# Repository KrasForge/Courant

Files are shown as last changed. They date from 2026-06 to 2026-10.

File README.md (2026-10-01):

# RADIAN

<p align="center">
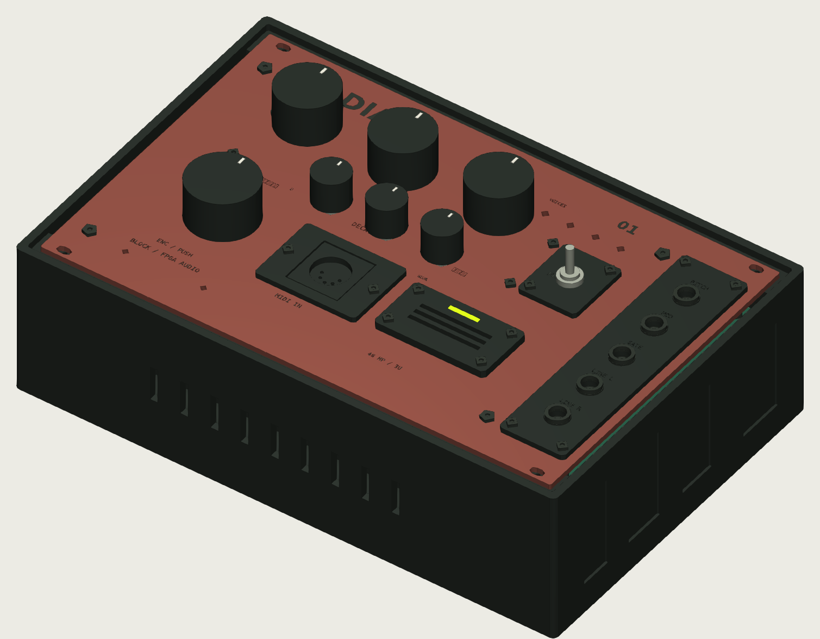
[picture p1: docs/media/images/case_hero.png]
RADIAN desktop instrument: six knobs, push encoder, MIDI DIN and five patch jacks on a red front panel in a black case
  
</p>

<p align="center">
  <a href="#listen"><b>Listen</b></a> ·
  <a href="#see-the-mesh-move"><b>See the mesh move</b></a> ·
  <a href="#the-hardware"><b>Hardware & 3D</b></a> ·
  <a href="#1-mathematical-foundation"><b>The maths</b></a> ·
  <a href="#4-architecture"><b>Architecture</b></a>
</p>

A 2D finite-difference physical-modeling synthesis engine in structural VHDL,
with an amplitude-dependent non-linear "chaos injection" term, playable
polyphonically over MIDI or CV.

Instead of recording or sampling an instrument, RADIAN solves the 2D acoustic
wave equation in real time on an FPGA mesh of arithmetic cells and streams the
result out as stereo audio: a vibrating drum head, a plate, a sheet of metal,
*computed* rather than recorded. A non-linear tension term makes the mesh
stiffen under load, so hard hits bend pitch upward and bloom into inharmonic,
metallic partials before settling into a natural decay. Notes arrive over MIDI
or control voltage, are allocated across independent polyphonic voices, and are
shaped by recallable instrument presets and a live front panel.

<sub>RADIAN was developed as **Courant**, which is why the repository and
some file paths still use that name.</sub>

> **Status: simulation-first, feature-complete in simulation, pre-hardware.**
> The engine, a Q1.23 reference model that is *bit-exact* to the RTL, and a full
> playable top (MIDI/CV $\rightarrow$ polyphony $\rightarrow$ I2S audio) are
> developed and verified under the current RTL regression across 31 testbenches. Board bring-up on a
> Digilent Arty A7 + Pmod I2S2 is the next step; nothing is claimed to work on
> hardware until it does.

---

## Listen

These clips come **out of the RTL**. A cycle-accurate Verilator build of
`synth_top` (4 voices, 8 $\times$ 8 mesh, 4$\times$ oversampling,
time-multiplexed) receives the score as bit-level serial MIDI at 31250 baud.
The note mapping, voice allocation, polyphonic meshes, mixer, DC blocker,
clock-domain crossing and I2S serialiser all run in it, and its 24-bit I2S
output is captured. Each clip gets one constant gain to peak at −1 dBFS. There
is no EQ, compression, reverb or editing. **They are not hardware
recordings**: the FPGA has not been brought up yet. Click a spectrogram or a ▶
link and the clip plays in your browser.

| Clip | What you hear | Listen |
| --- | --- | --- |
| **Gong Chorale** | A-minor chord progression on the gong preset. 3–4 voices ring into each other | [▶ `rtl_gong_chorale.mp3`](https://cdn.jsdelivr.net/gh/KrasForge/Courant@a1daff8e3a3599e712c28fc31fcfe1d983a12df5/docs/media/audio/rtl_gong_chorale.mp3) · 13 s |
| **Chaos Swell** | One held gong chord while CHAOS is turned up live over the control bus and back down | [▶ `rtl_chaos_swell.mp3`](https://cdn.jsdelivr.net/gh/KrasForge/Courant@a1daff8e3a3599e712c28fc31fcfe1d983a12df5/docs/media/audio/rtl_chaos_swell.mp3) · 12 s |
| **Plate Arpeggio** | Rolling pentatonic arpeggios on the plate preset with overlapping held notes, 112 BPM | [▶ `rtl_plate_arpeggio.mp3`](https://cdn.jsdelivr.net/gh/KrasForge/Courant@a1daff8e3a3599e712c28fc31fcfe1d983a12df5/docs/media/audio/rtl_plate_arpeggio.mp3) · 11 s |
| **Mallet Groove** | Marimba-like line on the damped drum preset over a held bass, 120 BPM | [▶ `rtl_mallet_groove.mp3`](https://cdn.jsdelivr.net/gh/KrasForge/Courant@a1daff8e3a3599e712c28fc31fcfe1d983a12df5/docs/media/audio/rtl_mallet_groove.mp3) · 10 s |
| **Berlin Voltage** | Dry EBM / industrial pulse, 132 BPM | [▶ `rtl_berlin_voltage.mp3`](https://cdn.jsdelivr.net/gh/KrasForge/Courant@f79031551d7316b354aa7c6243a771c9426d3952/docs/media/audio/rtl_berlin_voltage.mp3) · 10 s |
| **Oxide Dub** | Free-boundary metallic dub with long tails, 96 BPM | [▶ `rtl_oxide_dub.mp3`](https://cdn.jsdelivr.net/gh/KrasForge/Courant@f79031551d7316b354aa7c6243a771c9426d3952/docs/media/audio/rtl_oxide_dub.mp3) · 10 s |
| **Kreuz Rhythm** | Metallic polyrhythm with a tense finish, 150 BPM | [▶ `rtl_kreuz_rhythm.mp3`](https://cdn.jsdelivr.net/gh/KrasForge/Courant@f79031551d7316b354aa7c6243a771c9426d3952/docs/media/audio/rtl_kreuz_rhythm.mp3) · 10 s |

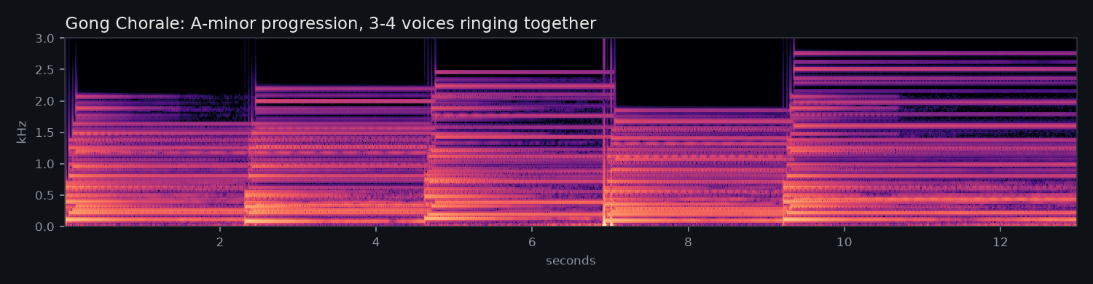
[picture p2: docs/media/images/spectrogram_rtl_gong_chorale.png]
Gong Chorale spectrogram

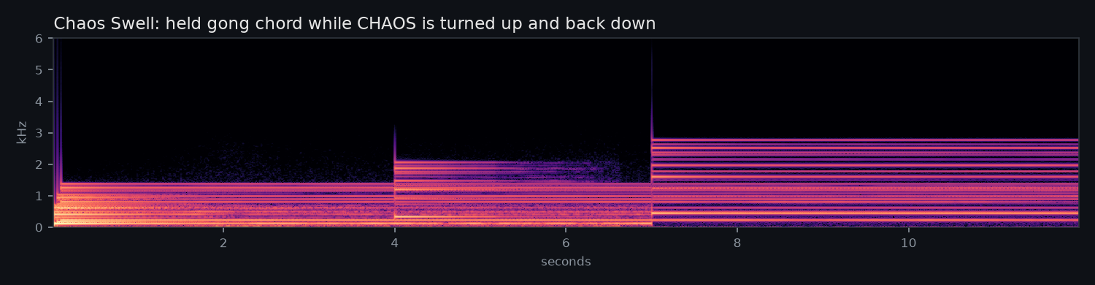
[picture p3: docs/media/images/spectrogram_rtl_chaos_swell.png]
Chaos Swell spectrogram: the band smears while CHAOS is up, then turns clean again

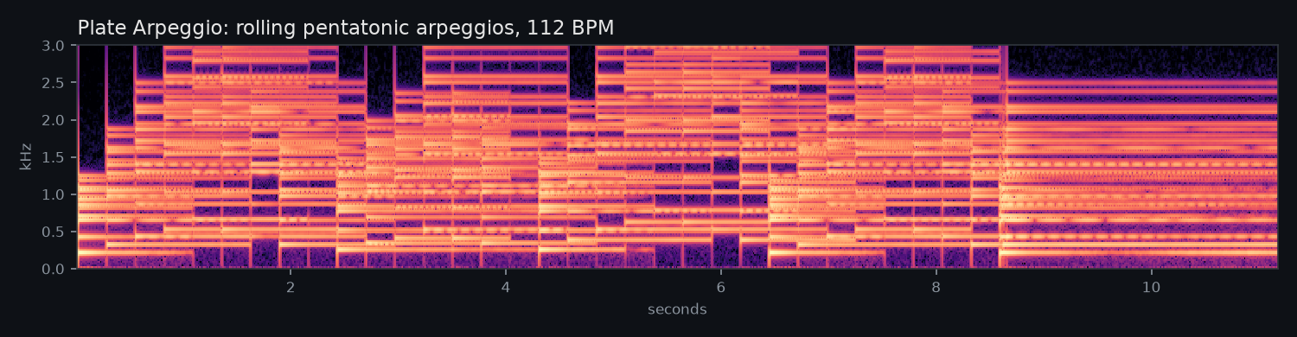
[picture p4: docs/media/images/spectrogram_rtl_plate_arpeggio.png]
Plate Arpeggio spectrogram

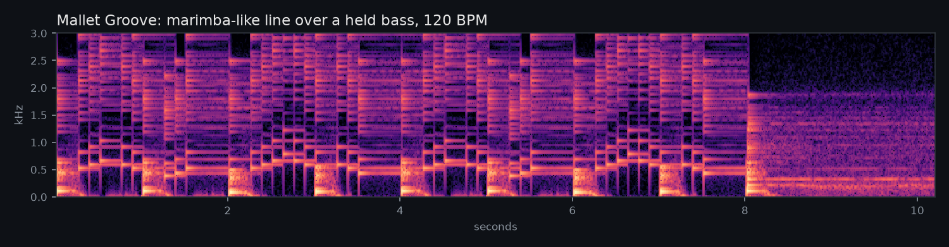
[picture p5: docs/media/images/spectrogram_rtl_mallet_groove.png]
Mallet Groove spectrogram


<sub>Rendered from the repaired RTL of 2026-09-16, the build behind
[`docs/sound_engine_repair.md`](docs/sound_engine_repair.md). It predates the
FX chain (drive, delay, chorus, reverb), the physical mallet and plate
stiffness, so these clips are the dry resonator. The scores are in
[`docs/media/scores/`](docs/media/scores/), and
[`make_scores.py`](docs/media/scripts/rtl/make_scores.py) writes the first
four. Rebuild the renderer from the
current RTL with
[`docs/media/scripts/rtl/build_renderer.sh`](docs/media/scripts/rtl/build_renderer.sh);
the whole 100 MHz system clock is simulated, so expect several minutes of CPU
per second of audio. Each clip also has an `.mp4` (spectrogram with a moving
playhead) in [`docs/media/audio/`](docs/media/audio/).</sub>

### Chaos off vs. chaos on

This one illustrates the non-linearity in the float reference model
([`model/NLMesh2D.m`](model/NLMesh2D.m), the same update as the RTL) on a
32 $\times$ 32 mesh. The same centre strike on the same gong mesh, first linear
($\alpha = 0$), then with chaos injection ($\alpha = 0.42$). The linear mesh
rings as a clean stack of fixed modes. With the amplitude-dependent term,
energy smears across the band right after the hit and the partials bend as the
mesh relaxes.

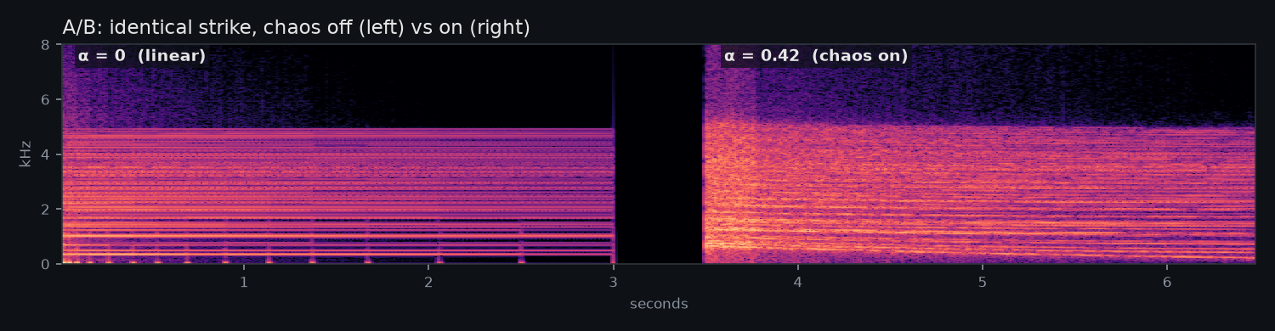
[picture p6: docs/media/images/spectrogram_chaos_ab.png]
A/B spectrogram: identical strike, linear vs chaos injection


The flat ceiling near 5 kHz is not a filter. It is the highest mode a 2D
mesh can carry, $f_{\max} = \tfrac{f_s}{\pi}\arcsin(\gamma\sqrt{2}) \approx 4.9$ kHz
for this gong's $\gamma^2 = 0.05$. A finer mesh for the same pitch raises
$\gamma$ and lifts it.

### See the mesh move

The same hard strike on both meshes, slowed down about 800 $\times$. On the
left the wavefront spreads at one speed. On the right the loud centre
stiffens, so it runs ahead and breaks into fine, high-frequency ripples:
those ripples are the inharmonic partials you hear.

<p align="center">
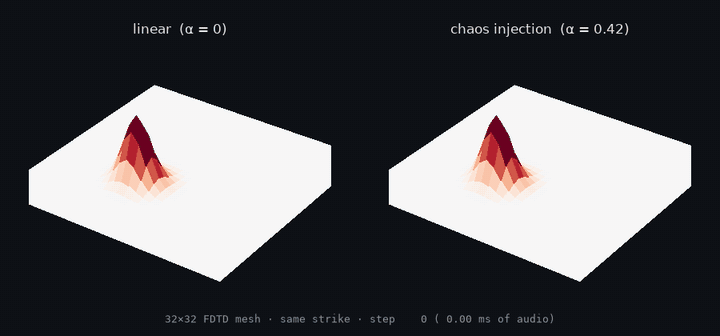
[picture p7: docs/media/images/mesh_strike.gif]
Animated 32x32 FDTD mesh after a strike: linear vs chaos injection
  
</p>

---

## The hardware

The engine targets a two-board desktop/Eurorack instrument. A 160 $\times$ 100 mm,
six-layer **Artix-7 mainboard** (FPGA, flash, clocks, PCM5102A DAC, CV/pot ADC,
opto-isolated MIDI) carries a **panel/interface board** 19.99 mm above it on
two 20-pin Samtec mezzanines. The panel has six knobs (TENSION · DECAY ·
CHAOS large, DRIVE · DELAY · REVERB small), a push encoder, the MODE switch,
four LEDs and five patch jacks. Neither board has been fabricated yet. See
[`hardware/CURRENT_DESIGN.md`](hardware/CURRENT_DESIGN.md) for what is and is
not validated.

<p align="center">
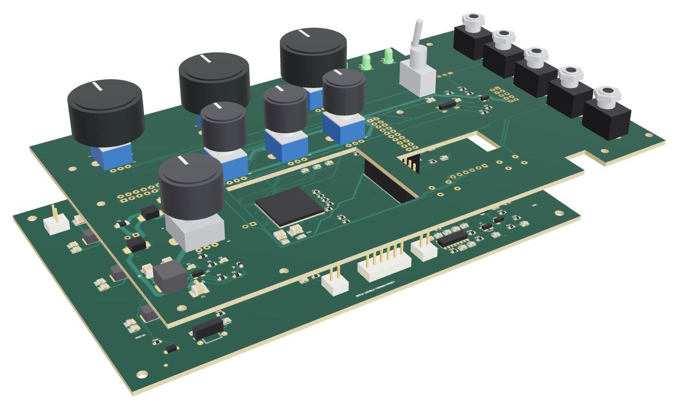
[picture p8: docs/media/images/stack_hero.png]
RADIAN board stack: the six-knob panel/interface board mated 20 mm above the Artix-7 mainboard
  <br>
  <sub>The two boards out of the case: the panel/interface board mated 19.99 mm above the Artix-7 mainboard.</sub>
</p>

<p align="center">
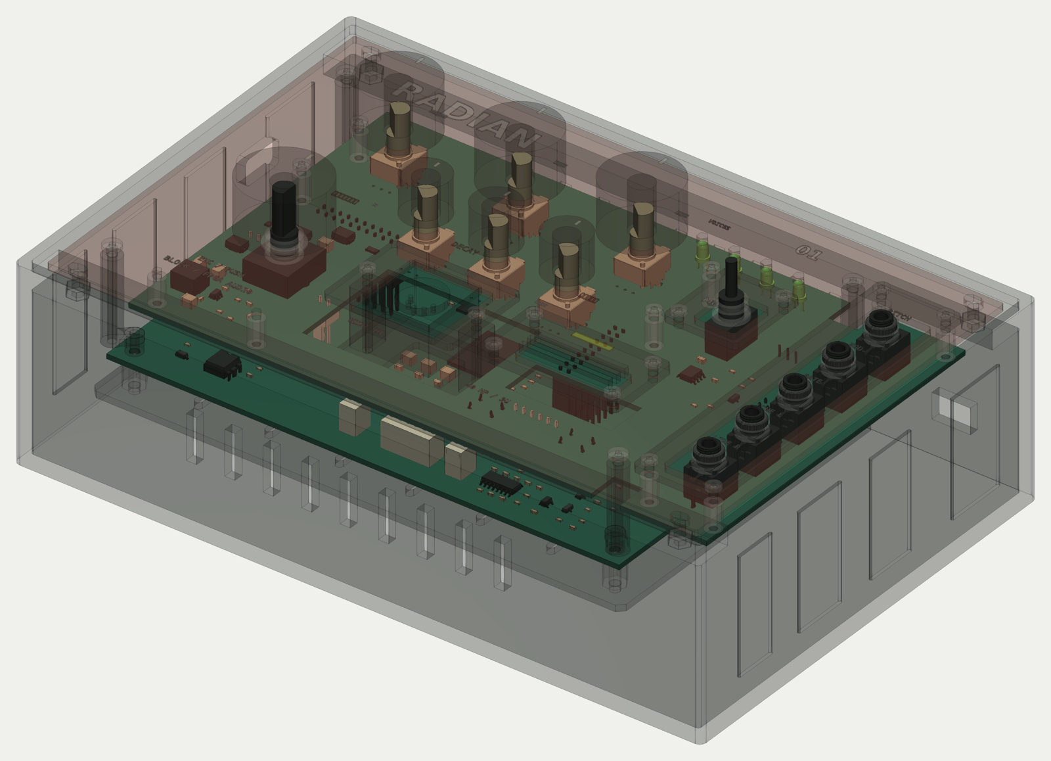
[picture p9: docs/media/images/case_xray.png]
See-through render of the RADIAN case showing both boards, knobs and jacks inside
  <br>
  <sub>See-through view of the desktop case with both boards and the actual-part 3D models inside, rendered from
  the STEP assembly described in <a href="hardware/CURRENT_DESIGN.md"><code>hardware/CURRENT_DESIGN.md</code></a>
  (the STEP files themselves are not committed). The case has not been built yet.</sub>
</p>

| Mainboard (top) | Panel / interface board (front) |
| --- | --- |
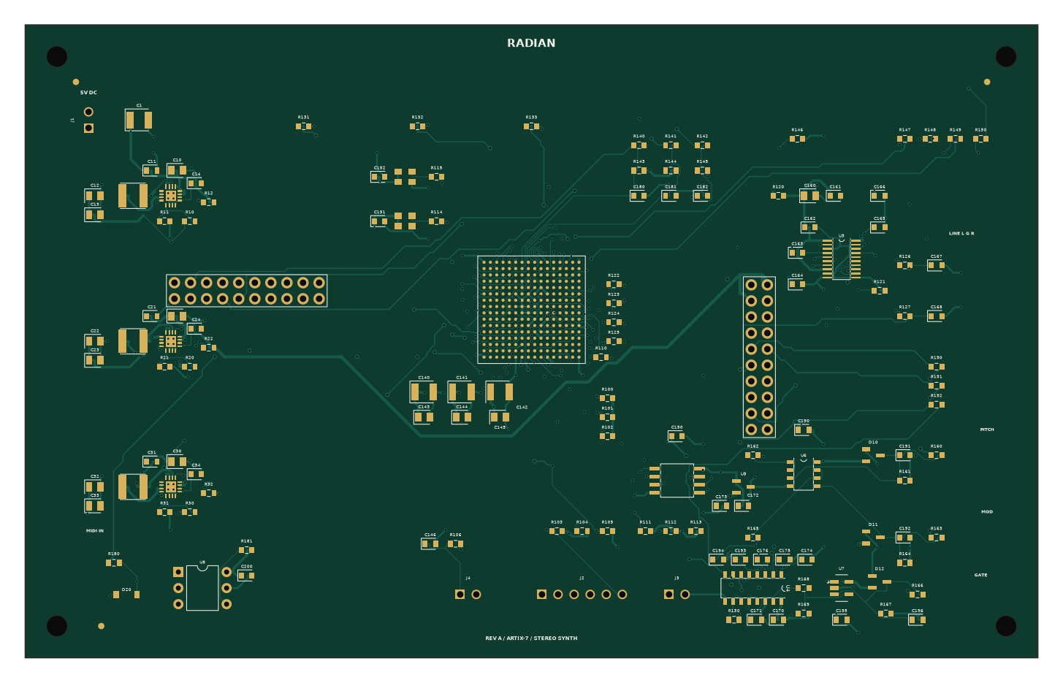
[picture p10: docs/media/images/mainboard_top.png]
Mainboard top view rendered from the native KiCad board
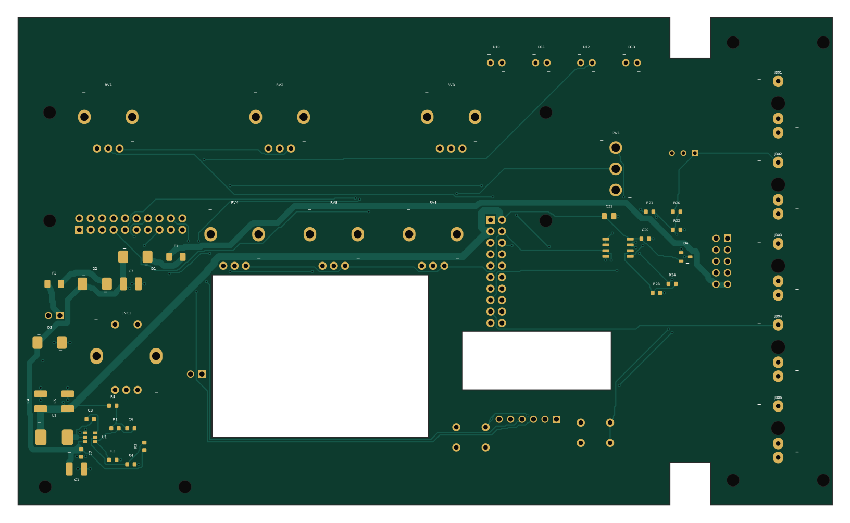
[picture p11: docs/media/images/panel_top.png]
Panel board front view rendered from the native KiCad board
|  |  |
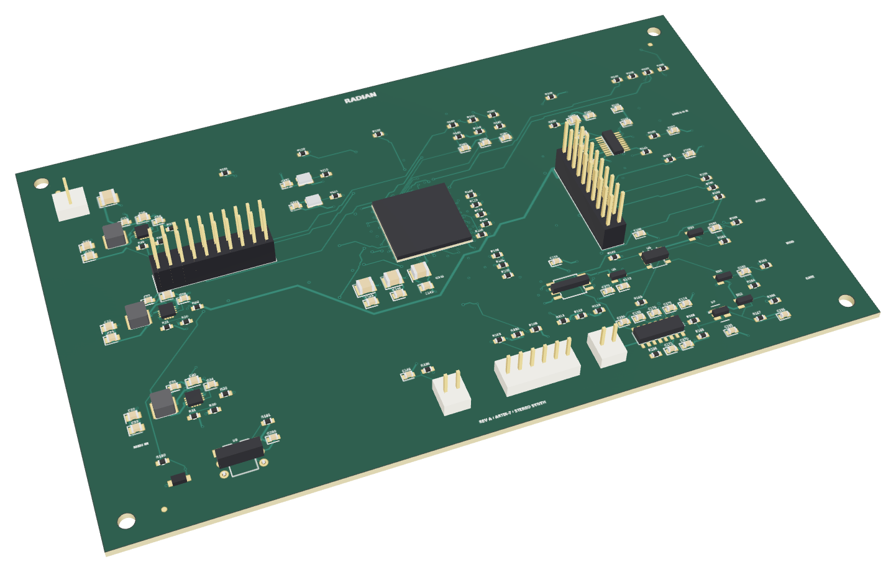
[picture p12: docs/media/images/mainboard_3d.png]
Mainboard 3D view
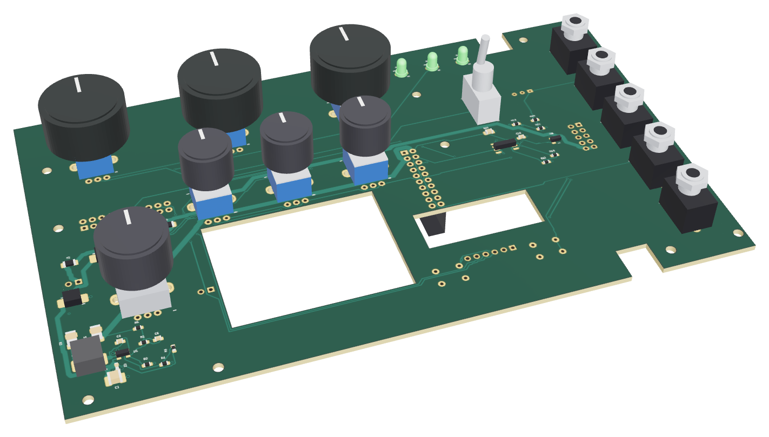
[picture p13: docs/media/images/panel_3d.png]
Panel board 3D view
|  |  |

<p align="center">
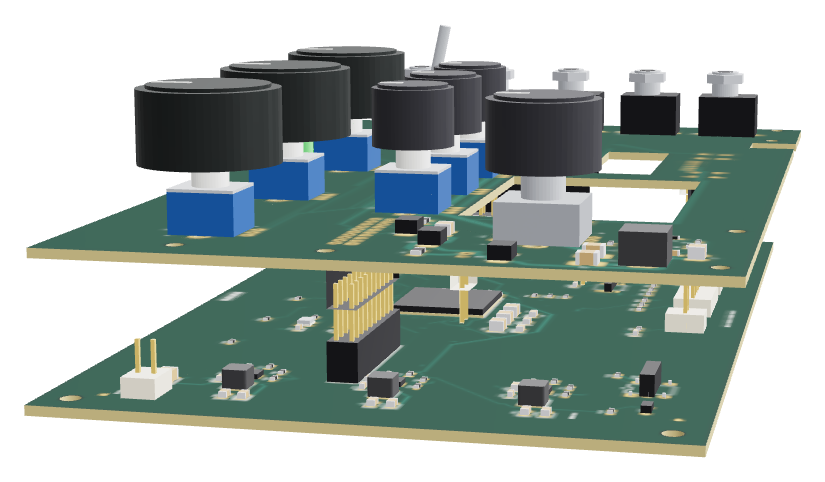
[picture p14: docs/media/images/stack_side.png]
Side view: Samtec terminal strips on the mainboard reaching into the panel sockets
  <br>
  <sub>Side view of the stack. The mainboard's Samtec IPT1 posts reach into the panel's IPS1 sockets; the FPGA shows through the panel window.</sub>
</p>

**Open the 3D model:** [`courant_stack.stl`](docs/media/3d/courant_stack.stl)
opens in GitHub's built-in 3D viewer, so you can orbit it in the browser. The
coloured glTF files ([stack](docs/media/3d/courant_stack.glb),
[mainboard](docs/media/3d/courant_mainboard.glb),
[panel](docs/media/3d/courant_panel.glb)) open in any glTF viewer, Blender, or
https://gltf-viewer.donmccurdy.com.

<sub>Every outline, drill, pad, track and component position is read straight
from the native KiCad 10 boards. Component bodies are simplified parametric
stand-ins sized from package datasheets, and the knobs are illustrative. The
full actual-part STEP assembly lives outside the repo, so treat these as
layout previews, not mechanical CAD. Regenerate everything with
[`docs/media/scripts/make_media.sh`](docs/media/scripts/make_media.sh).</sub>

---

## Why an FPGA

A 2D mesh is embarrassingly parallel: every node runs the *same* small update
every time step, reading only its four neighbours. That maps naturally onto FPGA
fabric, where many nodes update concurrently and the per-sample cost does not
grow the way a sequential `for`-loop over the grid does on a CPU.

The honest trade is real, and this README states it plainly rather than selling
a fantasy:

| Aspect | Software (CPU / plugin) | This FPGA engine |
| --- | --- | --- |
| **Grid scaling** | Sequential per node; cost grows with node count | Concurrent nodes; one mesh step per audio sample, independent of node count (up to the fabric's DSP/LUT budget) |
| **Latency** | Governed by the host audio buffer (roughly 0.7 to 6 ms typical) | Deterministic, sub-sample; no block buffering. Group delay through the model is the physical wave propagation itself |
| **Per-node non-linearity** | Often simplified or dropped to save CPU | Evaluated on every node, every step |
| **Iteration speed** | Edit, recompile in seconds | Requires re-synthesis (minutes); behaviour bounded by chosen fabric |
| **Cost / footprint** | Runs on hardware you already own | Needs an FPGA plus an audio codec; each extra voice consumes finite DSP/LUT |

FPGAs win on **deterministic parallelism and latency**. Software wins on
**flexibility and cost**. This project is about the former.

---

## 1. Mathematical foundation

The engine models a lossy 2D wave equation for the transverse displacement
$u(x, y, t)$ of the surface:

$$\frac{\partial^2 u}{\partial t^2} = c^2\left(\frac{\partial^2 u}{\partial x^2} + \frac{\partial^2 u}{\partial y^2}\right) - 2\sigma\frac{\partial u}{\partial t}$$

- $c$ is the wave propagation speed (sets pitch and tension);
- $\sigma$ is the frequency-independent damping (sets decay time).

### Discretisation

Using centred finite differences on a grid with spacing $h$ and time step
$k = 1/f_s$ (with $f_s$ the audio rate, e.g. 48 kHz), the explicit update for
node $(i, j)$ is:

$$u_{i,j}^{n+1} = \frac{1}{1+\sigma k}\left[\,2u_{i,j}^{n} - (1-\sigma k)\,u_{i,j}^{n-1} + \gamma^2\left(u_{i+1,j}^{n} + u_{i-1,j}^{n} + u_{i,j+1}^{n} + u_{i,j-1}^{n} - 4u_{i,j}^{n}\right)\right]$$

where $\gamma = ck/h$ is the **Courant number**. The bracketed Laplacian stencil
is the only inter-node coupling; everything else is local. In the RTL the two
damping coefficients are precomputed on the control bus,

$$a_0 = \frac{1}{1+\sigma k}, \qquad \mathrm{sigk1} = 1 - \sigma k,$$

so no node ever performs a division (division is expensive in fabric; this
avoids it entirely).

### Stability (CFL), and why it is the whole game here

An explicit 2D scheme is only stable when the Courant number satisfies

$$\gamma^2 \le \tfrac{1}{2}\qquad\left(\gamma \le \tfrac{1}{\sqrt 2}\approx 0.7071\right).$$

Cross that line and the scheme does not merely "sound bad," it diverges
**exponentially**. This constraint governs every design decision in the next
section.

---

## 2. The non-linear twist: chaos injection

A linear mesh with a constant $\gamma$ is predictable and, frankly, a bit
sterile. RADIAN makes the local Courant term **amplitude-dependent**, so the
mesh stiffens where it is moving hardest:

$$\gamma_{i,j}^2 = \gamma_0^2 + \alpha\,(u_{i,j}^{n})^2$$

- $\gamma_0^2$ is the base stiffness and pitch;
- $\alpha$ is the chaos coupling.

High-amplitude regions momentarily raise the local wave speed, bending the
wavefront, shifting pitch up, and bleeding energy into inharmonic partials. This
is the characteristic "tension modulation" of struck plates and gongs, including
genuine period-doubling routes into chaos.

### The catch (and the fix)

The term $\alpha u^2$ only ever *increases* $\gamma^2$, and it does so hardest
exactly when the sound is loudest, pushing toward the CFL boundary precisely when
you least want it to. Naively, a hard hit drives $\gamma^2 > 1/2$ and the mesh
blows up. **Output saturation alone does not save you**: it clamps the
*displayed* sample while the internal state pins to the rails and buzzes at
Nyquist. You get a brick, not a gong.

The fix is structural, and is treated here as a first-class part of the design
rather than an afterthought:

1. **Clamp the local term:**
   $\gamma^2_{i,j} = \mathrm{clamp}(\gamma_0^2 + \alpha u^2,\ 0,\ \gamma^2_{\max})$
   with $\gamma^2_{\max} < 1/2$ (a safety margin below the CFL limit). This
   bounds the instability into a limit-cycle / soft-clip regime that is chaotic
   and rich, but convergent.
2. **Saturating state arithmetic:** displacement is clamped to the Q1.23 range,
   turning blow-up energy into musical soft saturation instead of wrap-around.
3. **Guaranteed decay:** the damping term $\sigma$ ensures the linear regime
   always returns to rest.

### Aliasing, stated rather than hidden

A squaring non-linearity at the base sample rate generates harmonics above
Nyquist that fold back as aliasing. "Zero aliasing" would be a false claim for
any non-linear scheme. The mitigation is **oversampling**: run the mesh at an
integer multiple of $f_s$ (the FPGA has ample clock headroom) and decimate on
output. The oversampling factor `OS` is a documented quality / area knob, not
magic; see [`docs/oversampling.md`](docs/oversampling.md).

---

## 3. Numerics

| Property | Value |
| --- | --- |
| Format | Signed **Q1.23** (24-bit two's complement) |
| Range / resolution | $[-1.0, +1.0)$ / $2^{-23}\approx 1.19\times 10^{-7}$ |
| Multiply | Q1.23 $\times$ Q1.23 gives Q2.46, rescaled by a `>>23` shift with round-to-nearest, saturated |
| Accumulation | Wide 48-bit guard accumulator, saturated on store |
| Coefficients | $a_0$ and $\mathrm{sigk1}$ precomputed on the control bus, so there is no per-node division |
| Overflow | Saturating arithmetic throughout: graceful soft-clip, never wrap-around spikes |

All fixed-point helpers (`sat_q123`, the rounding multiply, the clamp) live in
[`src/rtl/fdtd_pkg.vhd`](src/rtl/fdtd_pkg.vhd) and are exercised bit-for-bit
against the reference model (section 6).

---

## 4. Architecture

```
 MIDI / CV --> note mapping --.                     .--> I2S TX --> codec (DAC)
                              v                     |
   preset bank --> coeffs --> poly voices (N meshes + mix) --> CDC --> (audio clk)
                              ^                     |
        panel knobs/encoder --'   sample strobe <--'  (I2S word clock -> frame)
```

### Node Processing Element (PE)

Each node ([`node_element.vhd`](src/rtl/node_element.vhd)) owns:

- **State registers** holding $u^n$ and $u^{n-1}$;
- **A pipelined Q1.23 datapath** for the update above (Laplacian, the
  $\alpha u^2$ term, the $\gamma^2_{\max}$ clamp, the bracket, and the $a_0$
  scale), mapped to DSP slices;
- **Nearest-neighbour wiring** (N/S/E/W). Edge nodes use **fixed** ($u = 0$,
  Dirichlet) or **free** (mirrored, Neumann) boundaries.

### Spatial vs. time-multiplexed: the real engineering choice

A *fully spatial* mesh instantiates one PE per node. That is $O(N^2)$ DSP slices
and hits a hard ceiling fast: a 32$\times$32 mesh with a couple of multipliers
per node is well over a thousand DSPs, beyond most mid-range parts. The two
honest options, selected at synthesis time via the `mesh` wrapper and the
`TIME_MUX` generic:

- **Fully spatial** ([`grid_mesh.vhd`](src/rtl/grid_mesh.vhd)): small mesh on a
  large FPGA. Lowest latency, biggest area.
- **Time-multiplexed** ([`grid_mesh_tdm.vhd`](src/rtl/grid_mesh_tdm.vhd)): fold
  the grid through a single shared PE. At 100 MHz over 48 kHz there are roughly
  2083 system-clock cycles per audio sample, plenty to sweep a modest grid
  through one pipeline and still finish within a sample period. This costs
  ~18 DSP per voice *independent of grid size*, and it is the only way
  polyphony fits a small device.

Same RTL, a synthesis-time trade, documented per target in
[`docs/resource_budget.md`](docs/resource_budget.md).

### "Single cycle" and "zero latency": what is actually true

The per-node update is a multi-stage pipeline (multiplies, the clamp, the final
scale), not a single combinational clock edge. What *is* true:

- **One mesh time-step per audio sample:** the mesh advances on each sample
  strobe;
- **No audio-buffer latency:** there is no DAW block to fill, so end-to-end
  latency is sub-sample and deterministic, dominated by the codec and the PE
  pipeline depth (nanoseconds to microseconds), not milliseconds.

### Clocking and clock-domain crossings

The design spans two clock domains:

| Domain | Clock | Contents |
| --- | --- | --- |
| System | `sys_clk` (e.g. 100 MHz) | MIDI/CV front-ends, preset bank, polyphony (the mesh) |
| Audio | I2S `bclk` (divided from `mclk`) | I2S transceiver |

[`i2s_clkgen.vhd`](src/rtl/i2s_clkgen.vhd) makes the FPGA the **I2S master**:
from an audio master clock `mclk` (e.g. 12.288 MHz from an MMCM) it generates
MCLK / BCLK / LRCLK for the codec. [`sample_strobe.vhd`](src/rtl/sample_strobe.vhd)
crosses LRCLK back into `sys_clk` as the per-frame pulse that advances the mesh
one step per audio sample. Only two data crossings exist, both verified
primitives: a two-flop synchroniser on the async serial MIDI input, and the
stereo pickup word crossing `sys_clk` $\rightarrow$ `bclk` through
[`cdc_word.vhd`](src/rtl/cdc_word.vhd) (an MCP handshake). See
[`docs/cdc.md`](docs/cdc.md).

---

## 5. Playability

The engine is wrapped into a complete, flashable instrument
([`synth_top.vhd`](src/rtl/synth_top.vhd), board wrapper
[`syn/vivado/arty_synth.vhd`](syn/vivado/arty_synth.vhd)).

- **MIDI** ([`midi_frontend.vhd`](src/rtl/midi_frontend.vhd) over
  [`midi_uart_rx.vhd`](src/rtl/midi_uart_rx.vhd)): parses the 31250-baud serial
  stream, maps note number through a discrete-mesh calibrated pitch table, and
  maps velocity to strike amplitude only. CHAOS is an independent panel/CV
  control. See [`docs/midi.md`](docs/midi.md).
- **Control voltage** ([`cv_frontend.vhd`](src/rtl/cv_frontend.vhd)): the same note-mapping interface, driven from 1V/oct pitch, a gate, and a mod CV. MIDI/CV arbitration is normally automatic: the newest MIDI note-on or CV gate edge claims the source. Presets/registers can force MIDI or CV, while the legacy `cv_sel` port remains only as a force-CV/debug override. See [`docs/cv.md`](docs/cv.md).
- **Polyphony** ([`poly_voices.vhd`](src/rtl/poly_voices.vhd) +
  [`voice_allocator.vhd`](src/rtl/voice_allocator.vhd)): allocates each note to
  a free voice, runs `NVOICES` independent meshes, and averages their stereo
  pickups. With `TIME_MUX` the voices fold onto shared PEs so polyphony fits a
  small part. See [`docs/polyphony.md`](docs/polyphony.md).
- **Presets** ([`preset_bank.vhd`](src/rtl/preset_bank.vhd)): supplies TENSION, DECAY, CHAOS, the CFL clamp, **STIFFNESS / plate dispersion**, **HARDNESS / stateful physical mallet**, pickup geometry, RIM compliance, STRIKE SIZE/X/Y, MATERIAL/ANISO/CHARACTER and source override. Voice-relevant settings are latched into each newly struck voice. See [`docs/presets.md`](docs/presets.md).
- **Front panel** ([`panel_ctrl.vhd`](src/rtl/panel_ctrl.vhd)): the existing MODE switch is PLAY/EDIT. PLAY keeps TENSION/DECAY/CHAOS/DRIVE/DELAY/REVERB and encoder preset navigation; EDIT reuses the encoder to select soft-takeover parameter pages, with SURFACE currently mapping ANISO/RIM/STRIKE SIZE/STRIKE X/STRIKE Y/CHARACTER. The four LEDs show voices in PLAY and the selected page in EDIT. No new pot, ADC channel, connector or PCB signal is required. See [`docs/panel.md`](docs/panel.md).

The end-to-end path (MIDI/CV $\rightarrow$ note mapping $\rightarrow$ preset
merge $\rightarrow$ polyphonic meshes $\rightarrow$ CDC $\rightarrow$ I2S) is
described in [`docs/synth_top.md`](docs/synth_top.md).
The 2026-09-16 musical calibration/quality repair and acceptance results are in [`docs/sound_engine_repair.md`](docs/sound_engine_repair.md).

---

## 6. The reference model (bit-exact)

[`model/`](model/) holds a MATLAB/Octave reference implementation used both to
explore the physics and to *lock the RTL numerically*. The linear
([`Mesh2D.m`](model/Mesh2D.m)), stiff ([`StiffMesh2D.m`](model/StiffMesh2D.m)),
spatially-varying ([`VarMesh2D.m`](model/VarMesh2D.m)) and non-linear
([`NLMesh2D.m`](model/NLMesh2D.m)) meshes each have a study script (stability,
chaos, exciters, oversampling, materials). Crucially,
[`nl_reference.m`](model/nl_reference.m) regenerates the legacy nonlinear Q1.23 golden trace, while [`stiffness_reference.py`](model/stiffness_reference.py) and [`mallet_reference.py`](model/mallet_reference.py) independently regenerate the production fixed-point STIFFNESS and physical-mallet/HARDNESS traces. Their testbenches replay those traces step for step, so the corresponding hardware paths are verified **bit-exact** to independent models rather than merely "close." [`demo_render.m`](model/demo_render.m) renders musical, nonlinear, polyphonic demo audio.

---

## 7. Repository structure

```text
src/
  rtl/     Q1.23 package + node PE, spatial & time-mux meshes and selector,
           I2S transceiver + master clock gen + sample strobe, cdc_word,
           MIDI + CV front-ends, voice allocator + polyphony, preset bank,
           panel controller, control bus, synth_top (the playable design)
  tb/      31 RTL testbenches: unit (node, fdtd_pkg, i2s, cdc, uart, mallet) ->
           bit-exact golden traces (nl_mesh, mesh_impulse, boundary, pickup) ->
           end-to-end audio (synth_top, poly, preset_top, latency)
model/     MATLAB/Octave reference model (bit-exact to the RTL) + physics
           studies (stability, chaos, stiffness, spatial, exciters) + demos
sim/       GHDL Makefile: `make -C sim` analyses and runs the whole suite
syn/       yosys (open-source resource estimate) and Vivado (sign-off) flows,
           the Arty A7 + Pmod I2S2 constraints, and the board wrapper arty_synth
docs/      derivations, fixed-point + CFL analysis, per-feature notes
           (midi, cv, polyphony, presets, panel, cdc, oversampling, timing),
           the resource budget, and a deviations log
  media/   README sound demos, spectrograms, board renders, 3D models (.glb/.stl)
           and the scripts that regenerate them from model/ and hardware/
hardware/  native KiCad 10 mainboard (courant/) and panel/interface board
           (panel/), the shared direct-stack contract (stack/)
```

---

## 8. Building & simulating

The reference flow uses **GHDL** (open-source, VHDL-2008):

```sh
make -C sim                      # analyse + elaborate + run all 31 testbenches
octave-cli --eval "demo_render"  # render nonlinear polyphonic demo audio (model/)
docs/media/scripts/rtl/build_renderer.sh build  # cycle-accurate RTL audio renderer (Verilator)
docs/media/scripts/make_media.sh # regenerate README audio, spectrograms, PCB renders, 3D models
cd syn/yosys && ./report_util.sh # DSP / LUT / FF resource estimate (yosys)
```

A single unit test can be run directly, e.g.

```sh
ghdl -a --std=08 src/rtl/fdtd_pkg.vhd src/rtl/node_element.vhd src/tb/node_element_tb.vhd
ghdl -r --std=08 node_element_tb --wave=sim/node.ghw
```

---

## 9. Target hardware and resources

Synthesis targets a low-cost dev board for bring-up: a **Digilent Arty A7**
(Xilinx Artix-7) with a **Pmod I2S2** codec, keeping the path to real audio
cheap and reproducible. The FPGA is the I2S master; the constraints live in
[`syn/vivado/arty_synth.xdc`](syn/vivado/arty_synth.xdc). The Vivado non-project
flow ([`build_synth.tcl`](syn/vivado/build_synth.tcl)) runs opt/place/route and
fails the build on negative slack (a pass/fail timing gate).

Beyond the dev board there is a **standalone instrument PCB** — a 160 x 100 mm
six-layer board carrying an XC7A50T, its configuration flash, both oscillators,
a PCM5102A stereo DAC, and the analog front end the Arty build leaves off (panel
pots and CV over an MCP3208, an opto-isolated MIDI input, a gate comparator).
It started in [tscircuit](https://tscircuit.com) and is now maintained as native
KiCad 10 boards in [`hardware/courant/`](hardware/courant/) (mainboard) and
[`hardware/panel/`](hardware/panel/) (panel/interface board); every device
pinout is checked against its manufacturer datasheet and the FPGA ball map
against AMD's own package file. Both boards are **fully routed but never
fabricated**: the mainboard has 2158 track segments, 4386 mm of copper and 299
vias, and KiCad DRC reports 0 violations / 0 unconnected on both boards. See
[`hardware/CURRENT_DESIGN.md`](hardware/CURRENT_DESIGN.md) and
[`docs/board.md`](docs/board.md) for what is and is not verified.

Using the time-multiplexed mesh (~18 DSP per voice, independent of grid size),
resources scale roughly linearly with voice count:

| Voices | DSP48 | LUT | Fits |
| --- | --- | --- | --- |
| 1 | ~24 | ~8.6k | A7-35T |
| 2 | ~38 | ~15.6k | A7-35T |
| 4 | ~74 | ~30.4k | A7-35T (90 DSP) |
| 8 | ~146 | ~61.6k | A7-100T (240 DSP) |

Numbers are from the open-source yosys flow; the yosys LUT figures are
pessimistic (a combinational-read mesh memory maps to LUT mux-trees, where
Vivado would infer LUTRAM/BRAM). Full table and caveats in
[`docs/resource_budget.md`](docs/resource_budget.md).

---

## 10. What this is and is not

- It **is** a deterministic, low-latency, parallel physical-modeling engine and
  an honest study of non-linear FDTD on FPGA, playable over MIDI and CV.
- It **is** simulation-first: nothing is claimed to "work on hardware" until it
  has. The RTL, the reference model, and the full playable top are complete and
  verified in simulation.
- It is **not** zero-latency, zero-aliasing, or single-clock-cycle. Those are
  marketing, and this document avoids them deliberately.
- It is **not** yet a hardware product. The standalone boards are routed and
  pass DRC, and the MCP3208 SPI reader for the panel / CV ADC
  ([`adc_mcp3208.vhd`](src/rtl/adc_mcp3208.vhd)) passes its testbench, but
  nothing has been fabricated or brought up yet.

---

## License

MIT.

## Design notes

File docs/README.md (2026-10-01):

# docs/

Design documentation for the RADIAN FDTD engine.

Contents:
- `derivation.md` — discretisation derivation: continuous PDE → explicit
  update; maps each symbol to [`model/Mesh2D.m`](../model/Mesh2D.m)
- `cfl_derivation.md` — von Neumann stability proof of `gamma^2 <= 1/2` and the
  chosen `gamma2_max = 0.451` margin; backed by
  [`model/stability_study.m`](../model/stability_study.m)
- `fixed_point_analysis.md` — Q1.23 quantization error budget, coefficient
  precision, rounding, accumulator guard bits, and M1 recommendations; backed
  by [`model/quantization_study.m`](../model/quantization_study.m)
- `deviations.md` — log of intentional deviations from the reference model,
  hardware-validation status, and the M0 fixed-point vs float table
- `synth_top.md` — end-to-end board top (MIDI → polyphony → I2S), datapath + clocking (issue #68)
- `resource_budget.md` — DSP/LUT estimates per target (spatial vs. time-multiplexed)
- `exciters.md` — physical mallet derivation + production HARDNESS/contact RTL; bow remains follow-up (issues #33/#87)
- `spatial_variation.md` — per-node/region coefficient maps study + go/no-go (issue #32)
- `materials_stiffness.md` — bending-stiffness / anisotropy derivation plus production STIFFNESS RTL integration (issues #31/#86)
- `presets.md` — preset format, factory presets, and how to author/load them
- `panel.md` — front-panel PLAY/EDIT controller: six soft-takeover knobs, encoder-selected edit pages and presets (issues #78/#85)
- `polyphony.md` — voice abstraction, allocation/stealing, and voice-count vs. cost
- `midi.md` — calibrated MIDI/CV pitch; velocity→strike; independent CHAOS
- `cv.md` — control-voltage front-end: 1V/oct pitch, gate strike, mod→timbre (issue #70)
- `codec_bringup.md` — Pmod I2S2 (CS5343/CS4344) clocking, wiring, and bring-up
- `board.md` — standalone Rev A instrument PCB: blocks, footprints, routing status
- `finishing_the_route.md` — (historical) the last six connections on the board, and
  how to close them in KiCad's interactive router
- `sound_engine_repair.md` — 2026-09-16 pitch/strike/CHAOS repair and RTL listening acceptance
- `media/` — README sound demos, spectrograms, board renders and 3D models, plus
  the scripts that regenerate them (`media/scripts/make_media.sh`)

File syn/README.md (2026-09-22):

# syn/ - synthesis flows

Two reproducible synthesis flows for the resonator, targeting the Digilent
Arty A7 (Xilinx Artix-7). Results and the resource budget are in
[`docs/resource_budget.md`](../docs/resource_budget.md).

## yosys (open source, no licence)

[`yosys/report_util.sh`](yosys/report_util.sh) maps the RTL onto Xilinx
7-series primitives (DSP48E1 / LUT / FF) and prints a per-unit utilisation
summary. This is the flow used to produce the numbers in the budget doc; it
runs anywhere.

```sh
sudo apt-get install yosys yosys-plugin-ghdl ghdl
cd syn/yosys && ./report_util.sh
```

(`grid_mesh` / `top_resonator` synthesise at the default `NX=NY=8`; DSP/LUT/FF
scale linearly with `NX*NY`.)

## Vivado (sign-off)

[`vivado/build_arty.tcl`](vivado/build_arty.tcl) is a non-project flow that
synthesises **and implements** (opt / place / route) `top_resonator` for a
chosen part and mesh size, then writes utilisation + post-route timing reports
and exits non-zero on negative slack (a pass/fail timing gate).
[`vivado/arty_a7.xdc`](vivado/arty_a7.xdc) constrains the 100 MHz system clock,
the I2S bit clock, the Pmod I2S2 audio pins, and the async clock-domain crossing
(false path + bounded bus skew on the `cdc_word` handshake). The full timing
closure rationale is in [`../docs/timing_closure.md`](../docs/timing_closure.md).

```sh
# Arty A7-35T, 2x2 mesh, 4x oversampling
vivado -mode batch -source build_arty.tcl -tclargs xc7a35ticsg324-1L 2 2 4
# Arty A7-100T, 3x3 mesh
vivado -mode batch -source build_arty.tcl -tclargs xc7a100tcsg324-1 3 3 4
# time-multiplexed build (one PE pool; fits larger grids)
vivado -mode batch -source build_arty.tcl -tclargs xc7a35ticsg324-1L 8 8 4 true
```

This produces `util_<tag>.rpt` and `timing_<tag>.rpt`.

## Building the playable synth (synth_top)

[`vivado/build_synth.tcl`](vivado/build_synth.tcl) builds the flagship playable
design, the board wrapper [`vivado/arty_synth.vhd`](vivado/arty_synth.vhd) around
`synth_top` (#68): MIDI in, polyphonic voices, I2S out. The wrapper adds an MMCM
that turns the 100 MHz oscillator into the system clock and the ~12.288 MHz audio
master clock, and maps the buttons/switches/LEDs and the Pmod I2S2 codec pins
([`vivado/arty_synth.xdc`](vivado/arty_synth.xdc)). The MMCM instantiation is a
synthesis-only Xilinx primitive, so `arty_synth.vhd` lives under `syn/` and is
not part of the (vendor-neutral) GHDL simulation flow; `synth_top` itself is
fully simulated in `src/tb/synth_top_tb.vhd`.

```sh
# Historical Arty A7-35T 4-voice time-multiplexed implementation check
vivado -mode batch -source build_synth.tcl -tclargs xc7a35ticsg324-1L 4 8 8 4 true
# Arty A7-100T, 8 voices
vivado -mode batch -source build_synth.tcl -tclargs xc7a100tcsg324-1  8 8 8 4 true
```

Same opt/place/route + pass/fail timing gate as `build_arty.tcl`. Current
refined 8x8 time-multiplexed surface-voice mapping is **18 DSP per voice** in the
open-source flow, including STIFFNESS and the #87 HARDNESS/contact path. The
stateful `physical_mallet` itself maps to **0 DSP**; the complete post-mesh FX
chain maps to **23 DSP**. These module figures are planning data, not a
substitute for the current full-top Vivado utilization/timing report; see
`docs/resource_budget.md`.

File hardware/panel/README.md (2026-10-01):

# RADIAN / PANEL P1 — direct-stack six-control revision

**One panel/interface PCB for the RADIAN FPGA mainboard. Engineering prototype; native electrical/PCB checks are clean, but physical hardware validation is still required.**

<p align="center">
  Panel/interface board, 3D preview
</p>

| Front (F.Cu) | Back (B.Cu, faces the mainboard) |
| --- | --- |
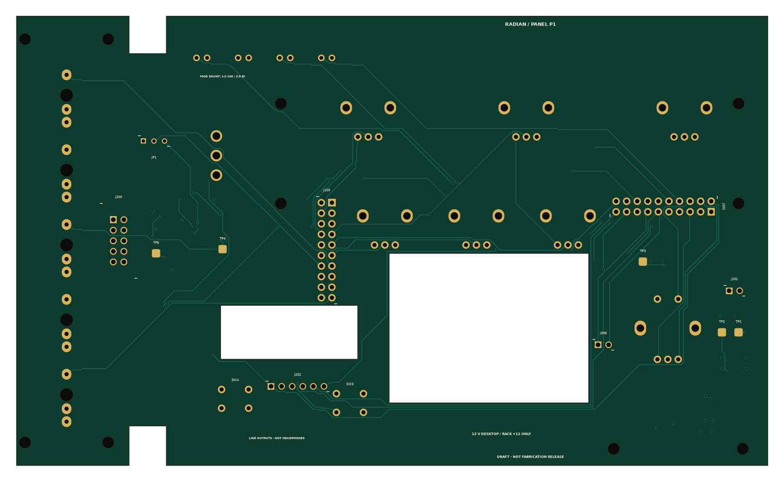
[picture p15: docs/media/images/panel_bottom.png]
Panel back
| Panel front |  |

<sub>Rendered from `design/radian_panel.kicad_pcb` by `docs/media/scripts/`. Component bodies in the 3D view are simplified stand-ins and the knobs are illustrative. See `docs/media/README.md`.</sub>

Open `design/radian_panel.kicad_pro` with KiCad 10 and keep the project-local symbols/footprints with it. The authoritative panel PCB passes native ERC, DRC, filled-zone connectivity and schematic/PCB parity with zero findings. Current review fabrication outputs are in `fab/` and `radian_panel-fab.zip`.

## Current architecture
- Four-layer panel PCB, 1.6 mm thick, about 180.5 × 108 mm, with DIN/ventilation reliefs.
- Six Bourns 10 kOhm pots: **TENSION · DECAY · CHAOS · DRIVE · DELAY · REVERB**.
- Push encoder, MODE switch, four LEDs and five vertical mono patch jacks.
- Rack +12 V and desktop 12 V feed the panel converter; the mainboard still receives regulated VIN5.
- Rack input remains a 10-pin module-side Eurorack connector; −12 V is unused.
- Default MOD bypass preserves the original unipolar behavior; the optional bipolar MOD path still requires firmware calibration.
- PITCH scaling and stereo line-level outputs are unchanged.

## Direct panel-to-mainboard connection
The old J101…J116 cable-header bundle is retired. The boards now connect directly through two 2×10, 2.54 mm mezzanine pairs:
- **J17 main ↔ J100 panel:** Samtec IPT1-110-06-L-D ↔ IPS1-110-01-L-D, carrying VIN5/GND/VREF25, six pot wipers, CV/gate and stereo audio.
- **J18 main ↔ J101 panel:** the same Samtec pair, carrying 3V3/GND, encoder, MODE, LEDs, MIDI, PROGRAM/RESET and JTAG.

The shared source of truth is `../stack/panel-stack.json`. It specifies 19.99 mm fully mated spacing, 20.45 mm maximum spacing and a ~20.0 mm support-stack target. Standoffs/supports carry structural load; the connectors are not structural fasteners.

The final native boards have 40/40 mating pins matched by net and assembled XY, with 1.02 mm mainboard drills and 1.04 mm panel drills. Exact connector MPNs are present in both BOMs. Real connector seating, retention and enclosure tolerance still require a physical first article.

## Case / enclosure
The retained desktop/Eurorack enclosure has been revised to match this panel. The old three macro holes are closed, six current control locations are present, MODE moves to (154, 57) mm, and the old raised MODE insert becomes the REVERB insert. The mainboard/support plane is shifted 0.46 mm for the 19.99 mm fully-mated Samtec stack. See `cad/RADIAN_P1_desktop_fit_study.step` and `reports/CASE_UPDATE.md`.

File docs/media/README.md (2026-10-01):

# docs/media/

Sound demos, board renders and 3D models used by the top-level README. Every
file here is generated. Change the scripts, not the outputs.

```sh
docs/media/scripts/make_media.sh
```

## What is here

| Path | Contents | Generated from |
| --- | --- | --- |
| `audio/rtl_*.mp3` | 10–13 s pieces captured from the RTL's I2S output (gong_chorale, chaos_swell, plate_arpeggio, mallet_groove, berlin_voltage, oxide_dub, kreuz_rhythm) | `scripts/rtl/build_renderer.sh` + `scores/*.txt` → `scripts/rtl_media.py` |
| `audio/chaos_ab.mp3` | One strike, $\alpha = 0$ then $\alpha = 0.42$ | `scripts/mesh_media.py` |
| `scores/*.{txt,json}` | Bit-level serial-MIDI stimulus and a summary of each RTL score | 01–03 from the 2026-09-16 sound repair; 04–07 from `scripts/rtl/make_scores.py` |
| `audio/*.mp4` | Spectrogram + moving playhead + audio. Drag one into a GitHub comment or the web editor to get an inline player | `scripts/mesh_media.py` |
| `images/spectrogram_*.png` | Spectrogram per clip | `scripts/mesh_media.py` |
| `images/mesh_strike.gif` | 32×32 mesh after a strike, linear vs chaos | `scripts/mesh_media.py` |
| `images/{mainboard,panel}_{top,bottom}.png` | Solder-mask style board views | `scripts/render_pcb.py` |
| `images/{stack_hero,stack_side,mainboard_3d,panel_3d}.png` | 3D renders | `scripts/render_3d.mjs` |
| `images/case_hero.png`, `images/case_xray.png` | Desktop case renders (opaque, see-through) | Cropped from `hardware/panel/previews/desktop_fit_study.png` and `previews/hq/05_full_assembly_iso_4k.png`, rendered from the actual-part STEP assembly |
| `3d/courant_stack.stl` | Mated stack, one mesh, for GitHub's STL viewer | `scripts/build_3d.py` |
| `3d/courant_{stack,mainboard,panel}.glb` | Coloured glTF models | `scripts/build_3d.py` |

## What these are, and are not

- **No audio here is a hardware recording.** The `rtl_*` clips are the RTL's
  own I2S output, simulated cycle by cycle with Verilator from the repaired
  2026-09-16 build (before the FX chain, physical mallet and stiffness), with
  one constant gain each. `chaos_ab` is rendered by the float reference model
  `model/NLMesh2D.m`. `scripts/nlmesh.py` is a NumPy port that
  `mesh_media.py` checks against Octave on every run (max |Δu| ≈ 2e-15)
  before it renders anything. The RTL's bit-exact check is a separate test:
  `model/nl_reference.m` against the GHDL testbenches.
- **Board renders are read from the native KiCad 10 files**
  (`hardware/courant/deliverables/courant.kicad_pcb`,
  `hardware/panel/design/radian_panel.kicad_pcb`): outline, cutouts, drills,
  pads, tracks, zones, silkscreen and footprint placement. Nothing in
  `hardware/` is written.
- **3D component bodies are parametric stand-ins** sized from package
  datasheets, placed at the native footprint positions. The stack spacing
  (19.99 mm) and board-to-board registration come from
  `hardware/stack/panel-stack.json`. The vendor/actual-part STEP models in
  `hardware/CURRENT_DESIGN.md` are not committed (`*.step` is gitignored), so
  these models are layout previews, not mechanical CAD. The knobs are
  illustrative: knob choice belongs to the enclosure.

## Requirements

- `octave-cli` (GNU Octave 8+)
- For the RTL clips: docker with an image that has GHDL (with `synth`) and Verilator 5
- Python 3 with `numpy scipy matplotlib shapely trimesh mapbox_earcut pillow`
- `ffmpeg` with libmp3lame and libx264 (or libopenh264)
- Node 18+ with Playwright and a Chromium build (`npm install` in `scripts/`
  fetches three.js; it renders through SwiftShader, so no GPU is needed)

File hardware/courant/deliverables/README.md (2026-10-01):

> **Release synchronization: 2026-09-16.** Current native boards, fabrication-format exports and CAD are indexed in `../../RELEASE_SYNC_STATUS.md`. Earlier statements below about pre-repair exports are historical; electrical/physical validation limitations still apply.

# Current native mainboard — 2026-09-16

<p align="center">
  Courant mainboard, 3D preview
</p>

| Top (F.Cu, faces the panel) | Bottom (B.Cu) |
| --- | --- |
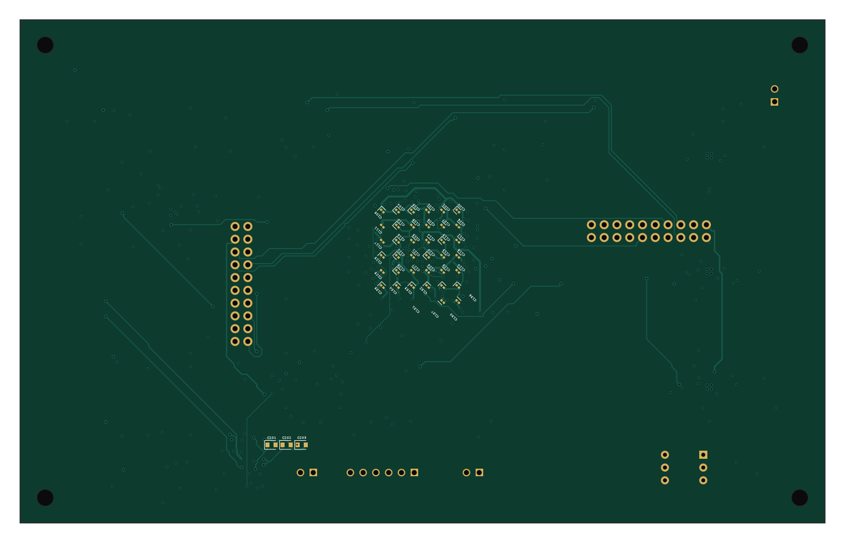
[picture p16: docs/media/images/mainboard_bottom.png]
Mainboard bottom
| Mainboard top |  |

<sub>Rendered from `courant.kicad_pcb` by `docs/media/scripts/`. Component bodies in the 3D view are simplified stand-ins. See `docs/media/README.md`.</sub>

The PCB in this folder passes Backplane KiCad 10.0.6 DRC: **0 errors, 0 warnings, 0 unconnected**, with unchanged project rules. Current counts: **2,158 track segments and 299 vias**. See `MAINBOARD_REPAIR.md` and `native_checks/drc.json`.

The assembly STEP, mechanical PDF/DXF, `dist/` PCB copies, 2D views, Gerbers, drills, placement data, BOM/netlist metadata and `dist/courant-fab.zip` have been regenerated from the current repaired native board. Use `hardware/refresh_outputs.py` for future review-export refreshes. Legacy route/reconstruction scripts are guarded from overwriting the authoritative native PCB.

**Not a manufacturing approval.** Component/footprint sign-off, FPGA operation/timing, electrical power integrity, thermal/fault behavior and physical assembly remain separate release gates.

The original handoff notes below are preserved as historical information; their old track/via counts are superseded above.

---

# Courant Rev A — handoff package

Standalone Artix-7 instrument board. **160 × 100 mm** on the Edge.Cuts
centreline (160.1 × 100.1 measured over the 0.1 mm stroke), 6 layers, 1.6 mm.
Four NPTH 3.2 mm mounting holes at (25,55), (175,55), (25,145), (175,145) —
150 × 90 mm spacing.
Routed and native-checked: **0 DRC errors, 0 warnings, 0 unconnected**, 2158 track segments,
4386.2 mm of copper, 299 vias, both ground planes uncut.

| File | What it is |
| --- | --- |
| `courant.kicad_pcb` | the board. KiCad 10 |
| `courant.kicad_pro` | project file — **open it alongside the board or you get KiCad's default design rules, not this board's** |
| `courant-assembly.step` | populated assembly, 3D. Board body, copper, silkscreen, soldermask and 183 of 202 component bodies |
| `courant-bom.csv` | bill of materials, 57 line items / 183 placements |
| `courant-netlist.txt` | 96 nets, extracted from the routed board |
| `courant-panel-interface.csv` | pinout of all 15 headers — the spec for building the front panel |
| `courant-mechanical.pdf` | outline, fabrication layer, silkscreen |
| `courant-outline.dxf` | board outline for mechanical CAD |
| `courant-schematic.svg` | schematic — 183 components, 739 pins, 532 wires, 248 net labels, 7038 x 6958 px vector |
| `courant-panel-hardware.md` | off-board parts, with `datasheets/` alongside |
| `courant-eurorack.md` | Eurorack status: what works as built, what changes, with values |
| `courant-source-design.ts` | the design source |

## Design rules

Default 0.15 mm track / 0.15 mm clearance, vias 0.55 / 0.25 mm. Power class
0.40 mm track, Ground 0.30 mm. These are set by the FTG256's 1.0 mm ball pitch:
escaping between two balls needs width + 2 × clearance inside a 0.5 mm gap, and
0.15 + 0.30 = 0.45 mm fits where KiCad's 0.2 mm defaults (0.6 mm) cannot.
0.25 mm drill through 1.6 mm is a 6.4:1 aspect ratio — inside any standard
6-layer process.

## Notes on three of these

**The schematic is rendered by `scripts/schematic.py`, not by tscircuit.**
`tsci export -f schematic-svg` and `-f schematic-pdf` both emit a near-empty
sheet for this design — about ten kilobytes, twenty text elements for two
hundred components — while the circuit JSON behind them holds all 183
components, 739 ports and 532 traces. The data was never missing, only the
drawing, so the drawing is done here. It is complete and to scale; it is not
arranged for signal flow, because tscircuit places symbols in declaration
order and no autolayout turns that into a drafted sheet.

**Every placement has a manufacturer part number**, and each one was checked
against live stock rather than inferred. Two families are covered by one
verified member plus the manufacturer's own value coding, noted on the line:
the Murata C0G run and the Yageo RC0603FR series.

**The panel hardware in `courant-panel-hardware.md` is a proposal.** The design
names no off-board parts and the right ones depend on a panel format that does
not exist yet, so those selections are specified to be electrically correct and
mechanically ordinary — a starting BOM, not a decision already taken. The four
that are sourced have datasheets in `datasheets/`.

## One design fix made while preparing this

R10 was **25 kΩ**, which is on no E-series grid and is not a stocked 1 % part —
a search for it returns 24.9 kΩ. It sets the V1 rail through the TPS62130's
0.8 V reference, so it is now **24.9 kΩ**: 0.8 x (1 + 24.9/100) = 0.9992 V
against a 1.000 V target, nearer than the 1 % resistors can hold. Fixed in
`design.ts` and in the board; `npm run check` passes.

## Before ordering

U1 is **XC7A50T-1FTG256I**, swapped from the XC7A35T-1FTG256C. The pin
compatibility is verified, not assumed: AMD's package files for the two parts
in FTG256 — both kept in `reference/` — are byte-identical from line 2 to the
end. All 256 balls, their banks, I/O types and no-connect flags match; the only
difference in either file is the device name on the header line. That makes the
swap a part number and nothing else, and it is the cheaper part besides
($67.01 against $118.75 at JLCPCB, both in stock) with 57% more logic and an
industrial temperature range.

One check is still worth doing and cannot be done from here: a Vivado synthesis
run against the A50T using the generated `courant_rev_a.xdc`. It will reject
any invalid ball assignment outright, and it confirms timing still closes —
the speed grade is unchanged at -1, so it should.

## Native repair and current files

See `../../REPAIR_STATUS.md` and `../reports/native/`. The local `RadianMain.pretty` snapshots and `fp-lib-table` must travel with the board. Both routed board copies and the manufacturing-format review exports were replaced on 2026-09-16. Native checks are not electrical or physical product validation.

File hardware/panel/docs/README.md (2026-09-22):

# RADIAN Panel / Interface P1 — engineering handoff

Revision P1 direct-stack / production-connector update, 2026-09-18. Built around the existing oxide-red 40 HP / 3U RADIAN front panel and the Rev F.1 desktop dock. The mainboard is electrically extended for the direct stack and three FX-pot ADC channels.

## 1. Honest completion status

This is a **signal-routed electrical and mechanical prototype design**, not another set of blank carrier-board rectangles. There is one electrical graph, a native KiCad project with five child schematic sheets, explicit part-to-pad net assignments, actual copper segments/vias, panel drilling references, and a corresponding 3D reference assembly.

It remains an engineering prototype. Native Backplane KiCad 10.0.6 has now loaded and checked the files: ERC, DRC, ground connectivity and schematic/PCB parity have zero findings. The inner GND zones are filled. Electrical function, component selection and physical/thermal/fault performance remain unverified. See `../reports/native/` and `../../REPAIR_STATUS.md`.

The five schematic sheets use named global nets and exact pin-labelled blocks. The current PDF is exported by native KiCad; a signal-flow and circuit-function review is still required.

## 2. What is on this single PCB

**Controls:** RV1–RV6 are 10 kOhm linear Bourns PTV09A-4020F-B103 pots: TENSION, DECAY, CHAOS, DRIVE, DELAY and REVERB. ENC1 is a Bourns PEC11R-4220F-S0024 encoder with push switch. SW1 is an E-Switch 100-series SPDT ON-ON switch and D10–D13 are 3 mm status LEDs. All six pot wipers are filtered at the mainboard ADC inputs.

**Patch connections:** J301 PITCH, J302 MOD, J303 GATE, J304 LINE L, J305 LINE R. All five use vertical WQP518MA/PJ398SM-style mono sockets. Input normal contacts are grounded when unplugged; output normal contacts are left unused. The mandatory under-barrel clearance hole is included in each footprint. The previous right-angle Same Sky jacks are not used in this planar board design.

**MIDI:** J306 is now an exact Molex KK-254 **22-27-2021** 2-circuit friction-lock header rather than generic pins. A short two-wire harness goes to the enclosure-mounted Same Sky **SDS-50J** DIN receptacle, pins 4 and 5 respectively. Those nets reach the mainboard through J101↔J18. Do not connect DIN pin 2/shield to PCB ground: the mainboard optocoupler provides the intended input isolation. The old DIN carrier PCB remains retired; the SDS-50J retainer/case fit still needs first-article verification.

**Power:** J200 is the exact Wurth **61201021621** keyed 2×5 WR-BHD Eurorack header. J201 is an exact Molex KK-254 **22-27-2021** 2-circuit friction-lock header for the short lead to the selected chassis-mounted Switchcraft **722A** 12 V DC inlet. Independent input fuses, diode-OR source combination, transient suppressor and the TPS54302 buck converter follow. Regulated VIN5 reaches the mainboard through J100↔J17.

**Optional modulation conditioning:** OPA2192 buffer/summing/gain stage selected by the exact Wurth **450301014042** SPDT mini slide switch at JP1. The removable 3-pin shunt is gone. JP1 is not the front MODE switch.

**Internal service:** J202 is an exact Molex KK-254 **22-27-2061** 6-circuit friction-lock JTAG header, alongside PROGRAM/RESET switches. These remain behind the panel; access requires removing the module. Their circuitry does not add level translation or new functions to the mainboard.

## 3. Mainboard connection

The former individual panel/mainboard cable headers are retired. Panel J100 mates directly with mainboard J17 and panel J101 mates with mainboard J18. Both are 2×10 2.54 mm Samtec mezzanine pairs defined by the shared `../stack/panel-stack.json` contract.

J17/J100 carries VIN5, GND, VREF25, all six pot wipers, PITCH/MOD/GATE and LINE L/R. J18/J101 carries V3V3/GND, encoder, MODE, four LEDs, MIDI, PROGRAM/RESET and JTAG. The final native boards have all 40 physical pins matched by both net name and assembled XY coordinate.

Mainboard connector MPN: **IPT1-110-06-L-D**. Panel connector MPN: **IPS1-110-01-L-D**. Fully mated PCB spacing is 19.99 mm, maximum specified spacing is 20.45 mm, and the mechanical support target is about 20.0 mm. Standoffs/supports carry structural load. `mainboard_harness.csv` is retained only as a deprecation pointer to `mainboard_stack.csv`.

## 4. Power architecture and important change

**Desktop input for P1 is regulated 12 V, not the earlier direct 5 V inlet proposal.** This choice lets the same protected conversion path serve rack and desktop operation. The selected chassis endpoint is a centre-positive Switchcraft **722A** 2.0 mm DC power jack; it connects to J201 with a short two-wire harness. The case opening/retention and harness strain relief still require first-article verification. The mainboard input remains regulated **5 V**; never connect either external 12 V source directly to main J1.

J200 uses the exact Wurth **61201021621** keyed module-side **10-pin** WR-BHD header:

| Pins | Connection |
|---|---|
| 1, 2 | −12 V position, intentionally NC |
| 3–8 | GND |
| 9, 10 | rack +12 V |

Use a verified **16-pin bus to 10-pin module** ribbon cable. Red stripe identifies the −12 V edge even though this module does not consume that rail. Inspect and continuity-check both ends. The module uses none of the extra bus +5 V/CV/gate signals. A shroud alone is not an assurance that a third-party cable or bus header is wired correctly. This 10-pin choice also avoids bringing the extra 16-pin bus signals into a connector that could be incorrectly reversed.

F1 and F2 precede Schottky OR diodes. Both source grounds are common. The diodes provide positive-rail backfeed blocking in their intended polarity; this is **not galvanic isolation**, not an ideal-diode power mux and not a complete certification against cable faults. The higher effective source voltage will carry the load. Avoid connecting both supplies during initial testing.

The TPS54302 circuit uses the TI 5 V application topology with 10 uH inductance, two 22 uF output capacitors, boot capacitor, enable divider and feedback/feed-forward network. Ideal nominal feedback arithmetic gives about **5.079 V**, before component/IC tolerance and cable losses. The 3 A value is the converter IC's design target, **not a measured RADIAN load or guaranteed board rating**. The actual FPGA current, bus budget, dropout at startup, current-limit behavior, input diode losses, copper temperature and switcher stability require review and measurement.

The default fuse entries are explicitly `SELECT 2 A >=32 V 1206 fuse`. Their final ordering codes, derating, inrush capability and coordination with the SMBJ15A TVS are unresolved. Capacitor rows marked SELECT similarly need exact parts, voltage/DC-bias capacitance checks and purchasing review. Do not treat a nominally correct footprint as selection of a safe part.

## 5. Signal behavior

PITCH keeps the existing mainboard input scaling and the original 0–5 V operating range. It is not silently divided by two or offset, so the existing pitch convention is preserved. Wider voltage/fault behavior still needs verification of the mainboard front end.

JP1 selects MOD with a real SPDT switch:

| JP1 contact | Behavior |
|---|---|
| **pin 1 ↔ pin 3** | `MOD_RAW` directly to `MOD_IN`; original unipolar 0–5 V behavior |
| **pin 1 ↔ pin 2** | `MOD_BIPOLAR` to `MOD_IN`; nominal `Vout = 0.5 × Vin + VREF25` |

Nominal bipolar mapping is −5/0/+5 V → 0/2.5/5 V. The op-amp has finite output swing and the real stage cannot exactly reach its rails under load. The sampled resistor-only tolerance report is not a circuit simulation and does not include op-amp swing, offset, bandwidth, saturation, supply or ADC errors. Firmware must know that zero external modulation maps near ADC midscale. Change JP1 only with power off; calibrate the usable range on hardware.

LINE L/R are the original DAC line outputs, not amplified modular outputs and not headphone drivers. A mono patch plug does not change their electrical level. Gate conditioning and MIDI optoisolation remain on the mainboard; this panel does not duplicate them. Test plug insertion, shorts, back-driven outputs, and powered/unpowered input faults before attaching other equipment.

## 6. Mechanical interface

Panel: 202.8 × 128.5 × 2 mm, current nominal 40 HP format. New board envelope: **180.5 × 108 × 1.6 mm**, with intentional DIN/cradle and ventilation windows and edge reliefs around the mainboard support columns. Board front is at **z = −8 mm** relative to the panel rear; board back is −9.6 mm. Coordinates in `design.json`, the DXF and CSV use x right/y up as seen from the front. Native KiCad uses a reflected y coordinate (`128.5 − y`).

The active controls use two rows: TENSION/DECAY/CHAOS at **(38,96), (76,96), (114,96) mm** with 23 mm reference knobs, and DRIVE/DELAY/REVERB at **(66,70), (88,70), (110,70) mm** with 14 mm reference knobs. MODE is on the retained raised insert at **(150.5,84.5) mm**. The mainboard PCB plane moves 0.46 mm toward the panel so the Samtec pair sits at 19.99 mm fully mated; the four front supports are shortened and the rear spacers extended by the same amount. The rear guard and outer desktop dock body remain unchanged.

**The CAD is a dimensional/reference study.** J200/J201/J306/J202/JP1 now use selected-part 3D geometry in the panel assembly (Wurth/Molex), while the Samtec direct-stack models remain drawing-derived. The enclosure-mounted Switchcraft 722A and SDS-50J interfaces are still case/reference interfaces rather than a claim of vendor-CAD-certified assembly. Cable plugs, thread/retention details, fastener torque, tolerances and insertion loads are not certified. The encoder rear spacer, jack rear shims and mode rear spacer are proposed mounting-stack allowances to be sample-tested. Knobs and nuts are only reference geometry; exact knobs, nuts/washers, screws and tapped/inserted support details are still to be selected.

The dock remains included as the desktop configuration. Switchcraft 722A is now the selected 12 V inlet and Same Sky SDS-50J the selected MIDI DIN endpoint, but their enclosure retention, short-harness strain relief, feet/final hardware and thermal design still need physical first-article validation.

A plain PCB fit-template STL is provided only for a mechanical test print. It is not a conductive PCB, a production drill master, or a substitute for a real board.

## 7. Checks executed and not executed

Executed: explicit graph generation; pad-to-pad placement clearance; geometric copper/pad/via and board-edge checking; native ERC/DRC/parity; direct-stack 40-pin net/XY comparison; independent parsing of emitted PCB pad/net assignments; ideal DC arithmetic; and reference CAD solid/intersection checks for the six controls, shifted support planes and Samtec body envelopes. Current case results are in `../reports/case_direct_stack_update.json` and `../reports/case_export_validation.json`.

Not executed: manufacturer footprint approval, impedance/EMI analysis, power/analog SPICE macro-model simulations, real-component fit, thermal/load/dropout/fault tests, FPGA execution and listening/audio measurements.

The custom checker uses a simplified nominal copper geometry model. It does not check every KiCad/manufacturer rule, soldermask web, drill plating specification, courtyard, silkscreen or thermal relief. Inner GND fills are deliberately missing from its test scope.

## 8. Opening, rebuilding and native validation

Open `design/radian_panel.kicad_pro` in KiCad 10. Keep its root and child schematics, `fp-lib-table`, `sym-lib-table` and sibling `library/`/`cad/` folders together. The embedded symbols make the net graph self-contained, and the local footprint library preserves the draft dimensions.

`source/verify_native.sh` has been executed with Backplane KiCad 10.0.6. ERC and schematic-parity DRC both exit 0. Its current reports are in `reports/native/`. Rerun after edits; do not silence findings to obtain a passing result.

Rebuild the generated draft only before doing manual edits, because generators overwrite their files:

```sh
python source/design_data.py
python source/export_ecad.py
python source/check_placement.py
python source/route_board.py
python source/validate_design.py
python source/render_docs.py
python source/build_cad.py
python source/update_case_direct_stack.py  # active P2 case synchronization; previews render when DISPLAY is available
# Optional case integration with your previous unzipped CAD package:
python source/build_cad.py --previous /path/to/RADIAN_RevF1_Desktop_and_Eurorack
```

Requirements are in `source/requirements.txt`; ReportLab previews also use locally installed DejaVu Sans fonts. No font files are distributed. The generator's net-labelled schematic is intentionally explicit rather than pretending to be a hand-drafted circuit sheet. See `sources.md` for design provenance.

## 9. Before money is spent

Finalize the exact electrical parts and off-board mechanics; run native tools and review the schematic/PCB; print the bare mechanical template and test real switches/jacks/knobs; review input protection, load budget and converter layout with the actual part data. Only then make fabrication exports from a reviewed native KiCad board.

For first electrical tests, keep the expensive mainboard disconnected. Use current-limited low-voltage bench power, prove the panel converter output, polarity, no-load/load behavior and transients with a dummy load, and measure faults only using a planned safe procedure. Then mate the mainboard through the verified J17/J18 direct stack and bring up power, controls and audio one interface at a time. Do not put mains voltage inside this dock.

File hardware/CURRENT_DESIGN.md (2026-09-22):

# RADIAN current hardware baseline — 2026-09-18

The repaired native KiCad boards are authoritative. Do not regenerate them in-place from legacy routing/export writers.

## Canonical native files
- Mainboard: `courant/deliverables/courant.kicad_pcb`
- Mainboard project/library: `courant/deliverables/courant.kicad_pro`, `courant/deliverables/fp-lib-table`, `courant/deliverables/RadianMain.pretty/`
- Panel/interface board: `panel/design/radian_panel.kicad_pcb`
- Panel project/schematic: `panel/design/radian_panel.kicad_pro`, `panel/design/radian_panel.kicad_sch`
- Shared board-stack contract: `stack/panel-stack.json`

## Native validation
- Mainboard Backplane KiCad 10.0.6 DRC: 0 violations, 0 unconnected.
- Panel Backplane KiCad 10.0.6 ERC: 0 violations.
- Panel DRC: 0 violations, 0 unconnected, 0 schematic/PCB parity findings.
- Mainboard has no native `.kicad_sch`, so mainboard ERC/parity cannot be claimed.

## Mainboard exact-part reconciliation
The canonical mainboard is now reconciled to its production BOM rather than carrying generator-era package aliases. All **180 referenced placements** have Manufacturer and MPN fields and a resolved project-local 3D model. Important identities are explicit: **U1 = AMD/Xilinx XC7A50T-1FTG256I (FTG256)**, **U5 = TI REF3125AIDBZR (SOT-23)**, **Y1/Y2 = Abracon ASE 100 MHz / 12.288 MHz 3225 oscillators**, **L1–L3 = Changjiang FNR4030S1R0MT**, **D10–D12 = Nexperia BAT54S,215**, and **D20 = Diodes Incorporated 1N4148W-7-F**. Service connectors are **J1/J3/J4 = Molex 22-23-2021**, **J2 = Molex 22-23-2061**, while J17/J18 remain Samtec IPT1-110-06-L-D.

This reconciliation did **not** move copper, vias, footprints, pads, nets, or component orientations. The only intentional native package change is the Molex J1–J4 through-hole drill correction from **1.00 mm to 1.02 mm** plus their actual connector courtyards. `courant/reports/mainboard_exact_parts.json` records the proof. Mainboard DRC remains 0 violations / 0 unconnected, and the exact-part STEP has been rechecked in the product assembly with zero panel↔mainboard clashes and zero unintended enclosure intersections. Molex J1–J4 and Samtec J17/J18 connector solids are drawing-derived reference models; physical first-article fit remains required.

## Actual-part product CAD
The canonical product assembly is now rendered from **native KiCad-placed component STEP groups**, not the old white envelope/block references. The final assembly is `panel/cad/RADIAN_actual_parts_full_assembly.step`, and `RADIAN_P1_desktop_fit_study.step` / `RADIAN_P1_case_updated.step` are regenerated from the same actual-part assembly.

Prominent panel hardware now uses real/open or package-accurate CAD: the six **Bourns PTV09A-series** potentiometers use aligned real family geometry trimmed to the selected 20 mm shaft; J301–J305 use the **PJ398SM/Thonkiconn** open mechanical model with knurled nut; SW3/SW4 use the maintained **Omron B3F-1000** package model; D10–D13 use a real 3 mm green LED package model. Wurth/Molex production connectors, standard IC/passive packages, and all reconciled mainboard packages are likewise exported from the component models attached to the native KiCad boards.

The remaining non-vendor-download solids are explicitly MPN-specific **drawing-derived reference geometry**, not generic boxes: ENC1 Bourns PEC11R-4220F-S0024, SW1 E-Switch 100SP1T1B1M2REH, Samtec J100/J101/J17/J18, and Molex mainboard J1–J4. `stack/actual_parts/actual_parts_report.json` records this distinction. No generic white component-envelope geometry is used in the final actual-part assembly.

## Front-panel controls and direct stack
The panel has six 10 kOhm macro pots in two rows. **TENSION · DECAY · CHAOS** are the widely spaced primary controls intended for 23 mm knobs at (38,96), (76,96), (114,96) mm; **DRIVE · DELAY · REVERB** are the tighter FX row intended for 14 mm knobs at (66,70), (88,70), (110,70) mm. The PCB uses the same Bourns PTV09A4 rear-facing pot footprint for all six; knob diameter is an enclosure/assembly choice. The push encoder, MODE switch and four LEDs remain. Internal legacy nets POT_PITCH/POT_DECAY/POT_TIMBRE remain unchanged; the three FX controls use POT_DRIVE/POT_DELAY/POT_REVERB.

The former per-function panel harness architecture is retired. The corresponding legacy mainboard edge headers **J5–J15 have now been physically removed from the canonical PCB**, along with their dead-end copper branches; J1–J4 remain as service/debug access. Two 20-pin direct mezzanine sites now mate panel to mainboard: J17↔J100 (power/analog/CV/audio) and J18↔J101 (digital/MIDI/service). The selected pair is Samtec **IPT1-110-06-L-D** on the mainboard and **IPS1-110-01-L-D** on the panel. The shared contract targets 19.99 mm fully mated / 20.45 mm maximum PCB spacing and a nominal 20.0 mm assembly support spacing. `stack/validate_direct_stack.py` now checks all **40/40 physical contacts** pin-by-pin for native-board XY, pin number, net name, recommended drill size, board side and attached 3D reference model. It also checks the published -06/-01 insertion/wipe geometry and panel solder-tail clearance. All 40 contacts pass.

## Exact panel-side service / off-board connector parts
The former generic panel utility headers have been replaced by selected production parts without moving their proven copper endpoints: **J200 = Wurth 61201021621** keyed 2×5 Eurorack power header; **J201 = Molex 22-27-2021** 2-circuit friction-lock desktop-power harness connector; **J306 = Molex 22-27-2021** 2-circuit friction-lock isolated-MIDI harness connector; **J202 = Molex 22-27-2061** 6-circuit JTAG service connector; **JP1 = Wurth 450301014042** SPDT mini slide switch. JP1 uses the real switch numbering: pin 1 common = MOD_IN, pin 2 = MOD_BIPOLAR, pin 3 = MOD_RAW. The selected chassis endpoints are **Switchcraft 722A** for 12 V desktop power and **Same Sky SDS-50J** for MIDI; these remain short off-board harness connections because those parts live in the enclosure rather than between the two PCBs.

## Actual-part CAD assembly
The current product CAD no longer uses the old generic white component envelopes for either PCB. Component placement is exported directly from the native KiCad boards and assembled in `stack/render_actual_part_cad.py`, so the CAD and KiCad placements share one source of truth.

Prominent panel parts now use real/open or package-accurate geometry: the six Bourns PTV09A-family potentiometers use real PTV09A mechanical CAD aligned to the selected **PTV09A-4020F-B103** footprint and trimmed to the selected 20 mm shaft; J301–J305 use PJ398SM/Thonkiconn mechanical CAD including the knurled-nut assembly; SW3/SW4 use the Omron B3F-1000 package model; D10–D13 use 3 mm green LED package geometry; U1/U2/D4 and all R/C/fuse/SMB parts use maintained package STEP geometry. Selected Wurth/Molex models remain in use.

The mainboard is likewise imported as KiCad-placed component groups using its exact/package STEP library rather than rendered as one flat white compound. The remaining non-vendor mechanical references are explicit and documented, not generic placeholders: **ENC1 PEC11R-4220F-S0024** and **SW1 100SP1T1B1M2REH** use drawing-derived full mechanical references; the Samtec direct-stack and mainboard Molex service connector solids are also drawing-derived references because vendor STEP files were unavailable.

Canonical actual-part assembly:
- `panel/cad/RADIAN_actual_parts_full_assembly.step`
- `panel/cad/RADIAN_P1_desktop_fit_study.step` (same current actual-part assembly)
- `panel/cad/RADIAN_direct_stack_mated.step`
- `panel/previews/actual_parts_full_assembly_iso.png`
- `panel/previews/actual_parts_full_assembly_front.png`
- `panel/previews/actual_parts_full_assembly_side.png`

`stack/actual_parts/actual_part_collision_report.json` is PASS: zero unintended panel↔mainboard collisions and zero rear-guard/desktop-dock collisions. Model-only reconciliation was also checked against the pre-edit native panel geometry: copper, tracks/vias, pad positions/sizes/drills/nets, footprint positions/orientations and board sides are unchanged.

The final STEP exporter works at **solid level**, not compound-group level, because STEP compound colors were being dropped by the CAD round trip and appearing as viewer-default white. The current full assembly contains **715 colored STEP children, 0 missing colors and 0 near-white default children**. Light cream is used only for the physical natural-nylon Molex connector bodies. U8/H11L1M is separately proven: the standard DIP-6 geometry is translated **(-3.81,+2.54) mm in STEP coordinates**, which under KiCad's Y inversion maps all six lead centers exactly to the native U8 pads; a placed U8 STEP export centers at **(48.000,-139.000) mm**, exactly matching the native footprint center.

## Current derived files
`hardware/refresh_outputs.py` regenerates current review Gerbers/drills, placement, BOM/netlist metadata, native board copies, 2D views, mechanical PDF/DXF and fabrication ZIPs from the canonical boards. `CURRENT_EXPORTS.json` records source hashes and commands. `NATIVE_BASELINE.json` protects the verified native copper.

These are electrically/geometry-checked engineering outputs, not a claim of physical production qualification. The remaining gates require real hardware: bench-fit the Samtec stack and ~20 mm support stack, verify connector seating/retention and enclosure tolerance, run power/load/fault/thermal measurements, and complete FPGA implementation/timing on the target device.

## Enclosure / case CAD
The product enclosure CAD is synchronized with the two-row six-pot/direct-stack revision. The faceplate carries three large-knob primary controls and three smaller-knob FX controls; primary labels sit above the large row and the lower row is marked as a compact FX group. MODE is restored to its original raised insert at (150.5,84.5) mm. The mainboard/support stack remains shifted 0.46 mm toward the panel for the 19.99 mm fully-mated Samtec PCB gap. Current assembly: `panel/cad/RADIAN_P1_desktop_fit_study.step`; validation: `panel/reports/case_direct_stack_update.json`. The Samtec direct-stack connectors use **drawing-derived IPT1/IPS1 20-contact reference models** attached to the native KiCad footprints, while J200/J201/J306/J202/JP1 use the selected Wurth/Molex part geometry in the panel CAD and native KiCad 3D view. Nominal CAD checks report zero control-hole conflicts, zero panel-component/mainboard clashes and zero unintended enclosure intersections. The published rounded REF dimensions produce a 0.01 mm housing-interface closure in the reference solids; insertion and contact wipe are checked independently against Samtec's mated-view dimensions. Physical first-article tolerance and retention remain release gates.

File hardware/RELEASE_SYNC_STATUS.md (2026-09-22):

# Active RADIAN hardware synchronized — 2026-09-17

The canonical mainboard is `courant/deliverables/courant.kicad_pcb`; the canonical panel is `panel/design/radian_panel.kicad_pcb`. Both use project-local footprint libraries and are protected by `NATIVE_BASELINE.json`.

This revision adds three dedicated FX pots and replaces the old panel/mainboard header-harness bundle with two direct Samtec mezzanine pairs. J17/J18 on the mainboard are IPT1-110-06-L-D; J100/J101 on the panel are IPS1-110-01-L-D. `stack/panel-stack.json` is the shared pinout/mechanical contract.

Native validation after the final connector-footprint/drill update: mainboard DRC 0 violations / 0 unconnected; panel ERC 0, DRC 0, unconnected 0, schematic/PCB parity 0. The final native connector pads did not move relative to the routed generic stack pads; the exact drill recommendations are 1.02 mm main and 1.04 mm panel.

The two boards were compared in assembled product coordinates: all 40 connector pins have the same net on both ends and matching XY positions. The selected Samtec combination is represented as 19.99 mm fully mated, 20.45 mm maximum PCB spacing, with a nominal ~20.0 mm mechanical support target.

`hardware/refresh_outputs.py --board all` is the required synchronization path for Gerbers, Excellon drills, placement files, BOM/netlist metadata, previews and review ZIPs. These outputs remain engineering/review artifacts rather than a claim of physical production qualification.

Remaining physical gates are first-article connector/support fit, retention, enclosure tolerance, electrical power/thermal/fault tests and actual target-FPGA implementation/timing/bring-up. No Git commit, push or reset was performed by this synchronization.

## Case synchronization
The enclosure/product CAD is now CASE-P2-DIRECT-STACK. Six control openings and labels are modeled, MODE is relocated, the former MODE insert is the REVERB insert, the mainboard is shifted +0.46 mm to the 19.99 mm fully-mated plane, and front/rear support geometry follows that plane. Exported STEP geometry passes independent shaft-hole/support/Samtec-envelope checks. Current case validation is `panel/reports/case_direct_stack_update.json`.

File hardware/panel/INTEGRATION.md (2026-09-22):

# RADIAN Panel P1 — integration status, 2026-09-17

The current panel is the six-pot direct-stack revision. Native KiCad 10.0.6 ERC, DRC, filled-zone connectivity and schematic/PCB parity all pass with zero findings.

The panel no longer connects to the mainboard through individual function harnesses. J100 and J101 are Samtec IPS1-110-01-L-D sockets that mate directly with mainboard J17/J18 Samtec IPT1-110-06-L-D terminal strips. The two 20-pin interfaces carry power, six pot controls, CV/gate, audio, encoder/MODE/LEDs, MIDI and service/JTAG. Only truly off-board functions such as the retained MIDI DIN and desktop inlet still use short leads.

`../stack/panel-stack.json` defines the common pin map, pad geometry and mechanical stack: 19.99 mm fully mated, 20.45 mm maximum and ~20.0 mm nominal support spacing. Standoffs/support hardware, not the connectors, must carry structural load.

Current fabrication-format outputs are in `fab/` and `radian_panel-fab.zip`; current reports are in `reports/native/`. They are engineering outputs. Real connector seating, enclosure tolerances, support hardware, power/load/thermal/fault behaviour and hardware bring-up remain first-article checks.

## Mechanical integration
The reference enclosure CAD is synchronized to STACK-P2: the two-row six-control surface, MODE on its raised insert, shifted mainboard/support planes, and drawing-derived **20-contact Samtec IPT1/IPS1 models** on both boards. `../stack/validate_direct_stack.py` verifies all 40 contacts pin-by-pin for physical XY, pin number, signal net, drill size, board side and attached 3D model. The assembled CAD also checks every modeled panel component/pin envelope against the mainboard assembly and reports no unintended panel↔mainboard clash. Samtec's rounded REF dimensions close the housing interface by 0.01 mm in the reference solids; the official mated-view values independently give 3.82 mm nominal geometric insertion and 0.84 mm contact wipe. Physical first-article tolerance/retention remains required.

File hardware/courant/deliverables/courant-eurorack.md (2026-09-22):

# Courant Rev A — Eurorack status

Everything below is measured against the board as routed, not against an
intention. Where a change is needed the values are computed, not estimated.

| | Status |
| --- | --- |
| Mechanical | **done** — RADIAN Rev F.1 gives a 40 HP panel, DXF through-cuts, STLs and a desktop dock |
| Gate input | **works as built** |
| Power | **works if the case supplies +5 V** — no board change, see below |
| Pitch/mod CV | **partial** — 0–5 V only; one resistor per channel fixes bipolar |
| Audio level | **line, not modular** — the one item needing new circuitry |

## Gate — no change

R166/R167 divide by 0.2481 against a comparator reference of
2.5 × 10/50.2 = 0.498 V, so the rising threshold at the jack is **2.01 V**. The
BAT54S only conducts above (3.3 + 0.3)/0.2481 ≈ **14.5 V** at the jack. Both
5 V and 10 V Eurorack gates are inside that with room to spare.

## Power — probably no change either

The Doepfer 16-pin bus carries **+5 V**, not only ±12 V. J1 needs +5 V and GND
and nothing else, so an adapter cable from the bus header to J1's 2-pin KK 254
housing is sufficient — **no board modification**.

`design.ts` specifies "5 V / 3 A", which would be beyond most Eurorack +5 V
rails, but that is headroom, not draw. Estimating from the actual load:

```
VCCINT 1.0 V   ~0.5 A                      0.50 W
VCCAUX 1.8 V   ~50 mA                      0.09 W
VCCO 3.3 V + codec, ADC, flash             0.65 W
                                    out    1.24 W
                        in, at ~85% buck   1.5 W  =  about 0.30 A at 5 V
```

**~300 mA is comfortable for a typical +5 V rail.** Treat it as an estimate
until a real board is measured — that is the single number that settles this.

Two things the adapter cable must carry, because the board has neither: a
**fuse** and **reverse-polarity protection**. A series Schottky costs 0.3 V of
the 5 V headroom, which the 3–17 V TPS62130 input range absorbs without
complaint.

Do **not** feed +12 V to J1. The regulators would tolerate it, but R12/R22 pull
the power-good pins to that rail and drive the next regulator's EN input, whose
absolute maximum has not been checked here, and C1 is a 16 V part.

## Pitch and mod CV — one resistor per channel

As built: R160 20 k from the jack, R161 20 k to ground, ÷2 into a 0–2.5 V ADC.
That is **0–5 V unipolar, 40 kΩ input impedance**, five octaves at 1 V/oct.
Negative input clamps at −0.6 V.

**For ±5 V bipolar** — add one resistor per channel from `VREF25` to the
existing divider node. R160 and R161 are unchanged:

```
R_offset = 10 kΩ    (VREF25 -> the R160/R161 junction)

  -5 V in  ->  0.000 V at the ADC
   0 V in  ->  1.250 V
  +5 V in  ->  2.500 V

input impedance 26.7 kΩ; VREF25 load 125 uA per channel
```

Exact, with no change to the buffer or the clamps. The REF3125 sources 10 mA,
so 250 µA for both channels is nothing.

**For 0–10 V unipolar** instead, change R160 from 20 k to **60.4 kΩ** (E96):
ratio 0.2488, full scale at 10.05 V, input impedance 80.4 kΩ.

Both are BOM changes on existing footprints — the bipolar option needs two new
0603 placements, which is local placement and a few millimetres of track, not
a re-route.

## Audio — the one real addition

The PCM5102A gives about 2.1 Vrms (5.9 Vpp). Eurorack runs ~10 Vpp, so the
board is **4.5 dB quiet**. Closing that needs a gain of 1.69 and a supply that
can swing to ±5 V; the board has only 3.3 V. That means a bipolar rail or a
charge pump and an output stage — genuinely new circuitry, unlike everything
else on this page.

Worth asking whether it matters. Plenty of Eurorack modules output line level
and are simply turned up. If modular level is a requirement, it belongs in
Rev B alongside the CV change.

## What this adds up to

Nothing here touches the FPGA, the ball field or the routed copper. The
mechanical design exists. Gate works. Power works with a cable, if the case has
+5 V. CV is one resistor per channel away from bipolar. Only the output level
would need a new circuit block, and only if you want modular level rather than
line level.

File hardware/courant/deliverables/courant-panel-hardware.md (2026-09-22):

# Courant / RADIAN — current panel hardware

The old Rev-A cable-harness panel interface is retired. Mainboard edge headers
J5 through J15 have been removed from the canonical PCB and are no longer part
of the BOM, fabrication outputs, or product assembly.

The current panel is a PCB assembly that plugs directly onto the mainboard:

- mainboard J17 ↔ panel J100
- mainboard J18 ↔ panel J101
- Samtec IPT1-110-06-L-D ↔ IPS1-110-01-L-D
- 40 physical contacts total
- 19.99 mm fully-mated PCB spacing; ~20.0 mm structural support target

The shared electrical/mechanical source of truth is
`../../stack/panel-stack.json`; `../../stack/direct-stack-validation.json`
records the current 40/40 pin and mechanical checks.

## Panel controls

The panel PCB carries TENSION, DECAY and CHAOS plus DRIVE, DELAY and REVERB,
the push encoder, MODE switch, four LEDs, five 3.5 mm jacks, Eurorack power,
and its panel-side Samtec sockets. The three primary controls use larger knobs;
the FX row uses smaller knobs.
## Connections that still use short leads

Only genuinely off-board/chassis functions need wiring:

- Same Sky **SDS-50J** MIDI DIN → short 2-wire lead → exact Molex **22-27-2021** J306;
- Switchcraft **722A** 12 V chassis inlet → short 2-wire lead → exact Molex **22-27-2021** J201;
- Eurorack bus ribbon → exact Wurth **61201021621** keyed J200.

There is no per-function cable bundle between the panel PCB and mainboard.

## Selected local service parts

JP1 is Wurth **450301014042**, a real SPDT switch rather than a removable header/shunt: pin 1 common is `MOD_IN`, pin 2 is `MOD_BIPOLAR`, and pin 3 is `MOD_RAW`. Panel J202 is exact Molex **22-27-2061** for JTAG service.

## Service access

Mainboard J1–J4 remain service/debug interfaces. They are not panel
connections and are intentionally separate from the production J17/J18 stack.

`courant-panel-interface.csv` is retained only as historical Rev-A reference;
do not use it as the current product interconnect. The current interconnect is
defined by `../../stack/panel-stack.json`.

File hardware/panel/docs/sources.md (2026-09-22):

# Design sources and provenance

Accessed/reviewed during P1 creation, 15 September 2026. This list separates user-supplied facts, external datasheets, design choices and unverified assumptions. Prices/stock are not established by this package.

## User files

`reference/input_manifest.json` records SHA-256 hashes of the original supplied mainboard files and key datasheets. Mainboard PCB and STEP files were not edited. The matching previous CAD-input hashes establish which hardware revision the fit study used.

- `courant-panel-interface.csv`: 45 header pin/net entries; authoritative mainboard boundary for this panel.
- `courant-panel-hardware.md`: proposed off-board choices, mainboard 5 V input and 0–5 V CV limitations. These selections were proposals, not frozen purchases.
- `courant.kicad_pcb`, `courant-assembly.step`, `courant-bom.csv`: original board geometry/components. Prior CAD-aligned STEP used for assembly fit reference.
- `Bourns_PTV09_potentiometer.pdf`, pages 1–2: PTV09A configuration 4 bushingless/rear-facing footprint and shaft dimensions. Signal terminals span 5.0 mm with the wiper midway (2.5 mm pitch). Changed neither resistance nor pot variant.
- `Bourns_PEC11R_encoder.pdf`, pages 2–3: rear-facing switch encoder footprint and ordering code. P1 selects 20 mm shaft rather than the original proposed 15 mm shaft, explicitly changing the MPN to PEC11R-4220F-S0024.
- `SameSky_SDS-J_DIN5_socket.pdf`: retained right-angle off-board DIN dimensional context. P1 does not claim this part can mount on the single panel PCB.
- Original Rev F.1 CAD archive: retained panel centres, mainboard alignment, case and dock geometry. Original CAD mechanical-fit results are not reused as P1 validation results.

## New external electrical/mechanical data

1. **Texas Instruments, TPS54302 datasheet** (SLVSD79C, March 2026), pinout, 5 V/3 A typical application and layout guidance. Circuit topology and nominal passive values are based on that application; the resulting PCB is not claimed to be TI's validated layout.
   https://www.ti.com/lit/ds/symlink/tps54302.pdf

2. **Bourns SRP7050TA power inductor series**, SRP7050TA-100M row and recommended land pattern. Nominal 10 uH, 4 A Irms and 7.5 A Isat under datasheet conditions; these ratings do not establish the enclosure temperature or system current capability.
   https://www.bourns.com/docs/Product-Datasheets/SRP7050TA.pdf

3. **Texas Instruments OPAx192 datasheet**, OPA2192 pinout and single-supply operation. The modulation equation is a P1 design derivation, not a reproduced reference circuit. Output headroom and dynamics need testing.
   https://www.ti.com/lit/ds/symlink/opa2192.pdf

4. **Thonk WQP518MA/PJ398SM supplier drawing and product page**. This is a supplier's dimensional reference, not a vendor-approved P1 footprint or manufacturer STEP model. The under-barrel hole and three contact positions are derived from the drawing.
   https://www.thonk.co.uk/shop/thonkiconn/
   https://www.thonk.co.uk/wp-content/uploads/2018/07/Thonkiconn_Jack_Datasheet-new.jpg

5. **E-Switch 100-series configurator and family datasheet**. M2 straight PCB pins, T1 actuator, B1 bushing, SP1 ON-ON and proposed R gold-contact option. Exact variant availability and purchased dimensions need confirmation.
   https://www.e-switch.com/product/100-series-miniature-toggle-switch/
   https://configured-product-images.s3.amazonaws.com/Datasheets/100.pdf

6. **E-Switch ST110001 mechanical drawing** for the Q silver-contact version, hosted by Farnell. Used for the common M2 mechanical family (8.89 mm body, 6.35 mm bushing, 4.70 mm terminal pitch, 1.85 mm holes). It is not a specific approval of the selected R-contact variant.
   https://www.farnell.com/cad/2341777.pdf

7. **Doepfer A-100 technical documentation**, module-side 10-pin versus 16-pin connections and available rails/signals. P1 intentionally uses the 10-pin module form because it uses no bus +5/CV/gate. Bus-side connector remains 16-pin with an appropriate 16-to-10 cable.
   https://doepfer.de/a100_man/a100t_e.htm
   https://www2.doepfer.eu/index.php/en/faqs/item/orientation-of-bus-connection-cables

8. **KiCad 10 CLI documentation**, native netlist/ERC/DRC and `--refill-zones --save-board` options. `source/verify_native.sh` uses documented commands, but was not executed in the creation environment.
   https://docs.kicad.org/10.0/en/cli/cli.html

## Explicit P1 choices, not facts supplied by the user

- One four-layer interface PCB with two intended inner GND planes.
- Regulated 12 V desktop inlet rather than the earlier 5 V proposal.
- 10-pin module-side rack header and positive-rail diode OR, not a 16-pin module header or ideal-diode mux.
- Vertical mono patch jacks replacing the proposed right-angle TRS parts; separate L/R outputs retained.
- Longer encoder shaft, shared panel PCB plane at −8 mm and associated mounting spacers.
- Optional bipolar MOD circuitry and default bypass jumper; PITCH and line-level audio unchanged.
- Short DIN and desktop inlet harnesses; no extra custom carrier PCB.
- Proposed part substitutions/envelopes, unrated generic harnesses and unspecified fuse/passive entries are **release gates**, not verified purchasing selections.

## Model and analysis limitations

STEP component bodies were constructed from dimensions and simple pin shapes. They are reference geometry, not downloaded certified manufacturer models. Inner-plane connectivity, EMI, converter stability and toleranced mechanical fit remain unverified. The numerical DC report evaluates ideal resistor equations and a sampled tolerance distribution; it does not simulate the complete circuit.

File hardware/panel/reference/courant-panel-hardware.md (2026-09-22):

# Courant Rev A — off-board (panel) hardware

Nothing in this list is on the PCB. Every control and socket is panel-mounted
and wires to one of the fifteen 2.54 mm headers; `courant-panel-interface.csv`
gives the pin-by-pin mapping. The board was designed this way deliberately —
see `courant-source-design.ts:187` for the filter arrangement that depends on
it — so these are the parts that complete the instrument, not alternatives to
anything on the board.

**These are selections, not decisions you have already made.** The design does
not name panel hardware, and the right choice depends on a panel format that
does not exist yet. Everything below is specified to be electrically correct
and mechanically ordinary; treat it as a starting BOM to argue with.

## Sourced, with datasheets in `datasheets/`

| Qty | Part | Manufacturer | MPN | ~$ ea | Feeds |
| --- | --- | --- | --- | --- | --- |
| 3 | 10 kΩ linear pot, 9 mm, 6 mm flatted shaft | Bourns | `PTV09A-4020F-B103` | 1.29 | J6 pitch, J7 decay, J8 timbre |
| 1 | Rotary encoder, 24 PPR, detented, with switch | Bourns | `PEC11R-4215F-S0024` | 2.95 | J9 |
| 4 | 3.5 mm TRS jack, right angle | Same Sky | `SJ1-3523N` | 1.12 | J5 line out, J12 pitch CV, J13 mod CV, J14 gate |
| 1 | DIN 5-pin socket, 180°, right angle | Same Sky | `SDS-50J` | 2.84 | J15 MIDI in |

Panel hardware subtotal: **about $16 per instrument.**

## Still to choose — trivial parts, but they depend on the panel

| Qty | What | Note |
| --- | --- | --- |
| 4 | LEDs, 3 mm or 5 mm | J11. **Series resistors R147–R150 are on the board** — wire the LEDs directly, anode to the pin, cathode to the GND pin. Do not add panel resistors |
| 1 | SPDT toggle or slide switch | J10. Pin 1 is 3V3, pin 3 is GND, pin 2 is the wiper to `cv_select`. Any single-pole changeover |
| 1 | 5 V DC inlet | J1. The board expects **regulated 5 V**, externally fused. A 2.1 mm barrel jack (e.g. Same Sky `PJ-102AH`) or a 2-pin terminal block both work |

## Three things worth knowing before wiring the panel

**The pots are referenced to `VREF25`, not 3.3 V.** Pin 1 of J6/J7/J8 carries
the 2.5 V reference that the ADC also uses, so a wiper reading is ratiometric
and reference drift cancels instead of appearing as pitch drift. Do not wire
the pot top ends to a rail.

**Keep the wiper runs as short as convenient, but do not add filtering.** The
1 kΩ series resistor sits on the board at the header and the 10 nF sits at the
ADC pin, which puts the cable *inside* the RC — anything the wiring picks up is
shunted at the ADC input rather than arriving at its sampling capacitor. A
capacitor added at the pot would defeat that.

**The CV inputs expect 0–5 V unipolar.** They pass through 0.1 % matched 20 kΩ
dividers into an MCP6002 buffer, scaling to the ADC's 0–2.5 V span, with
BAT54S clamps to the rails. Bipolar Eurorack CV (±5 V) will clamp on the
negative half — if this needs to accept bipolar CV, that is a front-end change,
not a wiring choice.

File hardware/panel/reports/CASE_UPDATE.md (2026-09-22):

# RADIAN case P3 two-row control update — 2026-09-18

The enclosure/product CAD now matches the two-row six-control panel and direct Samtec board stack.

- Primary row: **TENSION · DECAY · CHAOS** with 23 mm reference knobs at **(38,96), (76,96), (114,96) mm**.
- FX row: **DRIVE · DELAY · REVERB** with 14 mm reference knobs at **(66,70), (88,70), (110,70) mm**.
- The engraving reinforces the hierarchy: primary labels sit above the large row; a compact **FX** group mark sits left of the lower row with the three effect labels beneath it.
- All six controls remain standard rear-facing Bourns PTV09A4 potentiometers on the PCB; knob size is an enclosure/assembly choice.
- The three legacy macro holes are closed and six current 6.8 mm shaft openings are modeled in the main faceplate.
- MODE is restored to the original raised insert at **(150.5,84.5) mm**.
- The encoder remains at **(42,43) mm** and the right-side jack/LED layout remains unchanged.
- Mainboard remains shifted **+0.46 mm toward the panel** for the **19.99 mm fully mated** PCB-to-PCB gap.
- Four front supports terminate at **z = -29.54 mm** and the rear spacer set reaches **z = -31.14 mm**; the rear guard remains unchanged.
- The assembly imports the current **exact-part native mainboard STEP**. All 180 BOM placements now carry production MPN metadata and a resolved 3D model; the retired J5–J15 edge headers remain absent. Re-running the full enclosure intersection check with this populated STEP still reports zero panel↔mainboard clashes and zero unintended enclosure intersections. Mainboard IPT1 and panel IPS1 are represented by drawing-derived 20-contact STEP reference models.
- The former generic panel utility headers are now selected parts: J200 Wurth 61201021621; J201/J306 Molex 22-27-2021; J202 Molex 22-27-2061; JP1 Wurth 450301014042 SPDT. The panel CAD imports selected-part Wurth/Molex STEP geometry for these parts and reports no panel↔mainboard clash.
- **The final product CAD no longer uses the old white generic component envelopes.** `RADIAN_actual_parts_full_assembly.step`, `RADIAN_P1_desktop_fit_study.step`, and `RADIAN_P1_case_updated.step` are assembled from component-filtered STEP exports of the **native KiCad panel and mainboard**, so component placement/orientation comes directly from the PCBs.
- Prominent panel hardware now uses real/open or package-accurate geometry: aligned Bourns PTV09A-family CAD for RV1–RV6 (20 mm selected-shaft configuration), PJ398SM/Thonkiconn mechanical CAD with knurled nut for J301–J305, Omron B3F package CAD for SW3/SW4, and a 3 mm green LED package for D10–D13. Standard IC/passive packages and selected Wurth/Molex parts likewise come from the models attached to KiCad.
- The remaining non-vendor-download solids are explicitly **MPN-specific drawing-derived reference models**, not generic boxes: ENC1 PEC11R-4220F-S0024, SW1 E-Switch 100SP1T1B1M2REH, Samtec J100/J101/J17/J18, and mainboard Molex J1–J4. Model provenance is recorded in `stack/actual_parts/actual_parts_report.json`.
- CAD validation reports zero control-hole conflicts, zero panel-component/mainboard clashes and zero unintended enclosure intersections. The rounded Samtec REF dimensions create a 0.01 mm housing-interface closure in the reference solids; the stack is separately checked at 19.99 mm PCB gap, 3.82 mm nominal geometric insertion and 0.84 mm nominal contact wipe.

The selected enclosure endpoints are Switchcraft 722A for desktop 12 V and Same Sky SDS-50J for MIDI; both remain short-harness/chassis parts and require physical case-retention and strain-relief validation. The canonical full-product CAD now uses KiCad-placed actual/package component geometry rather than the former generic white component envelopes. The real/open PTV09A-family, PJ398SM, Omron B3F and LED models plus package-accurate IC/passive geometry are used directly; explicit drawing-derived references remain for PEC11R, the selected E-Switch and vendor-gated Samtec/Molex connectors. `stack/actual_parts/actual_part_collision_report.json` reports zero unintended panel↔mainboard and rear-guard/dock collisions.

The final STEP is exported as individually colored physical solids so CAD viewers no longer substitute default white for component groups. Round-trip validation reports 715 colored children and zero uncolored/default-white children. U8 on the mainboard is separately pin/center-aligned to its native footprint before the assembly export.

This is a checked reference mechanical model, not physical fit certification. The connector CAD is reconstructed from Samtec's official drawings because the vendor STEP download is email-gated. First-article connector seating/retention, knob/nut/washer stack and manufacturing tolerance remain required.

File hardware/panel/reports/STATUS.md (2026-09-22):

# RADIAN Panel P1 — integration status, 2026-09-18

The current panel is the six-pot, two-row direct-stack revision. Native KiCad 10.0.6 ERC, DRC, filled-zone connectivity and schematic/PCB parity all pass with zero findings.

The performance controls now have a visual hierarchy: **TENSION / DECAY / CHAOS** form a widely spaced primary row intended for 23 mm knobs; **DRIVE / DELAY / REVERB** form a tighter FX row intended for 14 mm knobs. The PCB still uses the same six Bourns PTV09A4 rear-facing potentiometer footprints. MODE is restored to the original raised insert.

The panel no longer connects to the mainboard through individual function harnesses. J100 and J101 are Samtec IPS1-110-01-L-D sockets mating mainboard J17/J18 Samtec IPT1-110-06-L-D terminal strips. The two 20-pin interfaces carry power, six pot controls, CV/gate, audio, encoder/MODE/LEDs, MIDI and service/JTAG. Only truly off-board functions such as the retained MIDI DIN and desktop inlet still use short leads.

`../stack/panel-stack.json` defines the common pin map, pad geometry and mechanical stack: 19.99 mm fully mated, 20.45 mm maximum and ~20.0 mm nominal support spacing. Standoffs/support hardware, not the connectors, must carry structural load.

Current fabrication-format outputs are in `fab/` and `radian_panel-fab.zip`; current reports are in `reports/native/`. They are engineering outputs. Real connector seating, enclosure tolerances, support hardware, power/load/thermal/fault behaviour and hardware bring-up remain first-article checks.

## Mechanical integration
The reference enclosure CAD is synchronized to the two-row layout: three large primary knob references, three smaller FX knob references, MODE on its original raised insert, shifted mainboard/support planes and Samtec body envelopes. Independent validation reports zero control-hole conflicts, zero panel-component/mainboard clashes and zero Samtec body-envelope overlap. Physical first-article tolerance/retention remains required.

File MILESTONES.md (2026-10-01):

# Milestones

## M0: Numerical reference model & stability study
- [x] MATLAB/Octave reference model (`model/fdtd_ref.m`)
- [x] CFL/stability sweep with plots (`model/stability_study.m`)
- [x] Q1.23 fixed-point quantization study (`docs/fixed_point_analysis.md`)
- [x] Repository scaffolding: `src/`, `sim/`, `docs/` tree and GHDL CI
      (`.github/workflows/ghdl-ci.yml` installs GHDL and runs `make -C sim`,
      which wildcards every testbench)

## M1: Node PE RTL & unit test
- [x] `src/rtl/fdtd_pkg.vhd` — Q1.23 types and `node_update` function
- [x] `src/rtl/node_element.vhd` — single-node processing element
- [x] `src/tb/node_element_tb.vhd` — unit testbench

## M2: Full mesh and system testbench
- [x] `src/rtl/grid_mesh.vhd` — NX×NY structural mesh with boundary wiring
- [x] `src/tb/top_resonator_tb.vhd` — impulse-response and stability tests

## M3: I/O integration
- [x] `src/rtl/i2s_transceiver.vhd` — I2S RX/TX + sample-strobe
- [x] `src/rtl/top_resonator.vhd` — top-level with control bus and CDC

## M4: Board bring-up
- [x] Synthesis for Digilent Arty A7 (`syn/vivado/arty_synth.vhd`,
      `build_arty.tcl`, `arty_a7.xdc`)
- [x] Resource budget documented in `docs/resource_budget.md`

## M5: Standalone instrument board
- [x] `hardware/courant/` — tscircuit schematic for the Rev A board
- [x] Device pinouts checked against manufacturer datasheets
- [x] Board-specific electrical rule checks (`npm run check`)
- [x] Vivado pin constraints generated from the board's own `io` map
- [x] Route the board. 2192 segments, 4436.7 mm, 313 vias on six layers, both
      ground planes uncut, no track under 0.15 mm: **0 DRC errors, 0
      unconnected**. tscircuit places it; KiCad writes the Specctra DSN and
      Freerouting cuts most of the copper (`npm run route`).
- [x] Finish the last connections. The nine that no router could close were not
      a routing problem: the back-side decoupling array was 0402 centred on the
      ball grid, and a 0402 land spans 1.56 mm on a 1.0 mm pitch, so each
      capacitor covered all four of its ball's escape slots — ten of the twenty
      slots needed. `design.ts` now places them as 0201, offset half a pitch
      diagonally onto a slot and turned 45 degrees, which costs one slot per
      capacitor instead of four. `scripts/reland_decaps.py` moves that onto the
      routed board without re-routing it; `scripts/close.py` then closes what
      is left with a real grid search, since every earlier tool could only draw
      straight lines, Ls and mitres and the survivors needed 20-36 segment
      paths. The two 0.1373 mm clearance violations are fixed by shifting the
      offending segment 0.02 mm, not by moving components.
- [ ] Measure the actual 5 V draw on a real board. Estimated at ~0.30 A against
      the 3 A the source specifies; that one number decides whether a Eurorack
      case's +5 V rail can run it (see `deliverables/courant-eurorack.md`).
- [ ] Eurorack, if wanted: an adapter cable with a fuse and reverse-polarity
      diode is enough for power, and one 10 kOhm resistor per CV channel from
      VREF25 converts the front end to +/-5 V bipolar exactly. Only modular-level
      audio output needs new circuitry — the board is 4.5 dB below it and has no
      bipolar rail to swing into.
- [x] Panel board integrated at `hardware/panel/` (RADIAN Panel P1): 180.6 ×
      108 mm, 4 layers, carrying the panel controls and the 12 V → 5.08 V
      inlet. Ground planes filled (they had outlines but no fill, so there was
      no plane), DRC run for the first time and cleared 2 → 0 by moving SW3
      0.6 mm off two header courtyards, Gerbers and drills generated, and all
      45 harness pins verified against the mainboard interface net for net.
      Three `power_pin_not_driven` ERC findings remain by choice — see
      `hardware/panel/INTEGRATION.md`.
- [ ] Fabricate and bring up: rails, JTAG, configuration, audio
- [x] SPI master RTL for the MCP3208 panel/CV ADC — `src/rtl/adc_mcp3208.vhd`
      with `src/tb/adc_mcp3208_tb.vhd`. Scans CH0-2 (pots, to panel_ctrl) and
      CH3-4 (pitch/mod CV, to cv_frontend) round-robin at 1 MHz SCLK, which is
      the MCP3208's 2.7 V figure rather than its 5 V one because this board runs
      it at VDD 3.3 V. **Not simulated here — GHDL is not installed in this
      environment; the GHDL CI job is what verifies it.**
      Integration note: the board's CV divider is 20k/20k into a 2.5 V
      reference, so one volt is 819.2 codes, not the 4096 codes per volt
      `cv_frontend`'s defaults assume. Instantiate it with CV_SCALE = 960,
      CV_SHIFT = 16 for 1V/oct tracking.
- [x] Swap U1 to XC7A50T-1FTG256I. Done in `design.ts` and in the routed
      board. The pin compatibility is now verified rather than assumed:
      `reference/xc7a50tftg256pkg.txt` and `reference/xc7a35tftg256pkg.txt` are
      byte-identical from line 2 to the end — all 256 balls, banks, I/O types
      and no-connect flags — and differ only in the device name on the header
      line. So the swap is a part number and nothing else: same footprint,
      placement, copper, ball assignments and generated XDC. It is $51.74
      cheaper (JLCPCB $67.01 against $118.75, 135 in stock against 175),
      carries 52,160 logic cells against 33,280 and 120 DSP slices against 90 —
      taking the 4-voice build off 82% DSP utilisation — and is industrial
      temperature range rather than commercial. `npm run check` passes.
      Still worth a Vivado synthesis run to confirm timing closes (same -1
      speed grade, so it should).

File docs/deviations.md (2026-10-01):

# Deviations log

Intentional deviations from the reference model, and an honest record of what
has and has not been validated (README §7, "simulation-first honesty"). If a
claim is backed by simulation but not yet by hardware, it says so here.

## Latency validation (issue #27)

The claim (README §3): latency is **deterministic and sub-sample**, dominated by
the codec framing and the PE pipeline (nanoseconds to microseconds), **not** by
block buffering (milliseconds). Status: **confirmed in simulation; on-board
capture pending hardware.**

### Measured in simulation

[`src/tb/latency_tb.vhd`](../src/tb/latency_tb.vhd) measures both parts a
simulation can measure and prints the numbers:

| Measurement | Result | Notes |
| --- | --- | --- |
| Compute latency (mesh_resonator, OS=4) | **27 system cycles = 270 ns** at 100 MHz | 1% of the ~2083-cycle (100 MHz / 48 kHz) sample budget. This is the OS oversampled mesh steps through the 4-stage PE pipeline plus the decimator. |
| End-to-end latency (top_resonator over I2S) | **2 audio frames** (~42 us at 48 kHz) | I2S input framing (1 frame) + compute + I2S output framing (1 frame) + CDC. No buffering term. |

The end-to-end figure is the key evidence for the claim: it is a small, fixed
number of frames set entirely by the I2S frame structure and the PE pipeline. A
block-buffered design would add its whole block length here (32-256 frames);
this design adds none. `latency_tb` asserts the compute latency stays a fraction
of the sample budget and the end-to-end latency stays within a few frames, so a
regression that introduced buffering would fail the test.

### Not yet done (needs the physical board)

The following acceptance-criteria items from issue #27 require an Arty A7 + Pmod
I2S2 and bench instruments, which are not available in this environment. They
are set up to be turnkey once hardware is in hand, but are **not yet executed**:

- [ ] Strike the mesh on hardware and capture real audio output to a WAV.
- [ ] Confirm recognisable, stable gong/drum/plate tones from the board.
- [ ] Measure end-to-end latency on a scope (excitation edge -> first audio
      output edge) and confirm it matches the ~42 us simulation figure.

To run these when the board is available:

1. Build and flash the master-mode design (see
   [`codec_bringup.md`](codec_bringup.md) for the clocking and wiring).
2. Generate the simulation reference WAV:
   `octave-cli --eval "fdtd_ref"` -> `model/outputs/impulse_fixed.wav`.
3. Strike the mesh and record the board's line-out to a WAV at 48 kHz.
4. Compare: `octave-cli --eval "compare_capture('board_strike.wav')"`
   ([`model/compare_capture.m`](../model/compare_capture.m)). It cross-correlates
   the capture against the reference, prints the measured latency (samples / ms)
   and a normalised error, and PASS/REVIEWs on a loose recognisability gate (the
   analog path is not bit-exact, so this is a similarity check, not a
   bit-for-bit one).
5. Record the measured latency and correlation here, and note any deviation
   from the simulation figures above.

## Model / RTL deviations

None recorded yet. RTL that intentionally diverges from the
[`model/`](../model) reference (e.g. fixed-point rounding choices beyond the
documented Q1.23 behaviour) will be logged here as it arises; to date the RTL is
bit-exact with the Q1.23 reference in every testbench that compares against a
golden trace.

## Fixed-point vs floating-point reference (M0 study)

Recorded during the M0 quantization study (June 2026), against the
floating-point reference ([`model/Mesh2D.m`](../model/Mesh2D.m),
[`model/fdtd_ref.m`](../model/fdtd_ref.m)). Statuses reflect that study;
the D5/D6 "gap" rows predate the non-linear model (`NLMesh2D`).

Status legend: **characterised** (measured, within budget) · **intended**
(deliberate design choice) · **gap** (reference model not yet complete) ·
**open** (needs work / decision).

| ID | Area | Reference behaviour | Deviation | Rationale | Status | Ref |
| --- | --- | --- | --- | --- | --- | --- |
| D1 | Arithmetic | IEEE double | Signed **Q1.23** saturating fixed point | Hardware cost; ~66.6 dB SNR, −85.6 dBFS noise floor, 0 saturations at head-room | characterised | [fixed_point_analysis.md](fixed_point_analysis.md) |
| D2 | Rounding | Exact | Round-to-nearest on every `>>23` rescale | Truncation adds a DC bias the recursion integrates (+4.2e-5 vs 4.7e-8) and costs SNR | intended | [fixed_point_analysis.md](fixed_point_analysis.md) §3 |
| D3 | Coefficients | Exact `a0`, `sigk1` | Finite-precision, precomputed on the control bus | Avoids per-node division; must stay ≥ ~20 frac bits or `sigk1 → 1.0` and damping vanishes | characterised | [fixed_point_analysis.md](fixed_point_analysis.md) §2 |
| D4 | Accumulator | Exact sum | 48-bit guard at Q.23, saturate on store | 25 integer guard bits ≫ the ~4 needed; overflow only soft-clips | characterised | [fixed_point_analysis.md](fixed_point_analysis.md) §4 |
| D5 | Non-linearity | Linear mesh only | `alpha*u^2` chaos term + `gamma2_max` clamp **not yet modelled** | Deferred to a later milestone; reference model is currently linear | gap | README §2, [derivation.md](derivation.md) §5 |
| D6 | Oversampling | Base rate `f_s` | Squaring non-linearity aliases; oversample/decimate not yet modelled | Mitigation is an area/quality knob, added with the non-linear term | gap | README §2 (Aliasing) |
| D7 | Input scaling | Unit strike | Excitation must be pre-attenuated (~5–6× head-room) | Strike-to-peak gain ~5.4× would otherwise saturate Q1.23 internal state | intended | [fixed_point_analysis.md](fixed_point_analysis.md) §5 |
| D8 | Free boundary | numpy/Octave `reflect` ghost (mirrors first interior cell) | RTL edge wiring must reproduce the same ghost choice | Bit-accuracy vs the reference depends on matching the boundary exactly | open | [Mesh2D.m](../model/Mesh2D.m) `step()` |

### How to use this table

* When RTL is written (M1+) and a unit/system testbench shows a difference from
  the reference, add a row here before "fixing" it — some differences are
  expected (D1–D4) and the test tolerance should reflect them.
* Promote a **gap** to a characterised/intended row once the corresponding model
  or RTL lands.
* Cross-link the script, testbench, or doc that quantifies each deviation.

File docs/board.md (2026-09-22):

# Courant standalone board (Rev A)

The Arty A7 + Pmod I2S2 target in [`syn/vivado/`](../syn/vivado/) is a bring-up
rig: it proves the RTL on hardware someone can buy for $130, but it is a
dev board with a synth bolted to it. This is the instrument version — a single
160 x 100 mm board carrying the FPGA, its configuration flash, both clocks, a
stereo DAC, and the whole analog front end the Arty build leaves off.

The design lives in [`hardware/courant/`](../hardware/courant/) and is written in
[tscircuit](https://tscircuit.com): React/TypeScript that evaluates to Circuit
JSON, from which SVGs, Gerbers, a netlist, KiCad files and a Specctra DSN are
generated. `design.ts` is the netlist, `footprints.tsx` holds the few custom land
patterns, `courant.circuit.tsx` is the board.

> **Current status (2026-09-16): routed, native DRC 0 errors / 0 warnings / 0 unconnected; not physically validated.**
> 2158 track segments, 4386.2 mm of track, 299 vias. Overlapping via holes and dangling copper were repaired.
> See [`hardware/REPAIR_STATUS.md`](../hardware/REPAIR_STATUS.md) and the current native JSON reports.
> The routing-development narrative below describes earlier stages, not the current outstanding work.

---

## 1. Blocks

| Block | Parts | Notes |
| --- | --- | --- |
| Power | U11–U13 TPS62130A, L1–L3 1 µH | 5 V in → 1.0 V / 1.8 V / 3.3 V, cascaded |
| FPGA | U1 XC7A50T-1FTG256I | 256-ball BGA, 1.0 mm pitch |
| Config | U2 W25Q64JVSSIQ | master SPI, 64 Mbit |
| Clocks | Y1 100 MHz, Y2 12.288 MHz | separate parts, see §3 |
| Audio | U3 PCM5102A | I2S, FPGA is master |
| Controls | U4 MCP3208, U5 REF3125 | 3 pots over SPI, 2.5 V reference |
| CV | U6 MCP6002, U7 MCP6561, D10–D12 BAT54S | pitch/mod in, gate comparator |
| MIDI | U8 H11L1M | opto-isolated, 31250 baud |

### Power

Three TPS62130A buck converters in a chain, each enabled by the previous one's
power-good pin: 5 V → 1.0 V (`VCCINT`/`VCCBRAM`) → 1.8 V (`VCCAUX`) → 3.3 V
(all `VCCO` banks). The A suffix matters — on the plain TPS62130 the power-good
pin is high-impedance while the part is disabled, so the chain would not start;
on the TPS62130A it is actively low, which is what makes the cascade a sequencer.
The last stage's power-good drives `PROGRAM_B`, holding the FPGA in reset until
3.3 V is up.

Feedback dividers set 0.8 V x (1 + Rtop/Rbot): 24.9k/100k = 0.9992 V, 124k/100k =
1.79 V, 316k/100k = 3.33 V. `FSW` and `DEF` are tied low on all three, selecting
2.5 MHz and the nominal (not +5 %) output, which is what makes the 1 µH / 22 µF
output filter the right size.

### FPGA and configuration

Mode pins are strapped M[2:0] = 001 for master SPI (`M0` high, `M1`/`M2` low).
`CFGBVS` is tied to 3.3 V for a 3.3 V configuration bank. The XADC is unused, so
`VREFP` and `VREFN` are grounded and `VCCADC` sits on the 1.8 V rail, per UG480's
unused-XADC configuration. `PUDC_B` is pulled high so the I/O pull-ups are off
during configuration.

The flash clock comes out of the dedicated `CCLK` ball (E8), not a user I/O — in
master SPI mode the STARTUPE2 primitive drives it.

Decoupling is 38 x 100 nF 0201 on the back side directly under the BGA, distributed beneath the FPGA, plus bulk 47 µF/4.7 µF per rail.

### Clocks

Two oscillators rather than one, deliberately. A single 100 MHz source would
have to reach 12.288 MHz through an MMCM, and 12.288 does not divide cleanly
from 100 — the closest ratio leaves a residual frequency error that shows up as
audio sample-rate drift. A second 12.288 MHz part costs about a dollar and makes
the audio clock exact. Both land on clock-capable balls (D4 is MRCC, E3 is SRCC).

### Audio

PCM5102A in hardware mode: `FMT` low for I2S, `DEMP` low, `FLT` low for normal
latency, `XSMT` driven by the FPGA so the output can be muted before the mesh is
excited. Its analog 3.3 V comes through a series 1 Ω and its own bulk rather than
a separate LDO, which would cost output headroom for no measurable noise gain at
this level. Outputs are 470 Ω + 2.2 nF into the line jack.

### Controls, CV and MIDI

Three panel pots and both CV inputs are sampled by one MCP3208 over SPI, against
a REF3125 2.5 V reference. CV inputs are 0–5 V into a 20k/20k divider (so 0–2.5 V
at the ADC) with BAT54S rail clamps. The gate input is a comparator with a
divider-set threshold of about 2.0 V at the jack. MIDI is the standard
opto-isolated DIN input; DIN pin 2 is deliberately *not* connected to board
ground, which is the entire point of the isolation.

---

## 2. Footprints

Standard packages use [footprinter](https://github.com/tscircuit/footprinter)
strings, which are library-maintained and IPC-derived. Three are custom, each for
a reason recorded in `footprints.tsx`:

- **`ftg256`** — footprinter's `bga256_…` numbers pin 1 from the lower left. The
  design maps AMD's ball names (A1…T16) onto `pin(row*16 + col)` with A1 upper
  left, so using the string would mirror every ball on the package vertically.
- **`qfn16`** — `qfn16_w3_h3_p0.5mm_thermalpad` places the signal pads' inner
  edges 0.525 mm from centre against a 1.75 mm thermal pad that reaches 0.875 mm,
  overlapping them by 0.35 mm and shorting all sixteen pins to the pad. TI's
  RGT0016C exposed pad is 1.68 mm and its leads reach 1.5 mm from centre, so the
  custom pattern uses 1.68 mm with the pads spanning 1.10–1.80 mm.
- **`soic8w208`** — the W25Q64JV's `SS` package is 208-mil SOIC-8, and
  footprinter silently ignores the width modifier in `soic8_w5.3mm_p1.27mm`,
  returning the 150-mil pattern. Derived from Winbond's package table with
  IPC-7351 nominal fillets.

The 3.2 x 2.5 mm oscillators and the 4 x 4 mm inductors have no footprinter
family and are spelled out.

---

## 3. Routing

tscircuit places this board and owns its netlist; it does not cut the copper.
That is done by [Freerouting](https://freerouting.org), through KiCad, and the
result comes back into the same board file the placement came out of:

```sh
npm run export   # dist/courant.kicad_pcb -- placed, no copper
npm run route    # -> dist/courant.routed.kicad_pcb
npm run fab      # -> DRC report, Gerbers, drill, placement, BOM, previews
```

`scripts/route.py` drives that loop end to end: it writes the design rules, has
KiCad write the Specctra DSN, runs the router headless, imports the session file
back and refills the ground planes. `scripts/fab.py` then runs KiCad's DRC and
plots the fabrication outputs. Both need tools npm cannot install -- KiCad 9+
with its `pcbnew` Python module, a JRE, and `freerouting.jar` (point
`$FREEROUTING_JAR` at it) -- and both say so plainly if they are missing.

Five things about that path are not obvious, and each one is a trap.

### tscircuit's own autorouter does not converge

tscircuit's bundled `capacity-autorouter` fails on this board with

```
Pipeline9 route "source_net_25_mst41" changes layers from z=5 to z=0
without an explicit via (capacity-autorouter@0.0.900)
```

and emits no copper at all, leaving every port unrouted. That is a router defect
on a 256-ball BGA escape across six layers, not a netlist problem -- the same
netlist passes `tsci check netlist` and builds cleanly with routing disabled.
The board therefore carries `autorouter="none"`, which keeps every build fast
instead of spending about seventeen minutes to produce nothing.

### tscircuit's Specctra export cannot be used either

`tsci export -f specctra-dsn` is the advertised handoff to an external router,
and it is not usable here. It fails two ways, one loud and one silent:

- **It crashes.** `convertCircuitJsonToDsnJson` groups pads by
  `pcb_component_id` and then dereferences the resulting `pcbComponent.center`
  without checking that the lookup found anything. This board's three fiducials
  emit `pcb_smtpad` elements whose `pcb_component_id` is null, so the export
  dies with `TypeError: undefined is not an object (evaluating
  'pcbComponent.center')` and writes no file.
- **It would be wrong if it did not crash.** The converter writes
  `side: "front"` for every component regardless of the layer it is on. All 38
  decoupling capacitors on this board are on the back, directly under the BGA.
  A DSN from that converter puts them on top, and nothing downstream would
  catch it.

KiCad's exporter gets both right, so `scripts/route.py` loads
`dist/courant.kicad_pcb` and calls `pcbnew.ExportSpecctraDSN`. That has a second
benefit: the router, the DRC and the Gerber plot then all read the same board
file and the same rules, so they cannot disagree about the board.

### Net names must be distinct with case ignored

Specctra folds net names to a single case. tscircuit and KiCad do not: `led0`
and `LED0` are two nets to them, and the DSN written from the board contains
both. Freerouting reads them as one, and the session file it writes back
mentions only `led0` -- so the four 1 kOhm LED series resistors R147-R150 came
back shorted across, as twelve `shorting_items` in DRC.

The panel-side nets are therefore `LED0_A`..`LED3_A`, and `scripts/check.ts`
now fails the build if any two nets differ only by case. This is not a
theoretical hazard; it cost a routing run.

### Keeping signals off the planes is a net-class rule, not a layer type

This is the mistake worth reading before changing anything about the handoff.

The obvious way to stop the router cutting up the ground planes is to declare
those layers `(type power)` in the DSN. It does not do that. Freerouting treats
a `power` layer as unavailable for connections altogether -- including the GND
pins that need to reach their own pour. The symptom is not an error; it is a
board that comes back with 55 to 60 connections unrouted, about fifty of them
GND, which reads exactly like a board too dense to route.

It was misread that way here for three consecutive routing runs, and the
conclusion drawn was that the design needed eight layers. It did not. The
evidence was already visible and pointing elsewhere: fanout escape dropped from
94% to 69% the moment the planes were reserved, the via count *fell* while
routing layers were being added, and the new inner layers sat nearly empty
while the router "could not finish". All three say connections are being
refused, not that there is nowhere to put them.

The mechanism that does what is wanted is a per-net-class `use_layer` clause.
Every layer stays `signal`, so vias and plane connections work normally, and
each class except the ground class is restricted to the non-plane layers.
`scripts/route.py` derives that from the board's own zones: layers carrying a
pour whose net is in `RETURN_NETS` are reserved, everything else is routable.
GND keeps the whole stackup.

Measured on this board, all other settings equal:

| Reserved | Unrouted | Signal segments cut through the planes |
| --- | --- | --- |
| nothing | 8 | 166 (1301 mm) |
| both ground planes, via `(type power)` | 56 | 0 |
| ditto, plus a V3V3 plane | ~90 | 0 |
| **both ground planes, via `use_layer`** | **9** | **0** |

Eight layers with the broken mechanism gave 14; six layers with the correct one
gives 9. The board never needed the extra copper.

### The default design rules cannot route a 1.0 mm BGA

KiCad's defaults -- 0.2 mm track, 0.2 mm clearance, 0.6/0.3 mm via -- are not
merely tight here, they are geometrically impossible. FTG256 balls are 0.5 mm
pads on a 1.0 mm pitch, so the gap between two neighbouring balls is 0.5 mm.
Escaping a signal between them needs `width + 2 x clearance`, which at the
defaults is 0.6 mm. Nothing fits, and the router reports the pins as unroutable
rather than explaining why.

`scripts/rules.json` carries the rules the package actually needs. It is written
out as `dist/courant.kicad_pro`, because KiCad keeps design rules in the project
file rather than the board file:

| | Default | Power | Why |
| --- | --- | --- | --- |
| track | 0.15 mm | 0.4 mm | 0.15 + 2 x 0.15 = 0.45 mm clears the 0.5 mm ball gap |
| clearance | 0.15 mm | 0.15 mm | same sum; also the via-to-ball margin below |
| via | 0.55 / 0.25 mm | 0.55 / 0.25 mm | a dog-bone via sits 0.707 mm from four balls: 0.707 - 0.25 - 0.275 = 0.182 mm of clearance. A 0.6 mm via leaves 0.157 mm and fails |

0.25 mm through a 1.6 mm board is a 6.4:1 aspect ratio, comfortably inside the
8:1 that plating prefers, and the 0.15 mm annular ring is past the 0.13 mm knee
where breakout risk collapses. All of it sits inside a standard six-layer
process.

The Power class widens the rails but keeps the Default clearance and via
deliberately. `VCCINT`, `VCCAUX` and every `VCCO` ball is inside the same 1.0 mm
ball field as the signals, so a fatter power via could not be fanned out at all.
The rails take their width the moment they leave the package.

Freerouting's automatic neckdown is switched off for the same reason the rules
exist: left on, it thins a trace to squeeze past an obstacle, and it produced
0.1124 mm copper against the 0.15 mm minimum in 70 places. The minimum is a fab
limit, not a preference.

### Some copper is placed by hand, and the router must not touch it

The twelve grounded thermal vias in the switchers' exposed pads (section 1) are
a thermal structure, not a connection. No autorouter has a reason to invent them
and every reason to delete them: KiCad writes pre-existing copper into the DSN's
wiring section as `(type route)`, which tells Freerouting it is looking at its
own previous output and may rip it up. `scripts/route.py` rewrites those to
`(type protect)` -- Freerouting's `SYSTEM_FIXED` -- before the router sees the
file, so the vias survive the round trip and are treated as obstacles while the
rest of the board is routed around them. All twelve come back.

`scripts/check.ts` checks the same vias from the other side, in the netlist: that
each one lands inside a TPS62130A exposed pad without overhanging it, and that
no two barrels overlap. That is geometry the netlist cannot express and the
router will not police, and it is what would silently break if a regulator were
ever moved.

### Running the router

Freerouting's defaults are wrong for a batch run in three ways that cost real
time, and none of them is a command-line flag:

- it opens a GUI and spends the run repainting it;
- its multi-threading feature flag is off -- though note this only affects the
  optimizer, since the autorouter is single-threaded and measures at almost
  exactly 1.00 cores whatever you pass to `-mt`;
- its fanout stage has no budget of its own and will spend the entire job on
  itself. On this board fanout escapes about 94% of pins in three passes and
  then grinds on the same ~30 it cannot place, at a minute or more a pass, until
  the job times out with the autorouter never having started.

All three live in a settings file, so `scripts/route.py` writes one and points
`$FREEROUTING__USER_DATA_PATH` at it. That also keeps the run out of the user's
own `~/.config/freerouting` and turns off the telemetry that is on by default.
Fanout is capped at six passes and the optimizer at 45 minutes so that the stage
which actually routes nets gets the time.

`--gui` puts the board window up if you want to watch; it is slower.

---

## 4. Building it

```sh
cd hardware/courant
npm install
npm run verify     # typecheck, board rules, netlist, and a clean build
npm run export     # SVGs, netlist, KiCad board, and the Vivado XDC
npm run route      # KiCad -> Freerouting -> routed KiCad board
npm run fab        # DRC, Gerbers, drill, placement, BOM, board previews
```

`npm install` covers the first three. The last two need tools outside npm's
reach:

| Tool | Used for | Where |
| --- | --- | --- |
| KiCad 9+ with `pcbnew` | DSN export, session import, DRC, Gerbers | distro package |
| a JRE | running the router | distro package |
| `freerouting.jar` | the router itself | [releases](https://github.com/freerouting/freerouting/releases), then `$FREEROUTING_JAR` |

`npm run check` runs `scripts/check.ts`, which enforces the rules tscircuit
cannot know, all against AMD's own package file (`fpga-pins.json`, generated
from the checked-in `xc7a35tftg256pkg.txt` by `scripts/make-pinmap.py`):

- no single-connection nets, no duplicate reference designators
- no two nets differing only by case, which Specctra would merge (section 3)
- every assigned ball exists in the FTG256 package, and no user signal lands on
  a dedicated configuration or supply ball
- every bank carrying user I/O has all of its `VCCO` pins on the 3.3 V rail
- both clock inputs are on clock-capable (MRCC/SRCC) balls
- the master-SPI mode straps, `CFGBVS`, `VCCADC` and the unused-XADC ties
- no FPGA supply ball left unconnected, and one decoupling capacitor per
  powered ball
- every thermal via inside the exposed pad it cools, and no two overlapping

`npm run export` also generates `dist/courant_rev_a.xdc` from the same `io` map
the schematic uses, so the board's pinout and the constraints handed to Vivado
cannot drift apart. It is the board's half of the contract with
`src/rtl/synth_top.vhd`.

`npm run fab` refuses to run on an unrouted board. Gerbers plotted from one
carry pads, soldermask and drills but no copper -- a file that looks exactly
like fabrication data and is not, which is the single mistake in this directory
that would cost real money.

---

## 5. Current verification and remaining work

Native Backplane KiCad 10.0.6 DRC reports zero errors, zero warnings and zero unconnected items on the installed mainboard. Checks include all configured severities. Original check settings were retained; ignored checks are listed in the report. Physical pads, net assignments, component placement and board outline were preserved.

The former six remaining connections, clearance findings and dangling copper are no longer current open work. `finishing_the_route.md` is retained as historical context only.

No native mainboard schematic is supplied, so mainboard ERC and native schematic/PCB parity are not claimed. No new manufacturer footprint approval, FPGA timing/bitstream execution, physical assembly, electrical, audio, thermal or fault tests were performed in this repair. Native geometric connectivity does not validate circuit function.

The repository contains `src/rtl/adc_mcp3208.vhd` and its testbench; they were not modified or executed in this PCB repair. Validate the actual FPGA build before ordering hardware.

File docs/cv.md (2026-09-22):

# CV (control-voltage) input front-end

The Eurorack-native counterpart to the MIDI front-end (#28). `cv_frontend`
([`src/rtl/cv_frontend.vhd`](../src/rtl/cv_frontend.vhd)) drives the **same
note-mapping interface** that `poly_voices` / `synth_top` consume (note events +
per-note `coeffs` + excitation), but from control voltage instead of MIDI, so
the engine plays from a modular system. It is a drop-in alternative to
`midi_frontend`: identical outputs, so it can feed the polyphonic pool or the
board top unchanged.

## Inputs

| Signal | Type | Meaning |
| --- | --- | --- |
| `pitch_cv` | `signed(CV_W-1:0)` | 1V/oct pitch, digitised by an external ADC |
| `gate` | `std_logic` | gate/trigger (a comparator on the gate jack) |
| `mod_cv` | `signed(CV_W-1:0)` | modulation CV, digitised by an ADC |

The analog CVs are assumed already digitised and presented synchronous to `clk`;
the `gate` is brought in through a two-flop synchroniser inside the block.
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

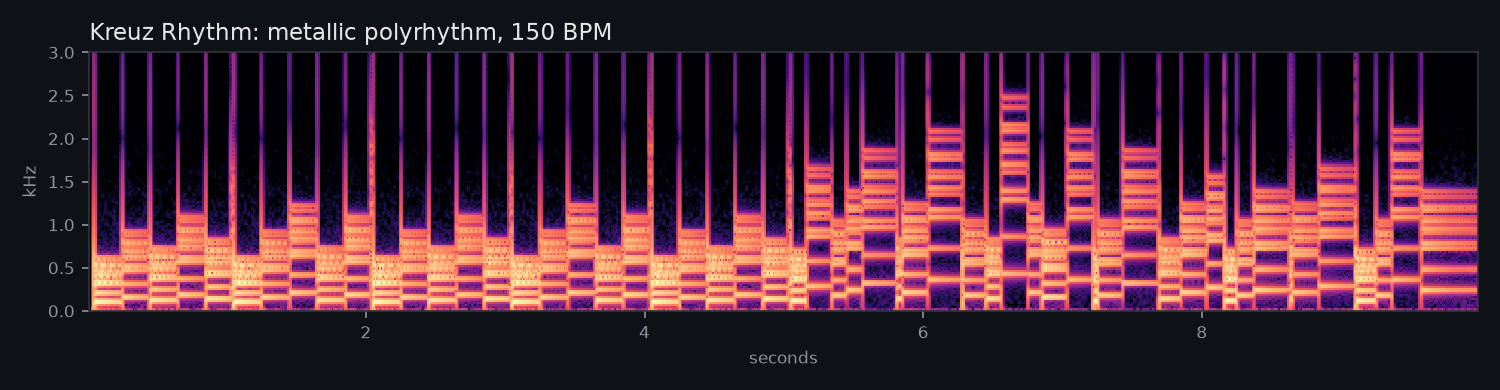
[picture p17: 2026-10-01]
docs/media/images/spectrogram_rtl_kreuz_rhythm.png

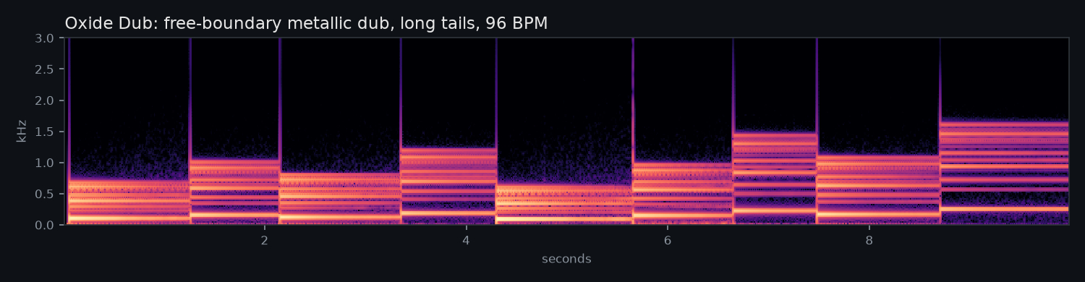
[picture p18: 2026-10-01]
docs/media/images/spectrogram_rtl_oxide_dub.png

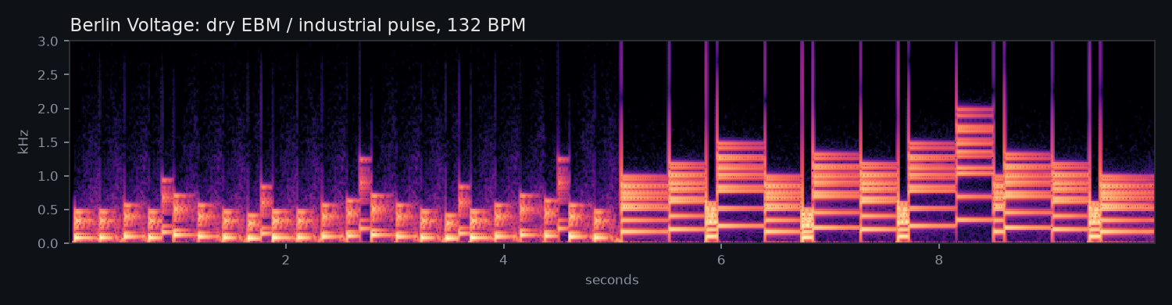
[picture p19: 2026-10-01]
docs/media/images/spectrogram_rtl_berlin_voltage.png

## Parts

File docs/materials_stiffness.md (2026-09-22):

# Advanced materials: bending stiffness and anisotropy (issues #31 / #86)

Issue #31 established the reference-model physics and stability result for a
4th-order **bending-stiffness** term (bars, plates, bells) plus **anisotropic**
propagation. Issue #86 now integrates the bending term into the production RTL
for both spatial and time-multiplexed meshes. The floating-point study remains
[`model/StiffMesh2D.m`](../model/StiffMesh2D.m) +
[`model/stiffness_study.m`](../model/stiffness_study.m); the production fixed-point
control mapping is independently regenerated by
[`model/stiffness_reference.py`](../model/stiffness_reference.py).

## The equation

The legacy/zero-STIFFNESS membrane is `u_tt = c^2 ∇^2 u`. Adding bending
stiffness and anisotropy:

```
u_tt = cx^2 u_xx + cy^2 u_yy  -  kappa^2 (u_xxxx + 2 u_xxyy + u_yyyy)  - 2 sigma u_t
```

- `cx, cy` : wave speeds along x / y. `cx = cy` is isotropic; `cx != cy` is an
  anisotropic membrane (an "oval drum": the mode frequencies split).
- `kappa` : bending-stiffness coefficient. The biharmonic term `∇^4 u` is the
  thin-plate / stiff-bar operator; it makes the medium **dispersive** (higher
  spatial frequencies travel faster), which stretches the partials sharp of a
  harmonic series, the inharmonic bar/bell character.

## Discretisation

Second differences (existing) plus the biharmonic. With `k = 1/fs` the time step
and `h` the spatial step, the explicit centred update is

```
u^{n+1} = a0 ( 2u - sigk1 u^{n-1} + g2x Dxx(u) + g2y Dyy(u) - mu2 Biharm(u) )
```

with the dimensionless coefficients

```
g2x = (cx k / h)^2      g2y = (cy k / h)^2      mu2 = (kappa k / h^2)^2
```

and the stencils (`1/h^4` folded into `mu2`):

```
Dxx = uE + uW - 2u                              (3-point)
Dyy = uN + uS - 2u                              (3-point)
Biharm = 20u - 8(N+S+E+W) + 2(NE+NW+SE+SW) + (NN+SS+EE+WW)   (13-point)
```

`Biharm` is the discrete `(∇^2)^2`: a **13-point** stencil that reaches two cells
out (the second ring `NN/SS/EE/WW`) and to the diagonals. Setting `mu2 = 0` and
`g2x = g2y` recovers the current 5-point membrane exactly.

## Stability (von Neumann)

Substitute `u ~ z^n e^{i(bx x + by y)}` and let `sx = sin^2(bx h/2)`,
`sy = sin^2(by h/2)`, each in `[0,1]`. The stencil Fourier symbols are

```
Dxx -> -4 sx     Dyy -> -4 sy     Biharm -> +16 (sx + sy)^2
```

(the biharmonic symbol is the square of the Laplacian symbol, since it is
`(∇^2)^2`). The update's characteristic equation is `z^2 - (2 - Q) z + 1 = 0`
with

```
Q = 4 (g2x sx + g2y sy) + 16 mu2 (sx + sy)^2   >= 0
```

Roots stay on the unit circle (stable, non-growing) iff `0 <= Q <= 4` for all
`sx, sy`. `Q` is maximised at `sx = sy = 1`:

```
Q_max = 4 (g2x + g2y) + 64 mu2   <=  4
```

giving the **stability condition**

```
(g2x + g2y) + 16 mu2  <=  1
```

Sanity checks:
- membrane (`mu2 = 0`, `g2x = g2y = g^2`): `2 g^2 <= 1`, i.e. `g^2 <= 1/2`,
  exactly the CFL limit Courant already uses (`gamma2_max = 0.451`, issue #3);
- pure plate (`g2x = g2y = 0`): `mu2 <= 1/16`.

**The stiffness term tightens CFL**: every unit of `16 mu2` is stolen from the
wave headroom `(g2x + g2y)`, so a stiffer medium must run a lower wave speed for
the same grid.

### Confirmed against the model

`stiffness_study.m` sweeps `mu2` at fixed `g2x = g2y = g^2` and compares the
empirical stable maximum to the predicted `mu2 = (1 - 2 g^2)/16`:

| `g^2` (each axis) | predicted `mu2_max` | empirical `mu2_max` | match |
| --- | --- | --- | --- |
| 0.05 | 0.05625 | 0.05625 | yes |
| 0.10 | 0.05000 | 0.05000 | yes |
| 0.20 | 0.03750 | 0.03750 | yes |

The closed-form boundary is exact to the sweep resolution.

### Timbre (audio)

`stiffness_study.m` renders `model/outputs/{membrane,stiff_plate,anisotropic}.wav`.
The measured low partials show the expected behaviour: adding stiffness stretches
the partial ratios sharp (dispersion -> inharmonic bar/bell), and anisotropy
(`cx != cy`) splits the degenerate membrane modes into distinct frequencies (the
"oval drum"). The wavs are git-ignored artefacts; regenerate with
`octave-cli --eval "stiffness_study"`.

## Production RTL integration (#86)

### Control encoding and stability

STIFFNESS is stored in register 5 bits 23..16 and is latched per voice. The
production mapping deliberately makes zero an exact legacy bypass:

```
mu2 = STIFFNESS / 4096
gamma2_max_eff = min(gamma2_max, 0.5 - STIFFNESS/512)
```

The second expression is the studied bound specialized to RADIAN's current
anisotropy operator, which redistributes X/Y propagation while preserving
`g2x+g2y = 2*gamma2`. Thus every nonlinear local `gamma2` value is clamped
before the update can violate `(g2x+g2y)+16*mu2 <= 1`.

### Datapath

`physical_pkg.biharmonic_term` evaluates the 13-point operator with adds and
shifts. `physical_pkg.stiffness_term` implements `mu2*Biharm` as an eight-bit
shift/add multiply followed by the same round-then-shift convention as
`mul_coeff`; it therefore does not allocate another DSP multiplier.
`node_element` subtracts that term in stage 3 and keeps its four-clock
pipeline latency.

The fixed-boundary case uses zero padding outside the surface, matching the
reference study. Runtime free/compliant boundaries mirror the inward sample and
apply the existing RIM reflection law to the wider stencil as well.

### Spatial and time-multiplexed backends

The spatial backend forms the wider stencil directly from the live node grid.
The TDM backend avoids eight new simultaneous memory reads: four gather states
fetch two diagonal/second-ring taps per clock, followed by the normal update
state. These gather states are completely bypassed when STIFFNESS=0, preserving
legacy membrane timing.

For the production 8x8 TDM grid a nonzero-stiffness mesh step is **322 system
clocks**; at OS=4 that is 1288 mesh clocks per audio frame before the small
`mesh_resonator` handshake overhead, below the 2083-clock budget at
100 MHz / 48 kHz.

### Verification

- `model/stiffness_reference.py` independently regenerates the committed
  Q1.23 golden trace using the production 8-bit control encoding.
- `stiffness_tb` compares the TDM output to that golden trace, requires
  spatial/TDM bit equality, exercises fixed and free/compliant boundaries,
  checks the high-stiffness CFL clamp, and pins the 322-clock TDM step.
- The analytic discrete-mode check confirms dispersion rather than a global
  pitch shift: with STIFFNESS=0x60, mode (1,1) rises about **3.5%** while mode
  (4,4) rises about **41.9%**.
- Existing membrane golden tests remain bit-exact at STIFFNESS=0.

### Open-source synthesis snapshot

Using GHDL 6.0's built-in VHDL synthesis followed by Yosys 0.68
`synth_xilinx -family xc7`:

| block | DSP48E1 | LUT1..6 | FF |
| --- | ---: | ---: | ---: |
| `node_element` with runtime STIFFNESS | **18** | 1,911 | 480 |
| 8x8 `grid_mesh_tdm` with runtime STIFFNESS | **18** | 28,575 | 3,615 |

The binding result is that STIFFNESS adds **no DSPs** to the mesh. The LUT number
is intentionally not treated as a board-fit verdict: this open-source flow
expands the multi-read TDM state into mux fabric, and the wider plate stencil
makes that pessimism more visible. Vivado implementation on the XC7A50T remains
the physical resource/timing sign-off.

## Status

The #31 recommendation is now implemented rather than conditional. RADIAN can
continuously move from the legacy tension-dominated membrane at STIFFNESS=0
toward dispersive stiff sheets/plates while retaining the same preset format and
physical panel hardware.

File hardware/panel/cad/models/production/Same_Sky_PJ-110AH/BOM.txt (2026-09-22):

3DX_Same_Sky_Supplier: Same Sky
3DX_Same_Sky_Description: 2.0 x 6.0 mm, 5.0 A, Vertical, Through Hole, Shielded, Dc Power Jack Connector
3DX_Same_Sky_Model Number: PJ-110AH

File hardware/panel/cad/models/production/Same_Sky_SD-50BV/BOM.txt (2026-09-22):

3DX_Same_Sky_Supplier: Same Sky
3DX_Same_Sky_Description: Din Receptacle, Vertical, PCB  5P
3DX_Same_Sky_Model Number: SD-50BV

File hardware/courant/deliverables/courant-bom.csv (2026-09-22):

Reference(s) | Qty | Value | Footprint | Side | Manufacturer | MPN | LCSC | Notes
C101,C102,C106,C107,C108,C109,C112,C114,C115,C118,C119,C121,C124,C125,C126,C127,C136 | 17 | 100nF | RadianMain:C_0201_0603Metric_D | bottom | CCTC | TCC0201X5R104K100ZT | C5142565 | 10 V X5R. JLC extended library: one setup fee for the whole array
C11,C21,C31,C146,C150,C151,C152,C161,C162,C166,C170,C172,C190,C195,C200 | 15 | 100nF | RadianMain:C_0603_1608Metric_Radian | top | Samsung | CL10B104KB8NNNC | C1591 | 50 V X7R
R12,R22,R32,R103,R104,R105,R106,R121,R130,R143,R144,R145,R146,R169 | 14 | 10kΩ | RadianMain:R_0603_1608Metric_Radian | top | Yageo | RC0603FR-0710KL | C98220 | thick film 1%
R131,R132,R133,R140,R141,R142,R147,R148,R149,R150,R190,R191,R192 | 13 | 1kΩ | RadianMain:R_0603_1608Metric_Radian | top | Yageo | RC0603FR-071KL |  | thick film 1%
C100,C103,C104,C110,C113,C116,C120,C122,C128 | 9 | 100nF | RadianMain:C_0201_0603Metric_C | bottom | CCTC | TCC0201X5R104K100ZT | C5142565 | 10 V X5R. JLC extended library: one setup fee for the whole array
C105,C123,C130,C131,C132,C133,C134,C135 | 8 | 100nF | RadianMain:C_0201_0603Metric_E | bottom | CCTC | TCC0201X5R104K100ZT | C5142565 | 10 V X5R. JLC extended library: one setup fee for the whole array
C174,C175,C176,C180,C181,C182,C193,C194 | 8 | 10nF | RadianMain:C_0603_1608Metric_Radian | top | Murata | GRM1885C1H103JA01D | C85973 | 50 V C0G -- ADC anti-alias, C0G for low voltage coefficient
R110,R114,R115,R122,R123,R124,R125 | 7 | 33Ω | RadianMain:R_0603_1608Metric_Radian | top | Yageo | RC0603FR-0733RL |  | thick film 1%
R100,R101,R102,R111,R112,R113 | 6 | 4.7kΩ | RadianMain:R_0603_1608Metric_Radian | top | Yageo | RC0603FR-074K7L |  | thick film 1%
R11,R21,R31,R166 | 4 | 100kΩ | RadianMain:R_0603_1608Metric_Radian | top | Yageo | RC0603FR-07100KL |  | thick film 1%
C10,C20,C30,C160 | 4 | 10uF | RadianMain:C_0805_2012Metric_B | top | Samsung | CL21A106KAYNNNE | C15850 | 25 V X5R, JLC basic library
R160,R161,R163,R164 | 4 | 20kΩ | RadianMain:R_0603_1608Metric_Radian | top | Yageo | RT0603BRD0720KL | C723637 | 0.1%, 25 ppm/C thin film -- matched CV divider pair
C111,C117,C129 | 3 | 100nF | RadianMain:C_0201_0603Metric_A | bottom | CCTC | TCC0201X5R104K100ZT | C5142565 | 10 V X5R. JLC extended library: one setup fee for the whole array
C201,C202,C203 | 3 | 10nF | RadianMain:C_0603_1608Metric_Radian | bottom | Murata | GRM1885C1H103JA01D | C85973 | 50 V C0G -- ADC anti-alias, C0G for low voltage coefficient
C191,C192,C196 | 3 | 1nF | RadianMain:C_0603_1608Metric_Radian | top | Murata | GRM1885C1H102JA01D |  | 50 V C0G, same series as the 10 nF
C165,C171,C173 | 3 | 1uF | RadianMain:C_0603_1608Metric_Radian | top | Samsung | CL10B105KB8NQNC | C5199872 | 50 V X7R
L1,L2,L3 | 3 | 1µH | RadianMain:Changjiang_FNR4030S1R0MT | top | Changjiang Electronics | FNR4030S1R0MT | C167865 | 4x4 mm shielded, 18 mOhm, 5.7 A sat -- must exceed the TPS62130's 3 A plus ripple
C13,C23,C33 | 3 | 22uF | RadianMain:C_0805_2012Metric_B | top | Samsung | CL21A226MAQNNNE | C45783 | 25 V X5R, JLC basic library -- switcher output
C12,C22,C32 | 3 | 22uF | RadianMain:C_0805_2012Metric_A | top | Samsung | CL21A226MAQNNNE | C45783 | 25 V X5R, JLC basic library -- switcher output
C14,C24,C34 | 3 | 3.3nF | RadianMain:C_0603_1608Metric_Radian | top | Murata | GRM1885C1H332JA01D |  | 50 V C0G -- switcher soft-start
C1,C140,C141 | 3 | 47uF | RadianMain:C_1210_3225Metric_A | top | Murata | GRM32ER61C476KE15L | C77101 | 16 V X5R -- bulk input
D10,D11,D12 | 3 | BAT54S | RadianMain:Nexperia_BAT54S_215_SOT23 | top | Nexperia | BAT54S,215 |  | Nexperia BAT54S,215; SOT-23 dual Schottky diode
U11,U12,U13 | 3 | TPS62130ARGTR | RadianMain:TPS62130ARGTR_WQFN16 | top | Texas Instruments | TPS62130ARGTR |  | 3 A buck, QFN-16 with exposed pad
R162,R165 | 2 | 100Ω | RadianMain:R_0603_1608Metric_Radian | top | Yageo | RC0603FR-07100RL |  | thick film 1%
C167,C168 | 2 | 2.2nF | RadianMain:C_0603_1608Metric_Radian | top | Murata | GRM1885C1H222JA01D |  | 50 V C0G, same series
C163,C164 | 2 | 2.2uF | RadianMain:C_0603_1608Metric_Radian | top | Samsung | CL10A225KO8NNNC | C23630 | 16 V X5R, JLC basic library
C143,C144 | 2 | 4.7uF | RadianMain:C_0805_2012Metric_B | top | Yageo | CC0805KKX7R8BB475 | C354262 | 25 V X7R
R126,R127 | 2 | 470Ω | RadianMain:R_0603_1608Metric_Radian | top | Yageo | RC0603FR-07470RL |  | thick film 1%
J17,J18 | 2 | IPT1-110-06-L-D | RadianMain:Samtec_IPT1_110_06_L_D | top | Samtec | IPT1-110-06-L-D |  | 2x10 2.54 mm vertical through-hole terminal strip; mates IPS1-110-01-L-D. Fully-mated PCB gap 19.99 mm; 20.45 mm max.
C137 | 1 | 100nF | RadianMain:C_0201_0603Metric_B | bottom | CCTC | TCC0201X5R104K100ZT | C5142565 | 10 V X5R. JLC extended library: one setup fee for the whole array
R20 | 1 | 124kΩ | RadianMain:R_0603_1608Metric_Radian | top | Yageo | RC0603FR-07124KL |  | thick film 1%
D20 | 1 | 1N4148W | RadianMain:Diodes_1N4148W_7_F_SOD123 | top | Diodes Incorporated | 1N4148W-7-F |  | Diodes Incorporated 1N4148W-7-F; SOD-123 fast switching diode
J4,J3 | 2 | 22-23-2021 | RadianMain:Molex_22_23_2021_RowX | top | Molex | 22-23-2021 |  | KK 254 vertical friction-lock. Harness side: housing 22-01-3027 + 2 x 08-55-0102 crimp terminals
J1 | 1 | 22-23-2021 | RadianMain:Molex_22_23_2021_RowY | top | Molex | 22-23-2021 |  | KK 254 vertical friction-lock. Harness side: housing 22-01-3027 + 2 x 08-55-0102 crimp terminals
J2 | 1 | 22-23-2061 | RadianMain:Molex_22_23_2061 | top | Molex | 22-23-2061 |  | KK 254 vertical friction-lock. Harness side: housing 22-01-3067 + 6 x 08-55-0102 crimp terminals
R120 | 1 | 1Ω | RadianMain:R_0603_1608Metric_Radian | top | Yageo | RC0603FR-071RL |  | thick film 1%
R181 | 1 | 2.2kΩ | RadianMain:R_0603_1608Metric_Radian | top | Yageo | RC0603FR-072K2L |  | thick film 1%
R180 | 1 | 220Ω | RadianMain:R_0603_1608Metric_Radian | top | Yageo | RC0603FR-07220RL |  | thick film 1%
R10 | 1 | 24.9kΩ | RadianMain:R_0603_1608Metric_Radian | top | Yageo | RC0603FR-0724K9L | C137761 | thick film 1%
R30 | 1 | 316kΩ | RadianMain:R_0603_1608Metric_Radian | top | Yageo | RC0603FR-07316KL |  | thick film 1%
R167 | 1 | 33kΩ | RadianMain:R_0603_1608Metric_Radian | top | Yageo | RC0603FR-0733KL |  | thick film 1%
C145 | 1 | 4.7uF | RadianMain:C_0805_2012Metric_A | top | Yageo | CC0805KKX7R8BB475 | C354262 | 25 V X7R
R168 | 1 | 40.2kΩ | RadianMain:R_0603_1608Metric_Radian | top | Yageo | RC0603FR-0740K2L |  | thick film 1%
C142 | 1 | 47uF | RadianMain:C_1210_3225Metric_B | top | Murata | GRM32ER61C476KE15L | C77101 | 16 V X5R -- bulk input
Y1 | 1 | ASE-100.000MHZ-LC-T | RadianMain:Abracon_ASE_3225_4Pin | top | Abracon | ASE-100.000MHZ-LC-T |  | 100 MHz system oscillator
Y2 | 1 | ASE-12.288MHZ-LC-T | RadianMain:Abracon_ASE_3225_4Pin | top | Abracon | ASE-12.288MHZ-LC-T |  | 12.288 MHz audio master clock
U8 | 1 | H11L1M | RadianMain:H11L1M_DIP6 | top | onsemi | H11L1M |  | Schmitt optocoupler, MIDI input
U4 | 1 | MCP3208-CI/SL | RadianMain:MCP3208_CI_SL_SOIC16 | top | Microchip | MCP3208-CI/SL |  | 8-ch 12-bit SPI ADC
U6 | 1 | MCP6002-I/SN | RadianMain:MCP6002_I_SN_SOIC8 | top | Microchip | MCP6002-I/SN |  | dual op-amp, CV buffer
U7 | 1 | MCP6561T-E/OT | RadianMain:MCP6561T_E_OT_SOT23_5 | top | Microchip | MCP6561T-E/OT |  | comparator, gate input
U3 | 1 | PCM5102APWR | RadianMain:PCM5102APWR_TSSOP20 | top | Texas Instruments | PCM5102APWR |  | stereo audio DAC
U5 | 1 | REF3125AIDBZR | RadianMain:REF3125AIDBZR_SOT23 | top | Texas Instruments | REF3125AIDBZR |  | 2.5 V reference
U2 | 1 | W25Q64JVSSIQ | RadianMain:W25Q64JVSSIQ_SOIC8_208mil | top | Winbond | W25Q64JVSSIQ |  | 64 Mbit SPI flash
U1 | 1 | XC7A50T-1FTG256I | RadianMain:XC7A50T_1FTG256I_FTG256 | top | AMD/Xilinx | XC7A50T-1FTG256I | C3272410 | FPGA, 52160 logic cells, industrial temp

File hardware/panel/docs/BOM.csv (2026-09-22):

Reference | Value | Manufacturer | MPN_or_selection_gate | Footprint | Side | X_panel_mm | Y_panel_mm | DNP | Notes
J100 | IPS1-110-01-L-D | Samtec | IPS1-110-01-L-D | RadianPanel:Stack_2x10_P2.54 | B | 124.0 | 61.75 | False | Direct mezzanine A; Samtec IPS1 socket mates mainboard IPT1-110-06-L-D. Fully-mated PCB gap 19.99 mm; max 20.45 mm. Use ~20.0 mm standoffs and bench-verify seating before production quantity.
J101 | IPS1-110-01-L-D | Samtec | IPS1-110-01-L-D | RadianPanel:Stack_2x10_P2.54 | B | 43.0 | 72.25 | False | Direct mezzanine B; Samtec IPS1 socket mates mainboard IPT1-110-06-L-D. Fully-mated PCB gap 19.99 mm; max 20.45 mm. Use ~20.0 mm standoffs and bench-verify seating before production quantity.
RV1 | 10k linear / TENSION | Bourns | PTV09A-4020F-B103 | RadianPanel:Bourns_PTV09A4_RearFacing | F | 38.0 | 96.0 | False | Pin 1 CCW/GND, pin 3 CW/VREF25: verify direction on physical sample. No added wiper RC. Mount tabs soldered, electrically NC.
RV2 | 10k linear / DECAY | Bourns | PTV09A-4020F-B103 | RadianPanel:Bourns_PTV09A4_RearFacing | F | 76.0 | 96.0 | False | Pin 1 CCW/GND, pin 3 CW/VREF25: verify direction on physical sample. No added wiper RC. Mount tabs soldered, electrically NC.
RV3 | 10k linear / CHAOS | Bourns | PTV09A-4020F-B103 | RadianPanel:Bourns_PTV09A4_RearFacing | F | 114.0 | 96.0 | False | Pin 1 CCW/GND, pin 3 CW/VREF25: verify direction on physical sample. No added wiper RC. Mount tabs soldered, electrically NC.
RV4 | 10k linear / DRIVE | Bourns | PTV09A-4020F-B103 | RadianPanel:Bourns_PTV09A4_RearFacing | F | 66.0 | 70.0 | False | Pin 1 CCW/GND, pin 3 CW/VREF25: verify direction on physical sample. No added wiper RC. Mount tabs soldered, electrically NC.
RV5 | 10k linear / DELAY | Bourns | PTV09A-4020F-B103 | RadianPanel:Bourns_PTV09A4_RearFacing | F | 88.0 | 70.0 | False | Pin 1 CCW/GND, pin 3 CW/VREF25: verify direction on physical sample. No added wiper RC. Mount tabs soldered, electrically NC.
RV6 | 10k linear / REVERB | Bourns | PTV09A-4020F-B103 | RadianPanel:Bourns_PTV09A4_RearFacing | F | 110.0 | 70.0 | False | Pin 1 CCW/GND, pin 3 CW/VREF25: verify direction on physical sample. No added wiper RC. Mount tabs soldered, electrically NC.
ENC1 | 24 PPR / PUSH | Bourns | PEC11R-4220F-S0024 | RadianPanel:Bourns_PEC11R4_RearFacing_Switch | F | 42.0 | 43.0 | False | 20 mm shaft / 7 mm bushing replaces proposed 15 mm shaft part to accommodate common PCB plane. Check encoder direction and nut stack.
SW1 | MODE / SPDT ON-ON | E-Switch | 100SP1T1B1M2REH | RadianPanel:E_Switch_100SP_M2 | F | 150.5 | 84.5 | False | Gold contact option for low-level logic. ST110001 mechanical M2 pattern, 4.7 mm pitch. R contact selection from manufacturer configurator; purchase/stack validation required.
D10 | VOICE 1 | Kingbright | L-934GD | RadianPanel:LED_D3.0_P2.54 | F | 124.0 | 108.0 | False | 3 mm LED, anode pad 2, cathode pad 1. Mainboard already has series resistor. Set flange height with assembly jig; envelope is not seated LED height.
D11 | VOICE 2 | Kingbright | L-934GD | RadianPanel:LED_D3.0_P2.54 | F | 134.0 | 108.0 | False | 3 mm LED, anode pad 2, cathode pad 1. Mainboard already has series resistor. Set flange height with assembly jig; envelope is not seated LED height.
D12 | VOICE 3 | Kingbright | L-934GD | RadianPanel:LED_D3.0_P2.54 | F | 144.0 | 108.0 | False | 3 mm LED, anode pad 2, cathode pad 1. Mainboard already has series resistor. Set flange height with assembly jig; envelope is not seated LED height.
D13 | VOICE 4 | Kingbright | L-934GD | RadianPanel:LED_D3.0_P2.54 | F | 154.0 | 108.0 | False | 3 mm LED, anode pad 2, cathode pad 1. Mainboard already has series resistor. Set flange height with assembly jig; envelope is not seated LED height.
J301 | PITCH 0-5V | QingPu / Thonk | WQP518MA (Thonkiconn/PJ398SM) | RadianPanel:WQP518MA_PJ398SM_Vertical | F | 186.5 | 99.0 | False | Vertical mono, grounded normal for inputs only. Sleeve=1, switched contact=2, tip=3. Imported supplier dimension drawing needs sample fit check.
J302 | MOD | QingPu / Thonk | WQP518MA (Thonkiconn/PJ398SM) | RadianPanel:WQP518MA_PJ398SM_Vertical | F | 186.5 | 81.0 | False | Vertical mono, grounded normal for inputs only. Sleeve=1, switched contact=2, tip=3. Imported supplier dimension drawing needs sample fit check.
J303 | GATE | QingPu / Thonk | WQP518MA (Thonkiconn/PJ398SM) | RadianPanel:WQP518MA_PJ398SM_Vertical | F | 186.5 | 63.0 | False | Vertical mono, grounded normal for inputs only. Sleeve=1, switched contact=2, tip=3. Imported supplier dimension drawing needs sample fit check.
J304 | LINE L | QingPu / Thonk | WQP518MA (Thonkiconn/PJ398SM) | RadianPanel:WQP518MA_PJ398SM_Vertical | F | 186.5 | 45.0 | False | Vertical mono, grounded normal for inputs only. Sleeve=1, switched contact=2, tip=3. Imported supplier dimension drawing needs sample fit check.
J305 | LINE R | QingPu / Thonk | WQP518MA (Thonkiconn/PJ398SM) | RadianPanel:WQP518MA_PJ398SM_Vertical | F | 186.5 | 27.0 | False | Vertical mono, grounded normal for inputs only. Sleeve=1, switched contact=2, tip=3. Imported supplier dimension drawing needs sample fit check.
J306 | 22-27-2021 | Molex | 22-27-2021 | RadianPanel:Molex_22-27-2021_J306_B | B | 57.5 | 39.0 | False | Exact KK-254 2-circuit friction-lock header to retained Same Sky SDS-50J MIDI DIN pins 4 and 5. No DIN 2/shield-to-GND connection.
J200 | 61201021621 | Wurth Elektronik | 61201021621 | RadianPanel:Wurth_61201021621_Exact_B | B | 174.0 | 64.0 | False | Exact keyed WR-BHD 2x5 2.54 mm header. Module-side 10-pin: 1/2=-12 NC, 3-8=GND, 9/10=+12. Use 16-to-10 cable to bus. Red stripe at pins 1/2; verify both cable ends. No bus +5/CV/gate connections.
J201 | 22-27-2021 | Molex | 22-27-2021 | RadianPanel:Molex_22-27-2021_J201_B | B | 26.0 | 52.0 | False | Exact KK-254 2-circuit friction-lock header from the chassis-mounted 12 V DC inlet. NOT a 5 V inlet.
F1 | 2A FUSE / >=32V |  | SELECT 2 A >=32 V 1206 fuse | RadianPanel:Fuse_1206 | F | 53.0 | 65.0 | False | Final fuse MPN, surge rating, derating and TVS coordination are an explicit release gate.
F2 | 2A FUSE / >=32V |  | SELECT 2 A >=32 V 1206 fuse | RadianPanel:Fuse_1206 | F | 26.0 | 59.0 | False | Final fuse MPN, surge rating, derating and TVS coordination are an explicit release gate.
D1 | SS54 / OR | Vishay | SS54-E3/57T | RadianPanel:D_SMB | F | 44.0 | 65.0 | False | Pad 1 cathode VRAW, pad 2 anode fused source. Diode OR, no priority, shared ground. Measure worst-case diode temperature.
D2 | SS54 / OR | Vishay | SS54-E3/57T | RadianPanel:D_SMB | F | 35.0 | 59.0 | False | Pad 1 cathode VRAW, pad 2 anode fused source. Diode OR, no priority, shared ground. Measure worst-case diode temperature.
D3 | SMBJ15A | Vishay | SMBJ15A-E3/52 | RadianPanel:D_SMB | F | 25.0 | 46.0 | False | Unidirectional input TVS. Verify source fault energy and fuse coordination before any fault test.
U1 | TPS54302DDCR | Texas Instruments | TPS54302DDCR | RadianPanel:TI_DDC0006A_SOT23_6 | F | 34.0 | 25.0 | False | 3 A IC rating is a design target, not validated system delivery. TI March 2026 datasheet 5 V reference circuit.
L1 | 10uH 4A / Isat7.5A | Bourns | SRP7050TA-100M | RadianPanel:Bourns_SRP7050TA | F | 26.0 | 25.0 | False | 4 A Irms / 7.5 A Isat at stated datasheet conditions; temperature rise needs testing.
C1 | 10uF |  | SELECT 10uF 50V X7R 1210 | RadianPanel:C_1210 | F | 31.0 | 18.0 | False | 50V X7R; verify effective capacitance at DC bias
C2 | 100nF |  | SELECT 100nF 50V X7R 0603 | RadianPanel:C_0603 | F | 32.0 | 21.5 | False | 50V X7R; verify effective capacitance at DC bias
C3 | 100nF |  | SELECT 100nF 16V X7R 0603 | RadianPanel:C_0603 | F | 34.0 | 29.0 | False | 16V X7R; verify effective capacitance at DC bias
C4 | 22uF |  | SELECT 22uF 25V X7R 1210 | RadianPanel:C_1210 | F | 23.0 | 33.0 | False | 25V X7R; verify effective capacitance at DC bias
C5 | 22uF |  | SELECT 22uF 25V X7R 1210 | RadianPanel:C_1210 | F | 29.0 | 33.0 | False | 25V X7R; verify effective capacitance at DC bias
R1 | 100k |  | SELECT 100k 1% 0603 | RadianPanel:R_0603 | F | 39.5 | 27.0 | False | Resistor 1%
R2 | 13.3k |  | SELECT 13.3k 1% 0603 | RadianPanel:R_0603 | F | 39.0 | 20.0 | False | Resistor 1%
R3 | 511k |  | SELECT 511k 1% 0603 | RadianPanel:R_0603 | F | 46.0 | 23.0 | False | Resistor 1%
R4 | 105k |  | SELECT 105k 1% 0603 | RadianPanel:R_0603 | F | 43.0 | 19.0 | False | Resistor 1%
R5 | 49.9 |  | SELECT 49.9 1% 0603 | RadianPanel:R_0603 | F | 39.0 | 32.0 | False | Resistor 1%
C6 | 75pF |  | SELECT 75pF 50V C0G 0603 | RadianPanel:C_0603 | F | 43.0 | 27.0 | False | 50V C0G; verify effective capacitance at DC bias
C7 | 10uF |  | SELECT 10uF 50V X7R 1210 | RadianPanel:C_1210 | F | 43.0 | 59.0 | False | 50V X7R; verify effective capacitance at DC bias
JP1 | 450301014042 | Wurth Elektronik | 450301014042 | RadianPanel:Wurth_450301014042_Exact_B | B | 165.5 | 88.0 | False | Actual SPDT configuration switch replaces the removable shunt. One throw selects direct unipolar MOD_RAW; the other selects MOD_BIPOLAR. NOT the front MODE switch.
U2 | OPA2192ID | Texas Instruments | OPA2192ID | RadianPanel:SOIC8_3.9x4.9_P1.27 | F | 151.0 | 67.0 | False | A buffers VREF25. B is non-inverting gain 2. 5 V single supply, output headroom limits rail endpoints; not rail-perfect mapping.
R20 | 200k |  | SELECT 200k 0.1% 0603 | RadianPanel:R_0603 | F | 164.0 | 75.0 | False | Resistor 0.1%
R21 | 100k |  | SELECT 100k 0.1% 0603 | RadianPanel:R_0603 | F | 158.0 | 75.0 | False | Resistor 0.1%
R22 | 200k |  | SELECT 200k 0.1% 0603 | RadianPanel:R_0603 | F | 164.0 | 71.0 | False | Resistor 0.1%
R23 | 10k |  | SELECT 10k 0.1% 0603 | RadianPanel:R_0603 | F | 159.5 | 57.0 | False | Resistor 0.1%
R24 | 10k |  | SELECT 10k 0.1% 0603 | RadianPanel:R_0603 | F | 163.0 | 59.0 | False | Resistor 0.1%
D4 | BAT54S | Nexperia | BAT54S,215 | RadianPanel:SOT23_BAT54S | F | 166.0 | 65.0 | False | Series diode pair clamp: 1=bottom anode, 2=top cathode, 3=junction. Verify powered and unpowered fault behavior.
C20 | 100nF |  | SELECT 100nF 16V X7R 0603 | RadianPanel:C_0603 | F | 157.0 | 69.0 | False | 16V X7R; verify effective capacitance at DC bias
C21 | 1uF |  | SELECT 1uF 16V X7R 0805 | RadianPanel:C_0805 | F | 149.0 | 74.0 | False | 16V X7R; verify effective capacitance at DC bias
J202 | 22-27-2061 | Molex | 22-27-2061 | RadianPanel:Molex_22-27-2061_J202_B | B | 131.0 | 29.0 | False | Exact KK-254 6-circuit friction-lock service header; pin-for-pin to the JTAG nets already carried through J101/J18. No level conversion; validate JTAG frequency.
SW3 | PROGRAM / SERVICE | Omron | B3F-1000 | RadianPanel:SW_PUSH_6x6_P6.5x4.5 | B | 118.4 | 25.0 | False | Internal service push button, accessible after module removal.
SW4 | RESET / SERVICE | Omron | B3F-1000 | RadianPanel:SW_PUSH_6x6_P6.5x4.5 | B | 146.0 | 26.0 | False
TP1 | GND |  | PCB test pad | RadianPanel:TestPoint_D2 | B | 25.0 | 42.0 | False | Exposed soldermask aperture, no component.
TP2 | VIN5 |  | PCB test pad | RadianPanel:TestPoint_D2 | B | 29.0 | 42.0 | False | Exposed soldermask aperture, no component.
TP3 | VRAW |  | PCB test pad | RadianPanel:TestPoint_D2 | B | 48.0 | 59.0 | False | Exposed soldermask aperture, no component.
TP4 | VREF25 |  | PCB test pad | RadianPanel:TestPoint_D2 | B | 149.0 | 62.0 | False | Exposed soldermask aperture, no component.
TP5 | MOD_BIPOLAR |  | PCB test pad | RadianPanel:TestPoint_D2 | B | 165.0 | 61.0 | False | Exposed soldermask aperture, no component.

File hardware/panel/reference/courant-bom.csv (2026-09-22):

Reference(s) | Qty | Value | Footprint | Side | Manufacturer | MPN | LCSC | Notes
C100,C101,C102,C103,C104,C105,C106,C107,C108,C109,C110,C111,C112,C113,C114,C115,C116,C117,C118,C119,C120,C121,C122,C123,C124,C125,C126,C127,C128,C129,C130,C131,C132,C133,C134,C135,C136,C137 | 38 | 100nF | capacitor_cap0201 | bottom | CCTC | TCC0201X5R104K100ZT | C5142565 | 10 V X5R. JLC extended library: one setup fee for the whole array
C11,C21,C31,C146,C150,C151,C152,C161,C162,C166,C170,C172,C190,C195,C200 | 15 | 100nF | capacitor_cap0603 | top | Samsung | CL10B104KB8NNNC | C1591 | 50 V X7R
R12,R22,R32,R103,R104,R105,R106,R121,R130,R143,R144,R145,R146,R169 | 14 | 10kΩ | resistor_res0603 | top | Yageo | RC0603FR-0710KL | C98220 | thick film 1%
R131,R132,R133,R140,R141,R142,R147,R148,R149,R150 | 10 | 1kΩ | resistor_res0603 | top | Yageo | RC0603FR-071KL |  | thick film 1%
C174,C175,C176,C180,C181,C182,C193,C194 | 8 | 10nF | capacitor_cap0603 | top | Murata | GRM1885C1H103JA01D | C85973 | 50 V C0G -- ADC anti-alias, C0G for low voltage coefficient
R110,R114,R115,R122,R123,R124,R125 | 7 | 33Ω | resistor_res0603 | top | Yageo | RC0603FR-0733RL |  | thick film 1%
C12,C13,C22,C23,C32,C33 | 6 | 22uF | capacitor_cap0805 | top | Samsung | CL21A226MAQNNNE | C45783 | 25 V X5R, JLC basic library -- switcher output
R100,R101,R102,R111,R112,R113 | 6 | 4.7kΩ | resistor_res0603 | top | Yageo | RC0603FR-074K7L |  | thick film 1%
R11,R21,R31,R166 | 4 | 100kΩ | resistor_res0603 | top | Yageo | RC0603FR-07100KL |  | thick film 1%
C10,C20,C30,C160 | 4 | 10uF | capacitor_cap0805 | top | Samsung | CL21A106KAYNNNE | C15850 | 25 V X5R, JLC basic library
R160,R161,R163,R164 | 4 | 20kΩ | resistor_res0603 | top | Yageo | RT0603BRD0720KL | C723637 | 0.1%, 25 ppm/C thin film -- matched CV divider pair
C1,C140,C141,C142 | 4 | 47uF | capacitor_cap1210 | top | Murata | GRM32ER61C476KE15L | C77101 | 16 V X5R -- bulk input
C191,C192,C196 | 3 | 1nF | capacitor_cap0603 | top | Murata | GRM1885C1H102JA01D |  | 50 V C0G, same series as the 10 nF
C165,C171,C173 | 3 | 1uF | capacitor_cap0603 | top | Samsung | CL10B105KB8NQNC | C5199872 | 50 V X7R
L1,L2,L3 | 3 | 1µH | inductor | top | cjiang | FNR4030S1R0MT | C167865 | 4x4 mm shielded, 18 mOhm, 5.7 A sat -- must exceed the TPS62130's 3 A plus ripple
C14,C24,C34 | 3 | 3.3nF | capacitor_cap0603 | top | Murata | GRM1885C1H332JA01D |  | 50 V C0G -- switcher soft-start
C143,C144,C145 | 3 | 4.7uF | capacitor_cap0805 | top | Yageo | CC0805KKX7R8BB475 | C354262 | 25 V X7R
D10,D11,D12 | 3 | BAT54S | BAT54S | top |  | BAT54S |  | dual Schottky, CV input clamp
U11,U12,U13 | 3 | TPS62130ARGTR | TPS62130ARGTR | top | Texas Instruments | TPS62130ARGTR |  | 3 A buck, QFN-16 with exposed pad
R162,R165 | 2 | 100Ω | resistor_res0603 | top | Yageo | RC0603FR-07100RL |  | thick film 1%
C167,C168 | 2 | 2.2nF | capacitor_cap0603 | top | Murata | GRM1885C1H222JA01D |  | 50 V C0G, same series
C163,C164 | 2 | 2.2uF | capacitor_cap0603 | top | Samsung | CL10A225KO8NNNC | C23630 | 16 V X5R, JLC basic library
R126,R127 | 2 | 470Ω | resistor_res0603 | top | Yageo | RC0603FR-07470RL |  | thick film 1%
R20 | 1 | 124kΩ | resistor_res0603 | top | Yageo | RC0603FR-07124KL |  | thick film 1%
D20 | 1 | 1N4148W | 1N4148W | top |  | 1N4148W |  | signal diode
J12 | 1 | 1x02 header | PITCH_CV_GND | top |  | 1x02 2.54 mm header, vertical THT |  | panel harness connector -- mates to off-board hardware
J4 | 1 | 1x02 header | RESET_GND | top |  | 1x02 2.54 mm header, vertical THT |  | panel harness connector -- mates to off-board hardware
J1 | 1 | 1x02 header | 5V_INPUT | top |  | 1x02 2.54 mm header, vertical THT |  | panel harness connector -- mates to off-board hardware
J15 | 1 | 1x02 header | MIDI_DIN4_DIN5 | top |  | 1x02 2.54 mm header, vertical THT |  | panel harness connector -- mates to off-board hardware
J13 | 1 | 1x02 header | MOD_CV_GND | top |  | 1x02 2.54 mm header, vertical THT |  | panel harness connector -- mates to off-board hardware
J14 | 1 | 1x02 header | GATE_GND | top |  | 1x02 2.54 mm header, vertical THT |  | panel harness connector -- mates to off-board hardware
J3 | 1 | 1x02 header | PROGRAM_GND | top |  | 1x02 2.54 mm header, vertical THT |  | panel harness connector -- mates to off-board hardware
J7 | 1 | 1x03 header | POT_DECAY_REF_WIPER_GND | top |  | 1x03 2.54 mm header, vertical THT |  | panel harness connector -- mates to off-board hardware
J6 | 1 | 1x03 header | POT_PITCH_REF_WIPER_GND | top |  | 1x03 2.54 mm header, vertical THT |  | panel harness connector -- mates to off-board hardware
J8 | 1 | 1x03 header | POT_TIMBRE_REF_WIPER_GND | top |  | 1x03 2.54 mm header, vertical THT |  | panel harness connector -- mates to off-board hardware
J5 | 1 | 1x03 header | STEREO_LINE_OUT_L_G_R | top |  | 1x03 2.54 mm header, vertical THT |  | panel harness connector -- mates to off-board hardware
J10 | 1 | 1x03 header | MODE_3V3_CV_SEL_GND | top |  | 1x03 2.54 mm header, vertical THT |  | panel harness connector -- mates to off-board hardware
J9 | 1 | 1x05 header | ENCODER_A_GND_B_SW_GND | top |  | 1x05 2.54 mm header, vertical THT |  | panel harness connector -- mates to off-board hardware
J11 | 1 | 1x05 header | STATUS_GND_VOICE0_3 | top |  | 1x05 2.54 mm header, vertical THT |  | panel harness connector -- mates to off-board hardware
J2 | 1 | 1x06 header | JTAG_VREF_GND_TCK_TDO_TDI_TMS | top |  | 1x06 2.54 mm header, vertical THT |  | panel harness connector -- mates to off-board hardware
R120 | 1 | 1Ω | resistor_res0603 | top | Yageo | RC0603FR-071RL |  | thick film 1%
R181 | 1 | 2.2kΩ | resistor_res0603 | top | Yageo | RC0603FR-072K2L |  | thick film 1%
R180 | 1 | 220Ω | resistor_res0603 | top | Yageo | RC0603FR-07220RL |  | thick film 1%
R10 | 1 | 24.9kΩ | resistor_res0603 | top | Yageo | RC0603FR-0724K9L | C137761 | thick film 1%
R30 | 1 | 316kΩ | resistor_res0603 | top | Yageo | RC0603FR-07316KL |  | thick film 1%
R167 | 1 | 33kΩ | resistor_res0603 | top | Yageo | RC0603FR-0733KL |  | thick film 1%
R168 | 1 | 40.2kΩ | resistor_res0603 | top | Yageo | RC0603FR-0740K2L |  | thick film 1%
Y1 | 1 | ASE-100.000MHZ-LC-T | ASE-100_000MHZ-LC-T | top | Abracon | ASE-100.000MHZ-LC-T |  | 100 MHz system oscillator
Y2 | 1 | ASE-12.288MHZ-LC-T | ASE-12_288MHZ-LC-T | top | Abracon | ASE-12.288MHZ-LC-T |  | 12.288 MHz audio master clock
U8 | 1 | H11L1M | H11L1M | top | onsemi | H11L1M |  | Schmitt optocoupler, MIDI input
U4 | 1 | MCP3208-CI/SL | MCP3208-CI_SL | top | Microchip | MCP3208-CI/SL |  | 8-ch 12-bit SPI ADC
U6 | 1 | MCP6002-I/SN | MCP6002-I_SN | top | Microchip | MCP6002-I/SN |  | dual op-amp, CV buffer
U7 | 1 | MCP6561T-E/OT | MCP6561T-E_OT | top | Microchip | MCP6561T-E/OT |  | comparator, gate input
U3 | 1 | PCM5102APWR | PCM5102APWR | top | Texas Instruments | PCM5102APWR |  | stereo audio DAC
U5 | 1 | REF3125AIDBZR | REF3125AIDBZR | top | Texas Instruments | REF3125AIDBZR |  | 2.5 V reference
U2 | 1 | W25Q64JVSSIQ | W25Q64JVSSIQ | top | Winbond | W25Q64JVSSIQ |  | 64 Mbit SPI flash
U1 | 1 | XC7A50T-1FTG256I | XC7A35T-1FTG256C | top | AMD/Xilinx | XC7A50T-1FTG256I | C3272410 | FPGA, 52160 logic cells, industrial temp

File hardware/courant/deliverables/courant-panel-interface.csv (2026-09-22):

Connector | Pin | Net | Purpose
J1 | 1 | VIN5 | 5 V DC input, externally fused
J1 | 2 | GND | 5 V DC input, externally fused
J2 | 1 | V3V3 | JTAG, to programmer
J2 | 2 | GND | JTAG, to programmer
J2 | 3 | JTAG_TCK | JTAG, to programmer
J2 | 4 | JTAG_TDO | JTAG, to programmer
J2 | 5 | JTAG_TDI | JTAG, to programmer
J2 | 6 | JTAG_TMS | JTAG, to programmer
J3 | 1 | PROGRAM_B | PROGRAM_B, momentary to GND forces reconfiguration
J3 | 2 | GND | PROGRAM_B, momentary to GND forces reconfiguration
J4 | 1 | reset_n | Reset, momentary to GND
J4 | 2 | GND | Reset, momentary to GND
J5 | 1 | LINE_L | Stereo line out, to panel jacks
J5 | 2 | GND | Stereo line out, to panel jacks
J5 | 3 | LINE_R | Stereo line out, to panel jacks
J6 | 1 | VREF25 | Pitch potentiometer, panel mounted
J6 | 2 | POT_PITCH_RAW | Pitch potentiometer, panel mounted
J6 | 3 | GND | Pitch potentiometer, panel mounted
J7 | 1 | VREF25 | Decay potentiometer, panel mounted
J7 | 2 | POT_DECAY_RAW | Decay potentiometer, panel mounted
J7 | 3 | GND | Decay potentiometer, panel mounted
J8 | 1 | VREF25 | Timbre potentiometer, panel mounted
J8 | 2 | POT_TIMBRE_RAW | Timbre potentiometer, panel mounted
J8 | 3 | GND | Timbre potentiometer, panel mounted
J9 | 1 | ENC_A_RAW | Rotary encoder with switch, panel mounted
J9 | 2 | GND | Rotary encoder with switch, panel mounted
J9 | 3 | ENC_B_RAW | Rotary encoder with switch, panel mounted
J9 | 4 | ENC_SW_RAW | Rotary encoder with switch, panel mounted
J9 | 5 | GND | Rotary encoder with switch, panel mounted
J10 | 1 | V3V3 | Mode selector switch, panel mounted
J10 | 2 | cv_select | Mode selector switch, panel mounted
J10 | 3 | GND | Mode selector switch, panel mounted
J11 | 1 | GND | Status LEDs x4, anodes -- series resistors are on-board
J11 | 2 | LED0_A | Status LEDs x4, anodes -- series resistors are on-board
J11 | 3 | LED1_A | Status LEDs x4, anodes -- series resistors are on-board
J11 | 4 | LED2_A | Status LEDs x4, anodes -- series resistors are on-board
J11 | 5 | LED3_A | Status LEDs x4, anodes -- series resistors are on-board
J12 | 1 | PITCH_IN | Pitch CV input jack, 0-5 V
J12 | 2 | GND | Pitch CV input jack, 0-5 V
J13 | 1 | MOD_IN | Mod CV input jack, 0-5 V
J13 | 2 | GND | Mod CV input jack, 0-5 V
J14 | 1 | GATE_IN | Gate input jack
J14 | 2 | GND | Gate input jack
J15 | 1 | MIDI4 | MIDI DIN socket, pins 4 and 5
J15 | 2 | MIDI5 | MIDI DIN socket, pins 4 and 5

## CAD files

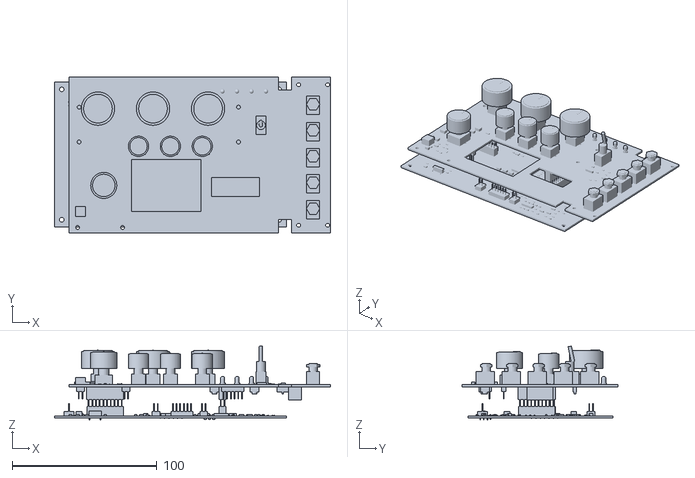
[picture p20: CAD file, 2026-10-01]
docs/media/3d/courant_stack.stl
190.5 x 108.0 x 51.0

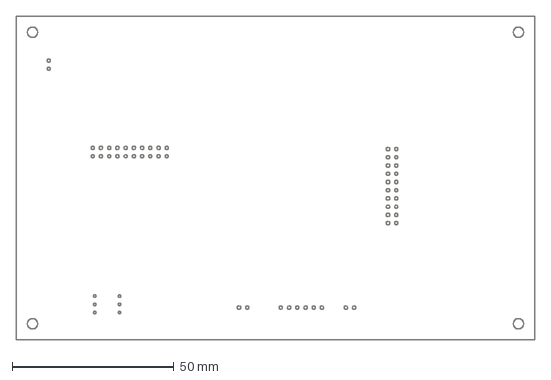
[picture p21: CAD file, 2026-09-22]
hardware/courant/deliverables/courant-outline.dxf
160.0 x 100.0 mm

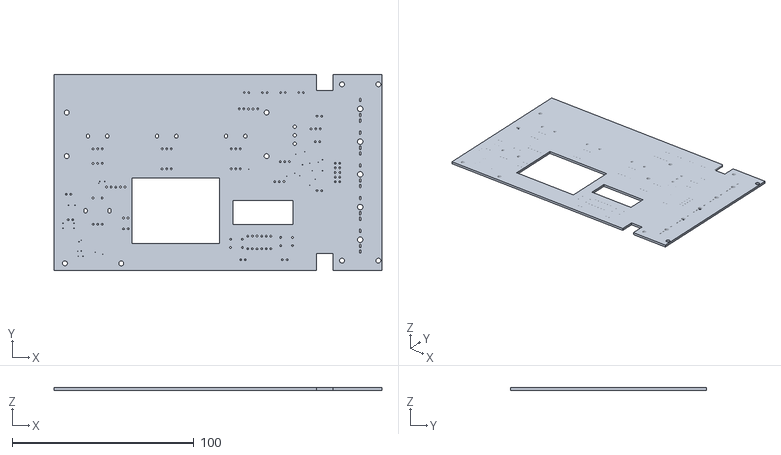
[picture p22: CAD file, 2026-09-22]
hardware/panel/cad/RADIAN_P1_fit_template.stl
180.5 x 108.0 x 1.51

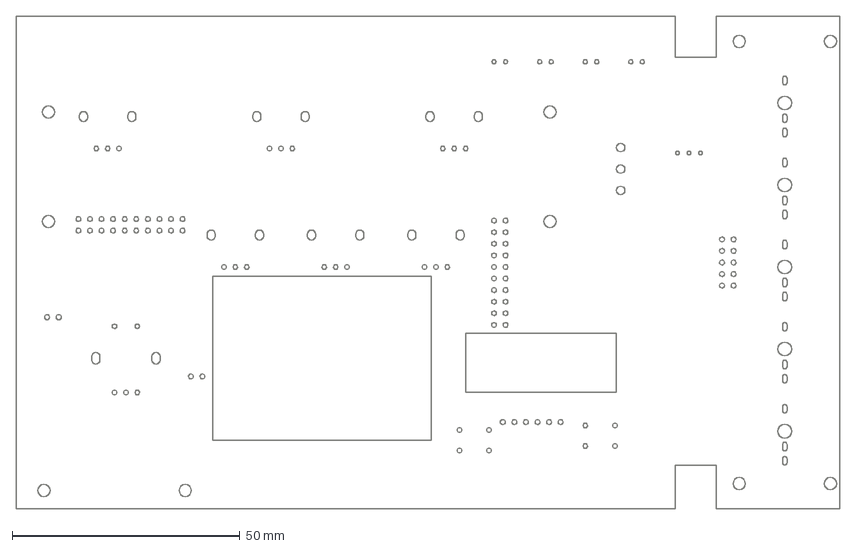
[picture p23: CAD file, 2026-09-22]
hardware/panel/cad/RADIAN_panel_P1_outline_reference.dxf
180.5 x 108.0 mm

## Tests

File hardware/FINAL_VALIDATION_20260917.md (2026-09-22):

# RADIAN final validation — 2026-09-17

Six-pot FX/direct-stack and enclosure CAD revision is complete at RTL + PCB-source + native-KiCad + reference-mechanical-CAD level.

- Mainboard: DRC **0**, unconnected **0**; SHA-256 `d7e2a898628225a0c21e27cb2387acf627036a41f7194c9551310b80ddac1b14`.
- Panel: ERC **0**, DRC **0**, unconnected **0**, parity **0**; SHA-256 `2640a117c312d2dd634bed3f620eb7622dab7716cf4d0946a9230fb8ff92d2a2`.
- Controls: **TENSION · DECAY · CHAOS · DRIVE · DELAY · REVERB**.
- Stack: Samtec **IPT1-110-06-L-D ↔ IPS1-110-01-L-D**, 40/40 pins net+XY matched, 19.99 mm fully mated, ~20.0 mm support target.
- RTL: **28/28 GHDL testbenches pass**.
- tscircuit: main typecheck/source check/full build pass; panel build pass. The exact 0201 tscircuit pad model matches **76/76** native pads.
- Main BOM: **191/191** placements resolved.
- Case CAD: CASE-P2-DIRECT-STACK; exact 2.00 mm faceplate/REVERB-insert thickness; six current macro openings + relocated MODE; mainboard shifted +0.46 mm for 19.99 mm fully-mated PCB gap; support planes updated; exported STEP validation and Xvfb preview render pass.
- Updated case assembly: hardware/panel/cad/RADIAN_P1_desktop_fit_study.step — SHA-256 ef70ab0a0f20970f53eebf58b0f1367d4517faeeebfa8a1866a3acb62fd81d42.
- Updated case shell: hardware/panel/cad/RADIAN_P1_case_shell_updated.step — SHA-256 4537715b2c1a7ae8ba7100f1178de85cac9fc652569fd058491b34546737527b.
- Main fab ZIP: `9159e62b65503af61e786e26a80dcd1be913c5a04e104c1cc5c3a0e2f93ee9a7`; embedded BOM current; ZIP integrity pass.
- Panel fab ZIP: `341016495117f15b1a56e051833066d1dab58a5879c722866f3b8b892b004080`; embedded BOM current; ZIP integrity pass.

Remaining gates require physical hardware only: first-article Samtec seating/retention and support/enclosure tolerance, real knob/fastener stack, power/thermal/fault tests, and target-FPGA implementation/bring-up.

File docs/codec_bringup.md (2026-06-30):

# Pmod I2S2 codec bring-up (Arty A7)

Getting real audio in and out of the engine on the target board (README §6).
The Pmod I2S2 carries two Cirrus codecs: a **CS5343** stereo ADC and a
**CS4344** stereo DAC. This note covers how they are "initialised", the clocks
the FPGA must generate, the Pmod wiring, and the bring-up checklist.

## There is no register configuration

Both the CS5343 and the CS4344 are **hardware-mode (stand-alone) codecs**: they
have *no* I2C or SPI control port and *no* register map. There is nothing to
write at power-up. Each codec selects its speed mode automatically from the
**MCLK/LRCK ratio** and begins converting as soon as it sees valid, stable
clocks at a supported ratio. So on this board, "codec initialisation" is
entirely a clocking problem:

> Provide a clean MCLK, a serial bit clock (SCLK/BCLK), and a word-select
> (LRCK) at a supported ratio, and the codec runs.

The FPGA is therefore the **I2S master** and generates all three clocks.
[`src/rtl/i2s_clkgen.vhd`](../src/rtl/i2s_clkgen.vhd) does this.

## Clocks and ratios

Targeting `f_s = 48 kHz` in single-speed mode:

| Clock | Frequency | Ratio | Source |
| --- | --- | --- | --- |
| MCLK | 12.288 MHz | 256 x f_s | MMCM from the 100 MHz oscillator |
| BCLK (SCLK) | 3.072 MHz | 64 x f_s (= MCLK / 4) | `i2s_clkgen` |
| LRCK | 48 kHz | 1 x f_s (= BCLK / 64) | `i2s_clkgen` |

`MCLK / LRCK = 256` is a single-speed-mode ratio valid for both the CS5343 and
the CS4344 (they also accept 384x / 512x). `BCLK = 64 x f_s` gives 32 bit-clocks
per channel, enough for the 24-bit word MSB-justified into a 32-bit slot that
[`i2s_transceiver`](../src/rtl/i2s_transceiver.vhd) drives. LRCK is a 50%-duty
square wave: low = left, high = right.

### Generating MCLK (clocking wizard / MMCM)

12.288 MHz is not an integer division of the 100 MHz board oscillator, so MCLK
comes from an MMCM (Vivado Clocking Wizard). One working solution:

```
CLKIN1   = 100.000 MHz
M (MULT) = 49.125         -> VCO = 614.0625 MHz (within the Artix-7 MMCM range)
O (DIV)  = 49.953125      -> 12.288 MHz   (CLKOUT0 = MCLK)
```

The exact M/O are part-specific; let the Clocking Wizard solve for 12.288 MHz
and check the reported output is within a few ppm. `i2s_clkgen` then divides
MCLK down to BCLK and LRCK with simple synchronous counters, so all three clocks
are phase-locked with no drift. (For 44.1 kHz, target MCLK = 11.2896 MHz the
same way; the divider ratios are unchanged.)

On real silicon, forward MCLK and BCLK to the codec pins through an **ODDR**
(clock-capable output buffer), not through logic, to keep the edges clean;
`i2s_clkgen` assigns them directly, which is equivalent in simulation and the
point at which to drop in the ODDR for hardware.

## Pmod wiring (Pmod I2S2 on header JA)

The Pmod I2S2 has two 6-pin headers: **J1 = ADC (line in)**, **J2 = DAC
(line out)**. Both share the master clock and bit/word clocks; only the data
pin differs (ADC drives SDOUT, DAC receives SDIN).

| Signal | Direction (FPGA) | Pmod I2S2 pin | Arty Pmod JA | Arty pkg pin |
| --- | --- | --- | --- | --- |
| MCLK | out | MCLK | JA1 | G13 |
| LRCK | out | LRCK | JA2 | B11 |
| SCLK (BCLK) | out | SCLK | JA3 | A11 |
| SDIN (to DAC) | out | SDIN (J2) | JA4 | D12 |
| SDOUT (from ADC) | in | SDOUT (J1) | JA7 | D13 |
| GND / VCC | - | GND / VCC | JA5/6, JA11/12 | - |

Adjust the JA pin LOCs to your wiring; the clock ratios are independent of the
pin assignment. These are the pins constrained in
[`syn/vivado/arty_a7.xdc`](../syn/vivado/arty_a7.xdc).

Note that `top_resonator` is currently an I2S *slave* (it takes `bclk`/`lrclk`
as inputs). For a master-mode board build, drive both the codec pins **and**
`top_resonator`'s `bclk`/`lrclk` inputs from `i2s_clkgen`, so the transceiver
frames against the same clocks the codec sees.

## Verification

### Simulation (clock ratios)
[`src/tb/i2s_clkgen_tb.vhd`](../src/tb/i2s_clkgen_tb.vhd) drives `i2s_clkgen`
from a 12.288 MHz MCLK and checks, over several frames, that MCLK:BCLK:LRCK is
exactly 256:64:1, that the ratios never deviate (stable, not momentarily right),
that LRCK is 50%-duty, and that MCLK is forwarded unchanged. This is the
bench-equivalent of the scope check below.

### On hardware (scope / logic analyzer)
After FPGA configuration, confirm at the Pmod header:

1. **MCLK** present at 12.288 MHz, clean (no missing edges).
2. **BCLK** at 3.072 MHz, **LRCK** at 48 kHz, both phase-locked to MCLK
   (BCLK = MCLK/4, LRCK = BCLK/64).
3. **LRCK** is a 50%-duty square wave aligned to BCLK.
4. The codec produces output: with SDIN fed a known tone (or SDOUT looped to
   SDIN), the recovered samples on SDOUT track the input. Because the codecs
   self-start on valid clocks, stable clocks at the ratios above are the
   acknowledgement that the codec has initialised; there is no config-ack
   register to read back.

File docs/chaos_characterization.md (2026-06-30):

# Aliasing and chaos characterisation

Characterises the non-linear regime (README §2): spectral content / THD, the
aliasing floor vs oversampling, and the period-doubling route into chaos, all
under the same Q1.23 saturating arithmetic as the RTL. Reproduce with:

```sh
octave-cli --eval "chaos_study"          # or run chaos_study in MATLAB
```

Script: [`model/chaos_study.m`](../model/chaos_study.m). Base parameters:
`gamma0^2 = 0.09`, `gamma2_max = 0.451` (the CFL-safe clamp from issue #3).

---

## 1. THD vs alpha and drive amplitude

THD of a period-1 driven node (the squaring non-linearity makes harmonics):

| drive amp \ alpha | 0.1 | 0.2 | 0.3 | 0.4 | 0.5 |
| --- | --- | --- | --- | --- | --- |
| 0.2 | 1.9% | 2.3% | 2.6% | 2.8% | 3.0% |
| 0.4 | 2.8% | 3.5% | 4.0% | 4.3% | 4.7% |
| 0.6 | 3.9% | 4.5% | 5.2% | 5.7% | 18.2% |

THD grows smoothly with both `alpha` and drive amplitude, then jumps once the
combination enters the bifurcation band (broadband content, last cell). The
mallet level is as important as `alpha` for brightness.

---

## 2. Aliasing floor vs oversampling

Spectral SNR of the decimated output against a 16x ground truth (9x9 mesh,
non-linear, hard centred strike):

| OS | SNR vs 16x |
| --- | --- |
| 1x | -8.7 dB |
| 2x | -5.0 dB |
| 4x | +0.3 dB |
| 8x | +10.0 dB |

Each doubling of the oversampling factor cuts the aliasing floor by several dB.
See also `docs/oversampling.md` (issue #15) for the decimation path itself.

---

## 3. Period-doubling / route to chaos

Driven-node bifurcation via a stroboscopic Poincare section (sample once per
drive period, `T = 10`, drive `0.7`), sweeping `alpha`:

- `alpha < 0.55`: **locked period-1** (the forced response tracks the drive).
- `alpha in [0.55, 0.90]`: **route to chaos**, periods of 2, 3, 4, 6 and chaotic
  bands (the hardening `alpha*u^2` stiffness destabilises the locked orbit).
- `alpha > 0.90`: **re-locks to period-1** as the `gamma2_max` clamp saturates
  the local stiffness and removes the amplitude dependence.

This is the Duffing-style hardening-oscillator cascade: rich and genuinely
chaotic, but the clamp plus saturating state keep it bounded (next section).

---

## 4. Bounded output (no divergence)

Across the entire `alpha` x amplitude sweep the output stays inside the Q1.23
range and never pins to a rail: **bounded = true everywhere**. The two
structural guards do their job (README §2):

- `gamma2_local = clamp(..., 0, gamma2_max)` with `gamma2_max = 0.451 < 1/2`
  keeps the scheme inside the stable region (issue #3);
- saturating Q1.23 state arithmetic turns any blow-up energy into soft
  saturation rather than wrap-around or Nyquist buzz.

---

## Operating envelope

| Knob | Recommendation |
| --- | --- |
| `alpha` | `< 0.2` near-linear / clean; `0.2..0.5` musical brightening; `~0.55..0.9` bounded chaos; clamp re-locks above |
| drive amplitude | primary brightness/chaos control alongside `alpha`; THD rises with level |
| oversampling | 4x sensible default; raise to 8x for hard or chaotic patches |
| `gamma2_max` | `0.451` (issue #3); do not raise to/above `0.5` or the clamp stops protecting the CFL limit |

Plots (`model/outputs/chaos_characterization.png`: aliasing floor, THD map,
bifurcation diagram) are produced by `chaos_study` when a graphics toolkit is
available.

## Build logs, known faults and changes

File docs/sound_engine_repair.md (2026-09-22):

# RADIAN sound-engine repair — 2026-09-16

The playable RTL was repaired after the first listening demos exposed uncalibrated pitch and excessive high-frequency/non-linear output.

## Implemented
- Discrete-mesh pitch calibration for NX/NY, OS, sample rate, and fixed/free boundary mode.
- MIDI velocity controls strike only by default; CHAOS is independent.
- Musical strike gain reduced from 0.9 to 0.002; output level is restored after the resonator instead of clipping cells.
- TENSION is a normalized multiplier (0.25 unity, approximately ±1 octave panel range).
- Rate-aware DECAY mapping and a one-LSB decay-pot change threshold.
- Preset pickup coordinates and boundary mode now reach the active voice path.
- Balanced excitation for free-boundary musical voices to avoid the DC translation mode.
- Voice retrigger/steal resets the selected mesh with a 32-frame output crossfade.
- 20 Hz DC blocker and bounded output gain before I2S CDC.
- Spatial and TDM meshes support the same runtime pickup/boundary controls.

## Acceptance
- Published repo: **28/28** NVC RTL testbenches pass.
- Fixed/free spectral probes at MIDI 45/57/69/81: maximum measured pitch error **0.89 cents**.
- Instrumented musical probes, including max CHAOS, complete without internal Q1.23 cell-clipping assertions.
- GHDL synthesis of the published 4-voice 8x8 OS4 TIME_MUX `synth_top` succeeds; current Verilator build has no warnings.
- Native NVC and GHDL→Verilator captures match sample-for-sample for both fixed and free validation cases (12,000 stereo frames each).
- Four-second full MIDI→polyphony→CDC→I2S phrase: 3 active voices max, 99.919% spectral power below 2 kHz, 0.000012% above 5 kHz.

Raw metrics and commands are preserved under `/home/ik/ChatGPT/RADIAN_Sound_Repair_20260916T042905Z`. A pre-apply rollback archive is `/home/ik/ChatGPT/RADIAN_Sound_Repair_20260916T042905Z/repo_before_sound_repair.tar.gz`.

This validates simulation/synthesis behavior, not physical FPGA timing closure or analog hardware sound.

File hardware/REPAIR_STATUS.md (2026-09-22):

# RADIAN hardware status — 2026-09-18

The active hardware is the six-control, direct-stack revision. The native KiCad boards are authoritative engineering prototypes; the old panel/mainboard cable-harness topology is retired.

| Native check (KiCad 10.0.6) | Mainboard | Panel |
|---|---:|---:|
| DRC violations | 0 | 0 |
| Unconnected items | 0 | 0 |
| Schematic ERC violations | N/A: no native mainboard schematic | 0 |
| Schematic/PCB parity findings | N/A | 0 |

## Current revision
- Panel controls: TENSION, DECAY, CHAOS, DRIVE, DELAY, REVERB; push encoder; MODE; four LEDs.
- MCP3208 uses all eight channels. DRIVE/DELAY/REVERB use the three formerly grounded ADC channels through 1 kOhm / 10 nF input filters.
- FX macros are handled by read-modify-write in `panel_ctrl.vhd`, preserving the other packed FX-register fields.
- Mainboard/panel mate directly with two 2×10 2.54 mm connectors. There is no per-function panel-to-mainboard cable bundle.
- Legacy panel edge headers **J5–J15 have been removed from the mainboard**, and the now-unused copper stubs were pruned. J1–J4 remain for service/debug access.
- Main J17/J18: Samtec IPT1-110-06-L-D. Panel J100/J101: Samtec IPS1-110-01-L-D.
- Shared stack contract: `stack/panel-stack.json`, 19.99 mm fully mated, 20.45 mm maximum, nominal 20.0 mm support spacing.
- Final native pin proof: 40/40 mating pins match both net name and assembled XY; maximum computed XY delta is floating-point noise (<2e-14 mm).
- Generic panel utility headers are retired: J200 = Wurth 61201021621, J201/J306 = Molex 22-27-2021, J202 = Molex 22-27-2061, and JP1 = Wurth 450301014042 SPDT. Their routed endpoints were preserved, so this is a selected-component/footprint change rather than a wholesale reroute.
- Final CAD visualization no longer uses generic white component envelopes: both boards are exported from native KiCad component placements into `RADIAN_actual_parts_full_assembly.step`; actual/open PTV09A, PJ398SM, Omron B3F and LED geometry plus package-accurate production models are rendered. Remaining MPN-specific drawing-derived solids are explicitly documented.
- Mainboard production-part reconciliation is complete: all 180 referenced placements now carry Manufacturer + MPN and a resolved 3D model. U1/U5/Y1/Y2 and the service connectors now use semantic package identities matching the BOM; J1/J3/J4 are Molex 22-23-2021, J2 is 22-23-2061. No copper/pad/net/placement routing changed; only the selected Molex service connectors' finished-hole drills changed from 1.00 to 1.02 mm and their courtyards/models were corrected.
- Final CAD fidelity pass is complete. The old generic white PCB-component envelopes are no longer used by the canonical product assembly. Both boards are assembled from KiCad-placed component STEP groups. Panel pots/jacks/service switches/LEDs and small packages use real/open or maintained package geometry; ENC1/SW1 and vendor-gated connector models are explicitly drawing-derived mechanical references. Actual-part collision validation passes with zero unintended board-to-board or rear-guard/dock clashes.
- The remaining white-render artifact was traced to STEP **compound colors being discarded**. The canonical exporter now emits each physical solid as a colored child; round-trip audit reports **715/715 colored children, 0 missing colors, 0 default-white children**. Only actual natural-nylon Molex housings remain light cream.
- U8/H11L1M alignment is now mathematically locked: six model lead centers exactly match six native pads after KiCad Y inversion; placed U8 STEP center is exactly (48.000,-139.000) mm versus the native (48.000,139.000) PCB center.

## Current outputs
Mainboard: `courant/deliverables/courant.kicad_pcb` and derived `courant/dist/` outputs. Panel: `panel/design/radian_panel.kicad_pcb` and derived `panel/fab/` / `panel/radian_panel-fab.zip`. `hardware/refresh_outputs.py` regenerates review/fabrication-format outputs only after native checks pass.

The regenerated main manufacturer BOM now contains **180 placements** after removal of J5–J15; J17/J18 are the exact Samtec IPT1 part. The panel BOM contains the exact IPS1 mate at J100/J101 plus the selected Wurth/Molex utility connectors and JP1 switch listed above.

## Validation still requiring physical hardware
KiCad/RTL checks do not prove connector seating under real tolerances, enclosure/support fit, insertion/retention force, power integrity, current/thermal/fault behaviour or actual FPGA timing on silicon. Build a first article with a ~20.0 mm board support stack, inspect full connector seating, and bench-test power/audio/control behaviour before ordering production quantity.

No Git reset/revert/commit was used for this revision; pre-existing worktree changes were preserved. Backups from the direct-stack and connector-finalization work are under `hardware/_backups/`.

## Current case
The case CAD is updated for the active six-pot/direct-stack hardware. The old three-macro front geometry is retired; the Samtec stack is modeled at 19.99 mm PCB spacing with ~20.0 mm support geometry. `panel/cad/RADIAN_P1_desktop_fit_study.step` is the current product assembly and `panel/reports/CASE_UPDATE.md` summarizes the mechanical changes. Physical first-article fit/retention remains unverified.

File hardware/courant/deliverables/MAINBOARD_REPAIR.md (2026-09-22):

> **Release synchronization: 2026-09-16.** Current native boards, fabrication-format exports and CAD are indexed in `../../RELEASE_SYNC_STATUS.md`. Earlier statements below about pre-repair exports are historical; electrical/physical validation limitations still apply.

# RADIAN mainboard — native repair, 2026-09-16

## Result
The corrected mainboard passes Backplane KiCad 10.0.6 native DRC with **0 errors, 0 warnings and 0 unconnected items** under the existing project rules. All error/warning/exclusion severities were requested. No check settings were weakened and no new exclusions were added.

This is a PCB geometry/connectivity and library/artwork correction, **not a fabrication release or an electrical design sign-off**.

## Executed changes
- Consolidated 12 groups of overlapping same-net through-vias, removing 13 redundant vias while retaining existing via centres.
- Removed 34 track segments and one additional unused via through native-checked cleanup trials.
- Trimmed/reanchored three branches to their actual intermediate connections: GND to its existing via, V1V8 to C113 pad 1, and adc_cs_n to its existing layer-transition via. Blind whole-segment removal failed checks and was reverted before the accepted localized repairs.
- Restored a local RadianMain.pretty library: 43 variants representing the existing embedded footprint geometry for 202 instances. This is consistency, not manufacturer footprint verification.
- Replaced 45 undersized generic pin labels with 1 mm pin numbers; moved 95 conflicting outline graphics to fabrication layers; repositioned conflicting text. Bottom C100–C137 references now sit horizontally beside their own components instead of being scattered away from them.

Final native board: **2,158 track segments and 299 vias** (formerly 2,192 and 313).

## Independent preservation checks
- All 746 pad definitions retain their original positions, sizes, holes, orientation, layers, attributes and pin/net assignments.
- All 202 footprint instance placements are unchanged.
- The 96 connected pad groups match the original board exactly using native connectivity data.
- Board outline, thickness and enabled layers are unchanged.
- The project .kicad_pro file is byte-identical, including rule limits and severity settings.
- Minimum nominal drill-edge spacing: **0.258511 mm**, against the existing 0.25 mm rule.
- Exported Excellon files: 350 plated + 4 non-plated holes; no coincident centres; minimum exported drill-edge spacing **0.258587 mm** after coordinate rounding.

Original PCB SHA-256: `0683ead4a73049f5a2276b2cd3bf6389199609574a67aab8e27f48040a18deec`.

## Tool provenance
Checks used Backplane_KiCad 10.0.6, source commit `1c193606eddedbf98f8c9af5100b5e8f79da603d`. Editing used the installed KiCad 10.0.6 Python API and narrowly scoped S-expression edits. The Backplane desktop GUI was not automated.

## Files and evidence
- `working/courant.kicad_pcb` and its matching project and `fp-lib-table` form the corrected standalone handoff.
- `reports/06_compact_refs/` contains the final working-copy native result.
- `reports/07_published/` contains the post-copy native check when applied to the repository.
- `reports/invariants.json`, `exported_drill_check.json`, `via_consolidation.json`, `safe_dangling_cleanup.json`, `branch_trimming.json`, `footprint_library_mapping.json` and the artwork logs document the tests and changes.
- `review_exports/` contains refreshed review-only Gerbers, Excellon drills/maps and native SVG/PNG previews. These are NOT an approved manufacturing package.
- `baseline/` preserves the original handoff before editing. Trial reports with nonzero counts are historical experiments, not final results.
- `scripts/` records the repair process; do not blindly rerun destructive generation scripts on a later board revision.

## Scope and remaining release gates
The existing project still ignores missing courtyards, track centering on vias, tuning-profile geometry, footprint filters and footprint-type mismatch checks. Zero findings refers to this unchanged profile.

No native .kicad_sch was supplied for the mainboard, so **mainboard ERC and schematic/PCB parity were not run**. Empty parity arrays in DRC are not a passed schematic comparison. Electrical correctness, FPGA constraints/timing/boot, power integrity, regulator layout adequacy, actual footprint/MPN correctness, thermal/fault behaviour and physical assembly remain separate validations.

A 0.2585 mm nominal drill spacing is not a fabrication-tolerance guarantee; confirm the actual fabricator's requirements. No component positions, values or nets were redesigned to make this result pass.

## Avoid stale outputs
The TypeScript generators, routing intermediates under `hardware/courant/dist`, earlier fab ZIPs, and the older assembly STEP / SVG exports have NOT been regenerated or certified by this repair. The older STEP still represents the original drill/copper artwork. Re-export from the corrected native board for new geometry-sensitive outputs. Keep the recorded repaired board as the baseline until generator output has been reconciled and revalidated.

No commit or push was made. Unrelated dirty files and the separate panel PCB were not changed.

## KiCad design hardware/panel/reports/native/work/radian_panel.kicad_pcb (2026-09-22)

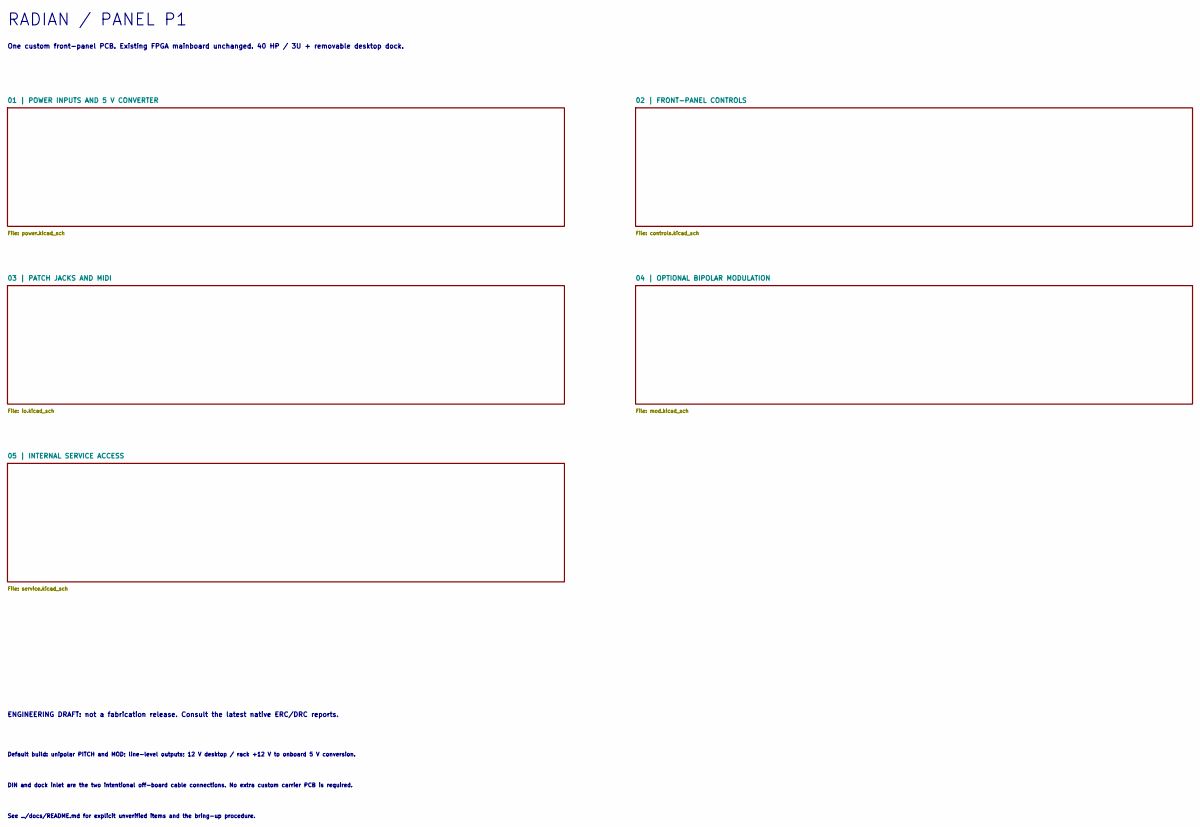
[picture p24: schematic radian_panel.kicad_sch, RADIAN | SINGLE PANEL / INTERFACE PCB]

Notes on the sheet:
RADIAN / PANEL P1
One custom front-panel PCB. Existing FPGA mainboard unchanged. 40 HP / 3U + removable desktop dock.
ENGINEERING DRAFT: not a fabrication release. Consult the latest native ERC/DRC reports.
Default build: unipolar PITCH and MOD; line-level outputs; 12 V desktop / rack +12 V to onboard 5 V conversion.
DIN and dock inlet are the two intentional off-board cable connections. No extra custom carrier PCB is required.
See ../docs/README.md for explicit unverified items and the bring-up procedure.

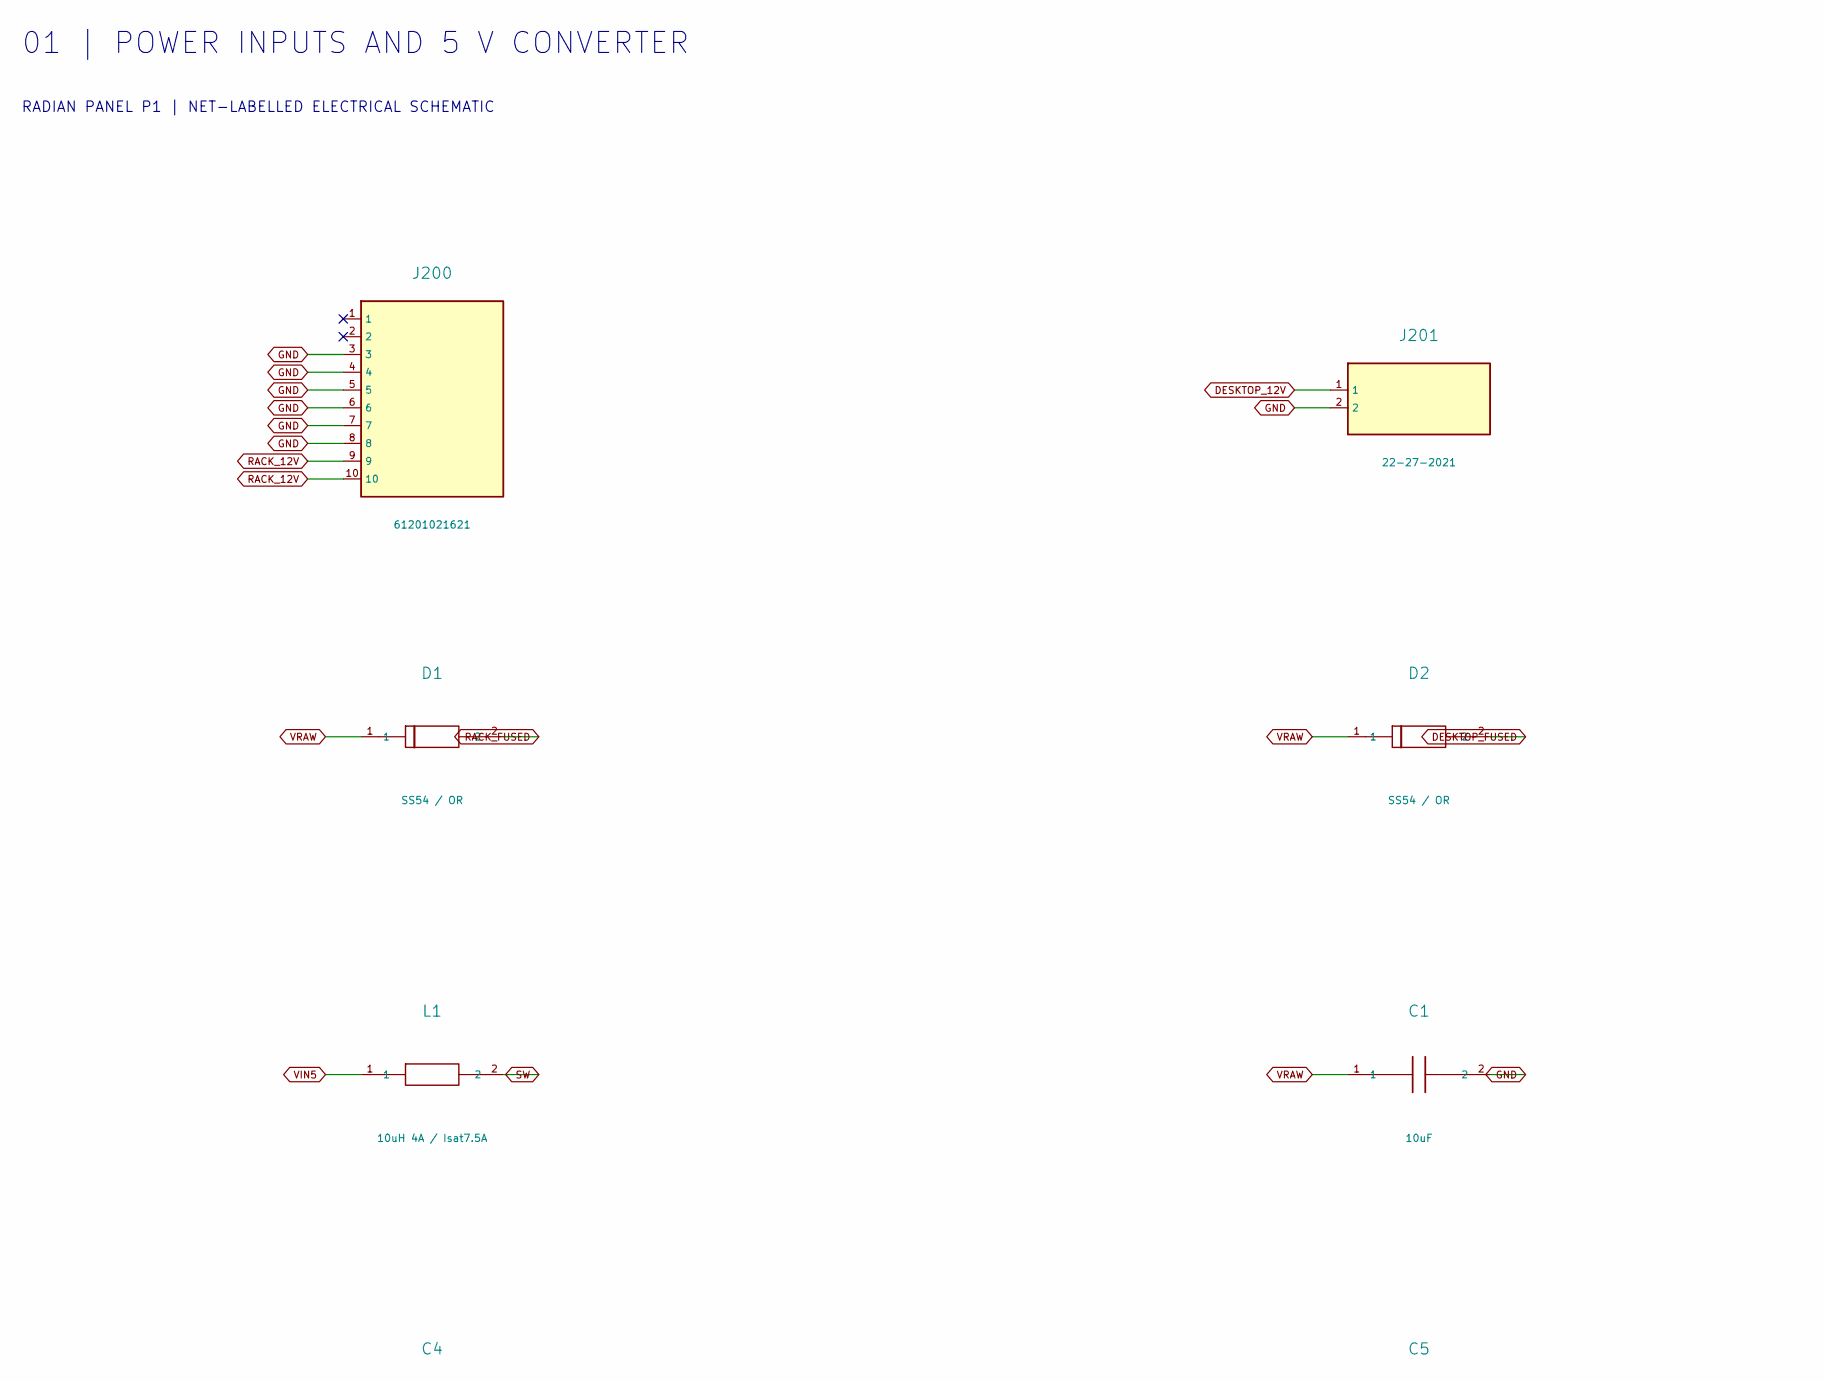
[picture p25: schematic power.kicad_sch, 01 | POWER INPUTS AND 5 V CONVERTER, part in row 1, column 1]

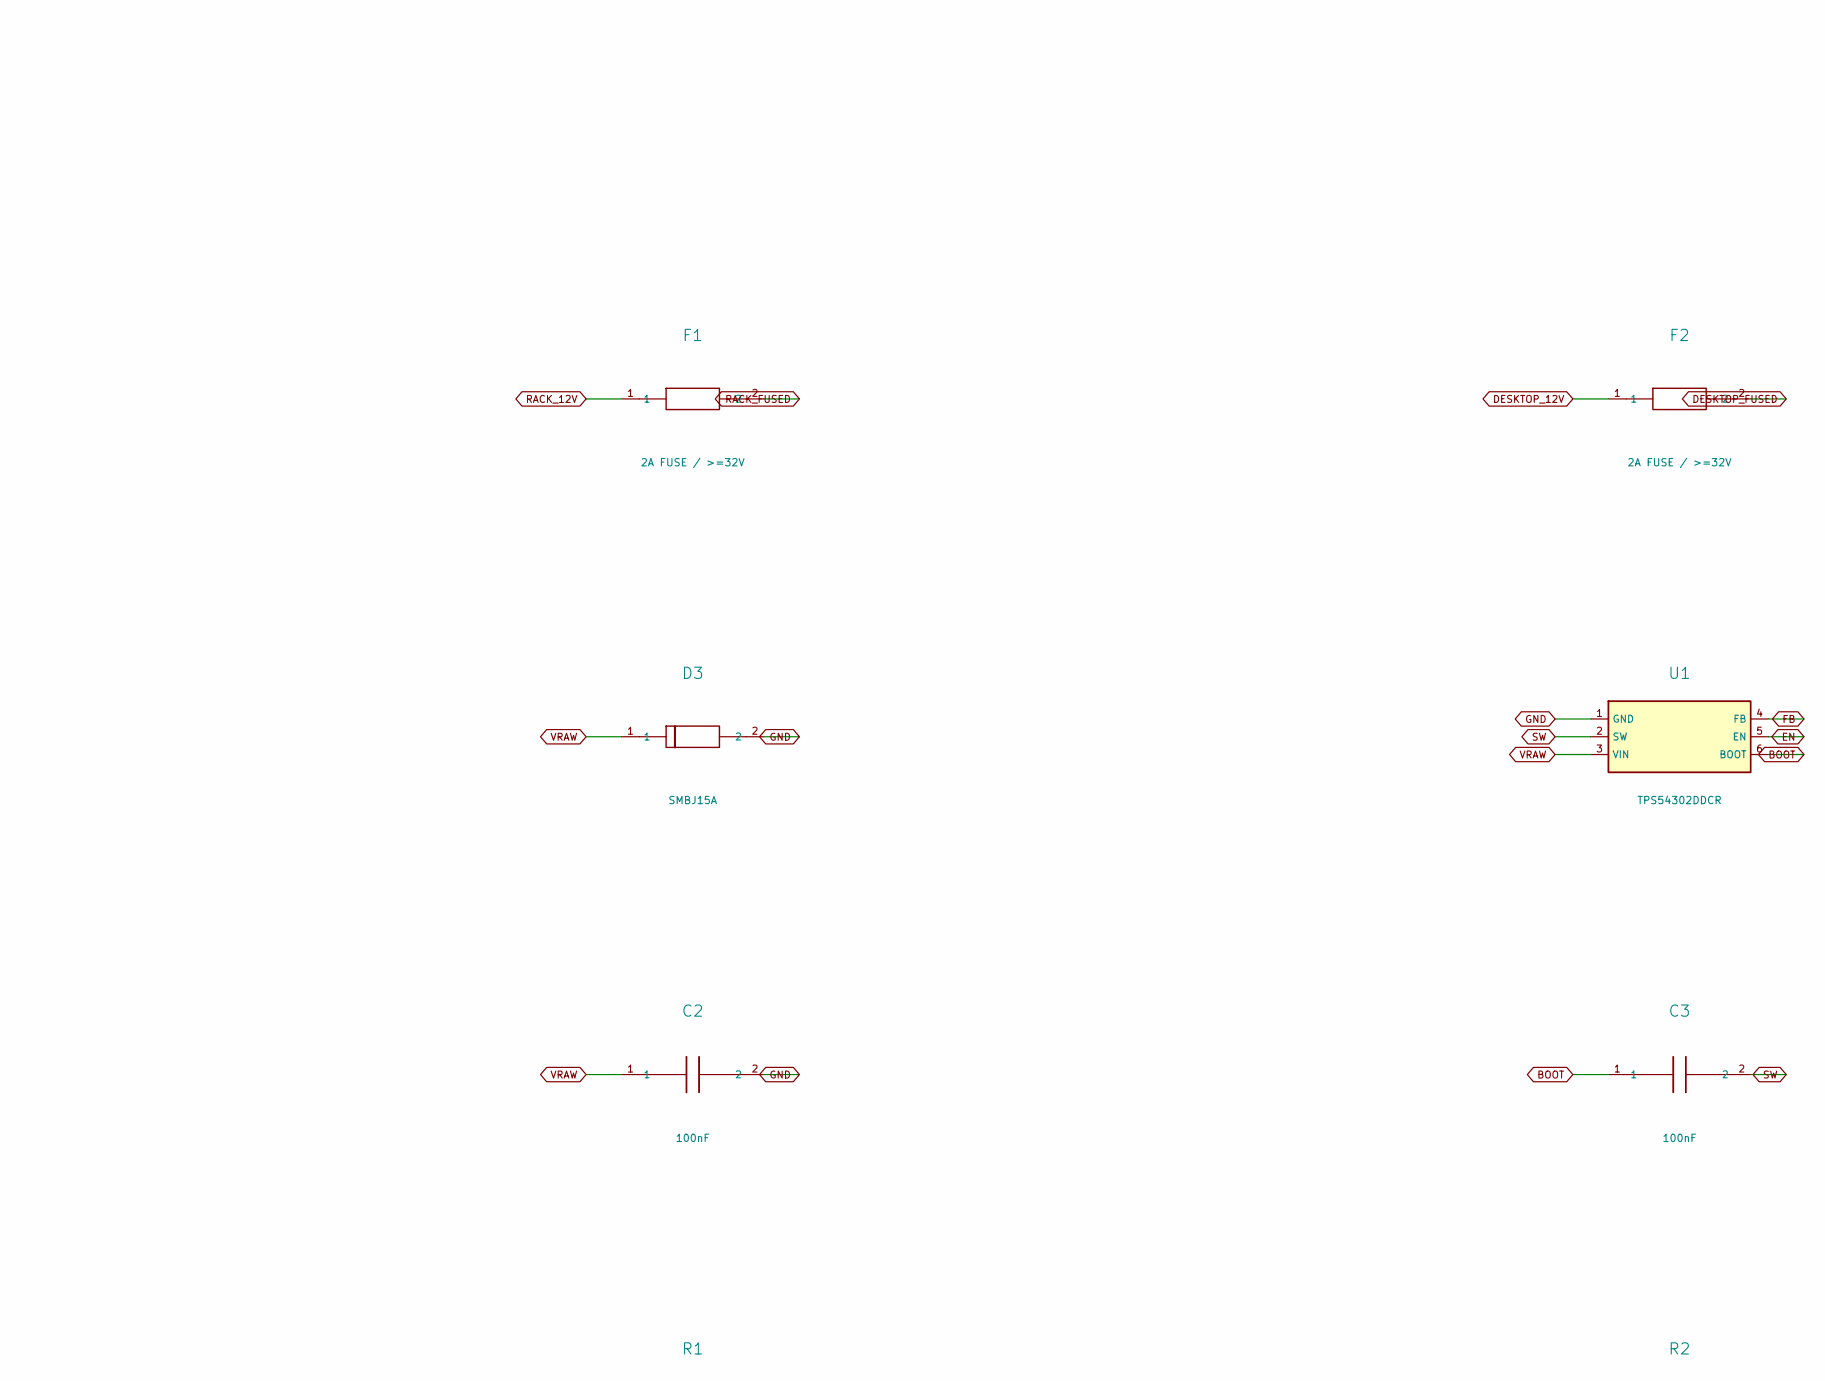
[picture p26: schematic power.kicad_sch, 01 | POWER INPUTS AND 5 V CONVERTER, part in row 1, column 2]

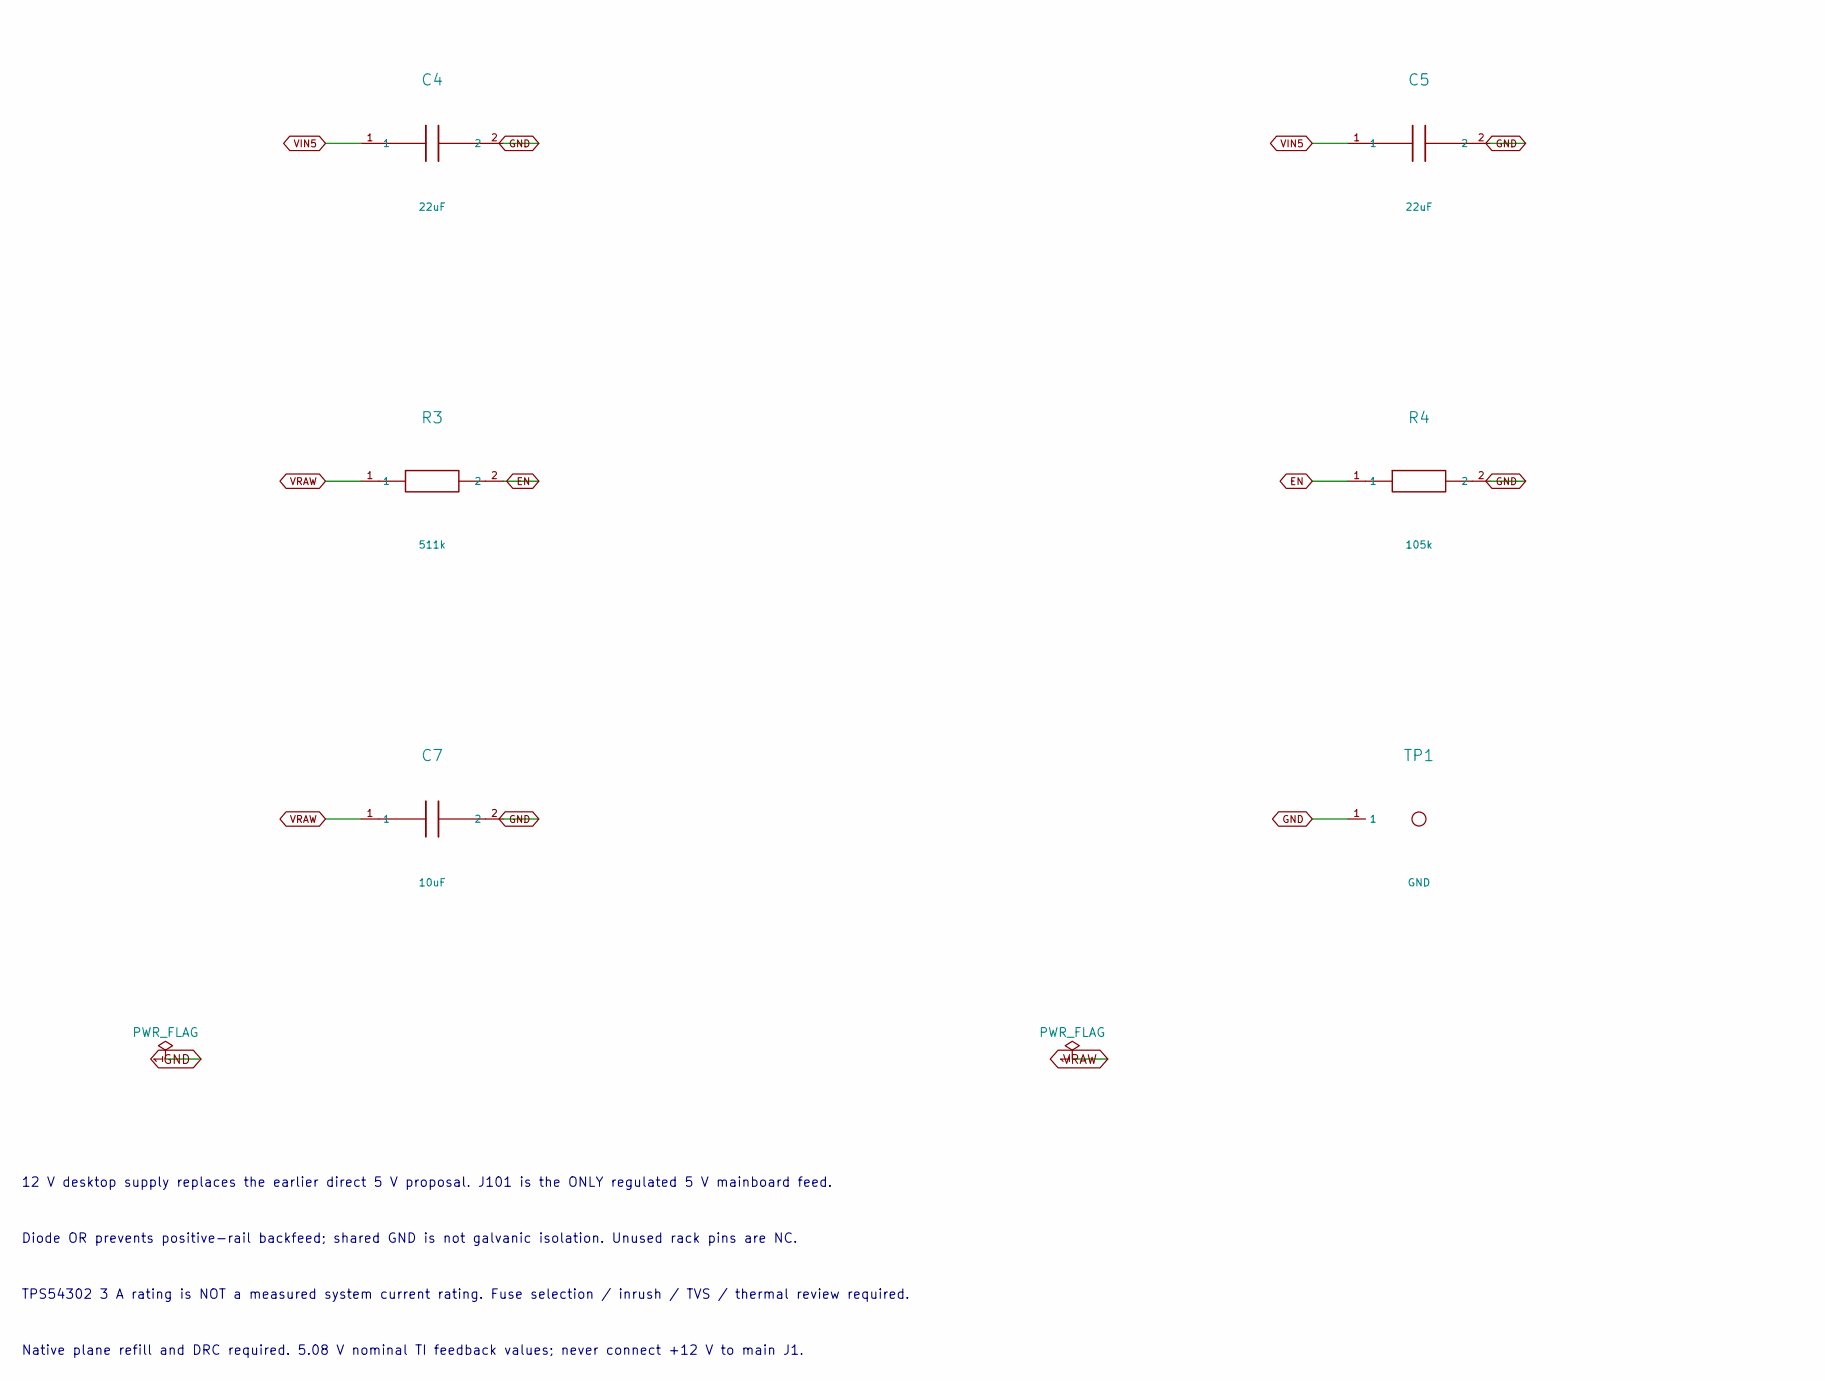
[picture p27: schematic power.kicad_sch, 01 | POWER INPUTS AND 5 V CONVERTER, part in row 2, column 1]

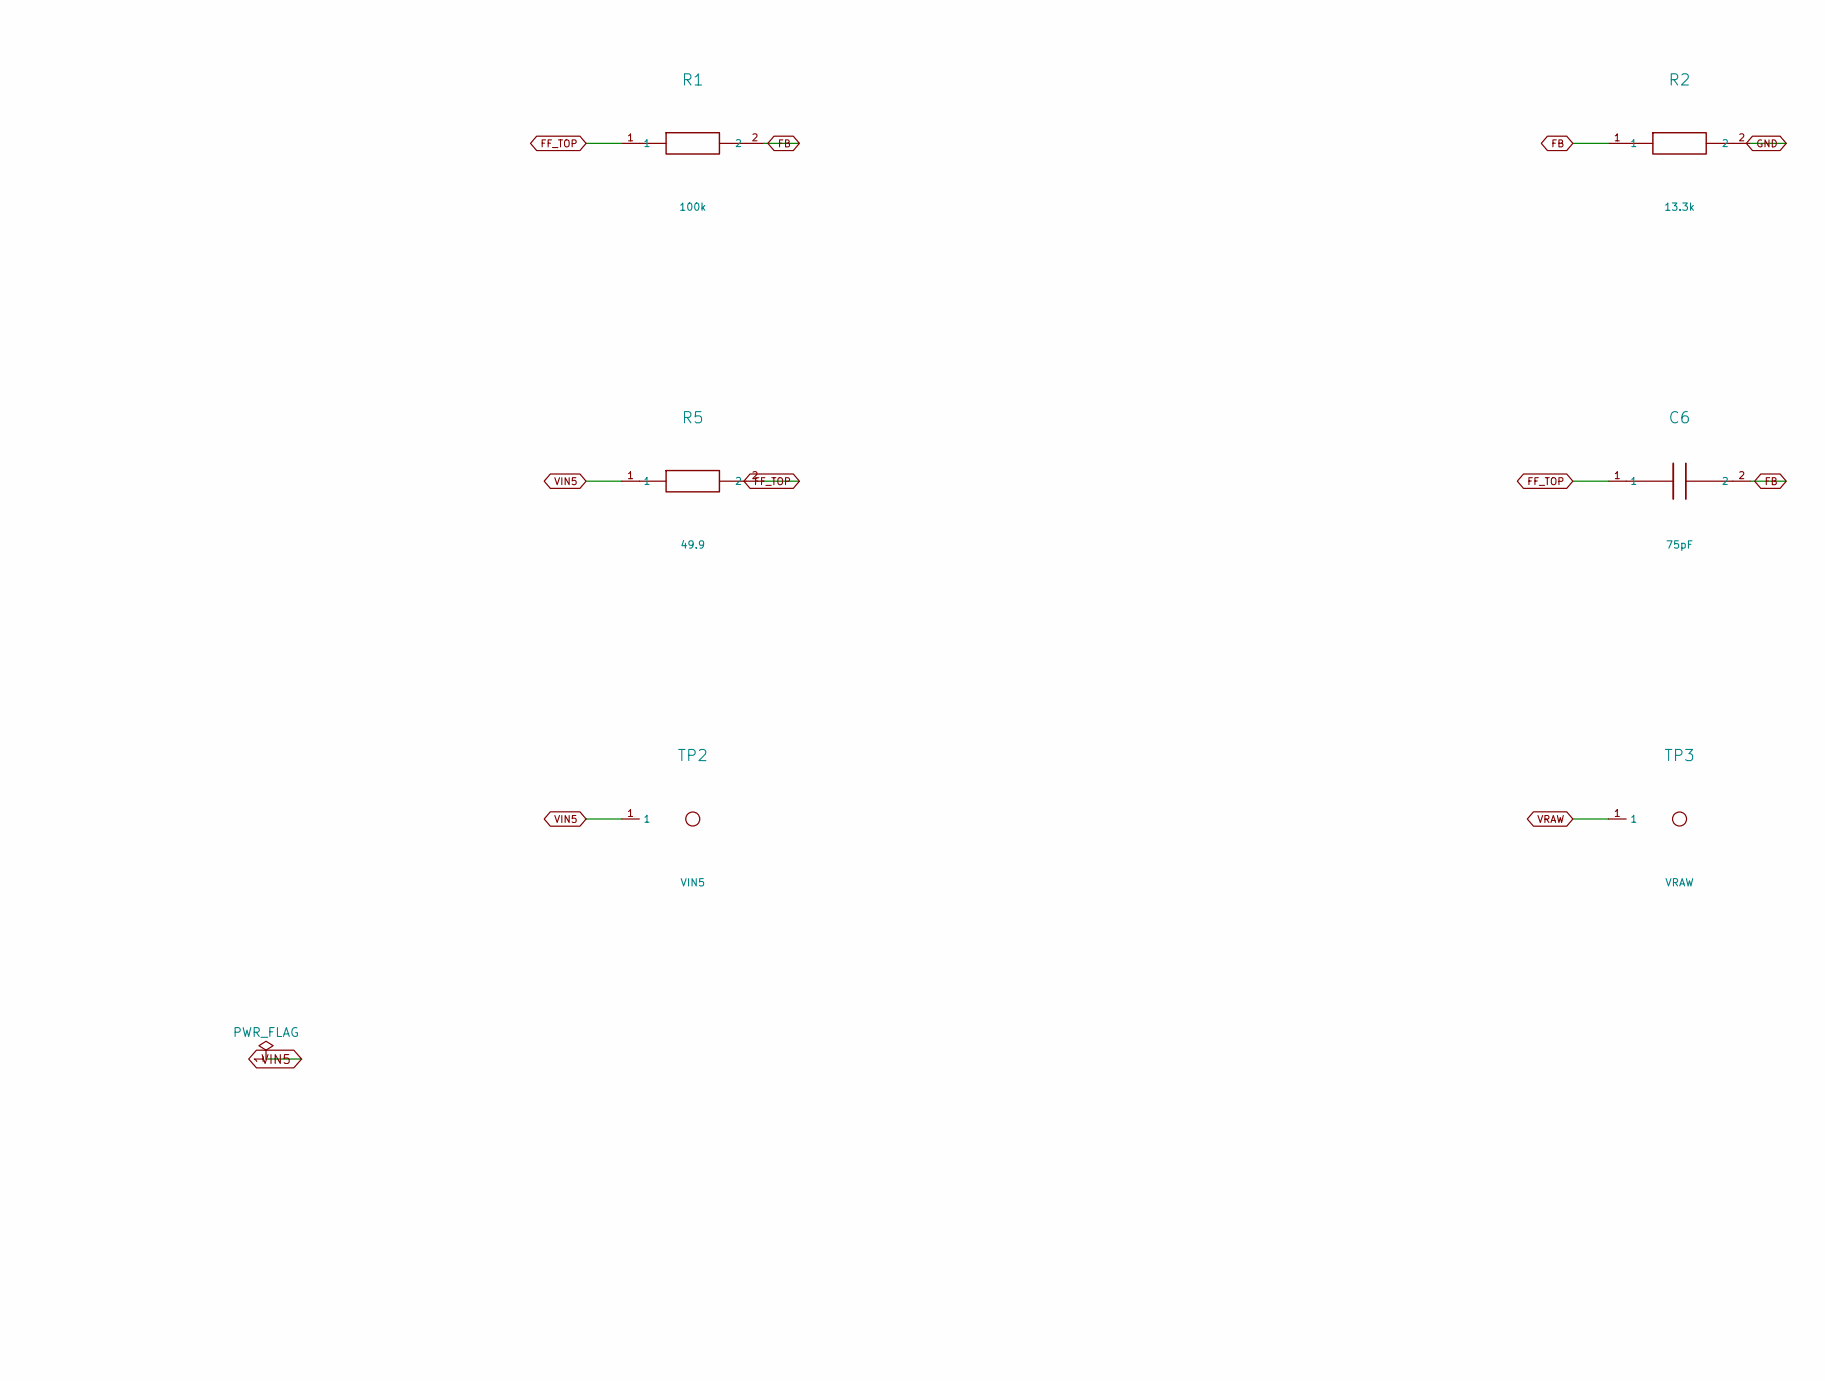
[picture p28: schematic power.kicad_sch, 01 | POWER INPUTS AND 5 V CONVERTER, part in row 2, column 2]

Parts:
C1, C7: 10uF; C_1210; MPN SELECT 10uF 50V X7R 1210
C2: 100nF; C_0603; MPN SELECT 100nF 50V X7R 0603
C3: 100nF; C_0603; MPN SELECT 100nF 16V X7R 0603
C4, C5: 22uF; C_1210; MPN SELECT 22uF 25V X7R 1210
C6: 75pF; C_0603; MPN SELECT 75pF 50V C0G 0603
D1, D2: SS54 / OR; D_SMB; MPN SS54-E3/57T
D3: SMBJ15A; D_SMB; MPN SMBJ15A-E3/52
F1, F2: 2A FUSE / >=32V; Fuse_1206; MPN SELECT 2 A >=32 V 1206 fuse
J200: 61201021621; Wurth_61201021621_Exact_B; MPN 61201021621
J201: 22-27-2021; Molex_22-27-2021_J201_B; MPN 22-27-2021
L1: 10uH 4A / Isat7.5A; Bourns_SRP7050TA; MPN SRP7050TA-100M
R1: 100k; R_0603; MPN SELECT 100k 1% 0603
R2: 13.3k; R_0603; MPN SELECT 13.3k 1% 0603
R3: 511k; R_0603; MPN SELECT 511k 1% 0603
R4: 105k; R_0603; MPN SELECT 105k 1% 0603
R5: 49.9; R_0603; MPN SELECT 49.9 1% 0603
TP1: GND; TestPoint_D2; MPN PCB test pad
TP2: VIN5; TestPoint_D2; MPN PCB test pad
TP3: VRAW; TestPoint_D2; MPN PCB test pad
U1: TPS54302DDCR; TI_DDC0006A_SOT23_6; MPN TPS54302DDCR

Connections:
BOOT: C3.1, U1.6 (BOOT)
DESKTOP_12V: F2.1, J201.1
DESKTOP_FUSED: D2.2, F2.2
EN: R3.2, R4.1, U1.5 (EN)
FB: C6.2, R1.2, R2.1, U1.4 (FB)
FF_TOP: C6.1, R1.1, R5.2
GND: C1.2, C2.2, C4.2, C5.2, C7.2, D3.2, J200.3, J200.4, J200.5, J200.6, J200.7, J200.8, J201.2, R2.2, R4.2, TP1.1, U1.1 (GND); also elsewhere on the board
RACK_12V: F1.1, J200.9, J200.10
RACK_FUSED: D1.2, F1.2
SW: C3.2, L1.2, U1.2 (SW)
VIN5: C4.1, C5.1, L1.1, R5.1, TP2.1; also elsewhere on the board
VRAW: C1.1, C2.1, C7.1, D1.1, D2.1, D3.1, R3.1, TP3.1, U1.3 (VIN)

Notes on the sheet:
01 | POWER INPUTS AND 5 V CONVERTER
RADIAN PANEL P1 | NET-LABELLED ELECTRICAL SCHEMATIC
12 V desktop supply replaces the earlier direct 5 V proposal. J101 is the ONLY regulated 5 V mainboard feed.
Diode OR prevents positive-rail backfeed; shared GND is not galvanic isolation. Unused rack pins are NC.
TPS54302 3 A rating is NOT a measured system current rating. Fuse selection / inrush / TVS / thermal review required.
Native plane refill and DRC required. 5.08 V nominal TI feedback values; never connect +12 V to main J1.

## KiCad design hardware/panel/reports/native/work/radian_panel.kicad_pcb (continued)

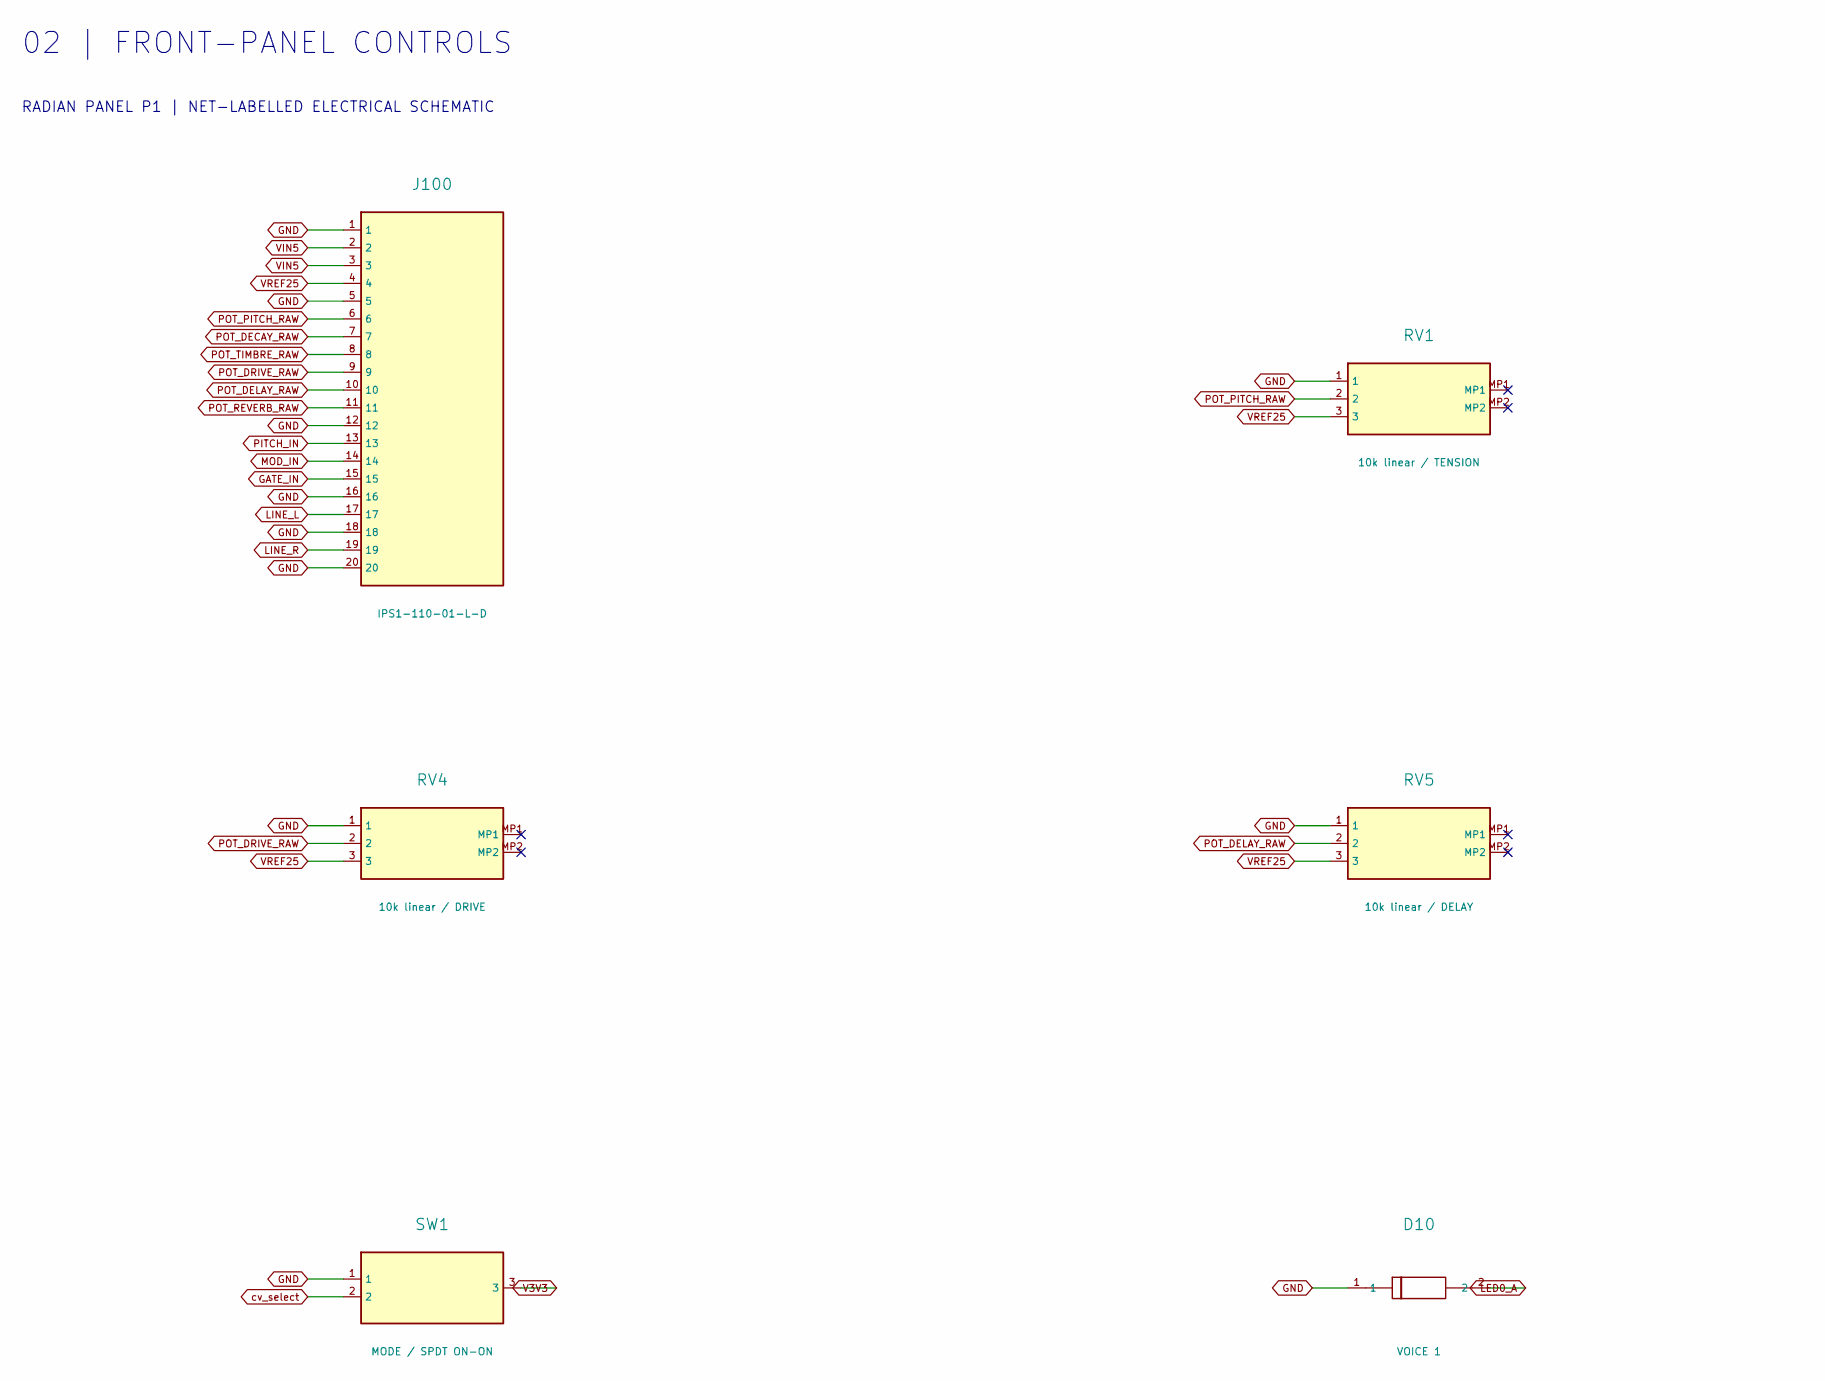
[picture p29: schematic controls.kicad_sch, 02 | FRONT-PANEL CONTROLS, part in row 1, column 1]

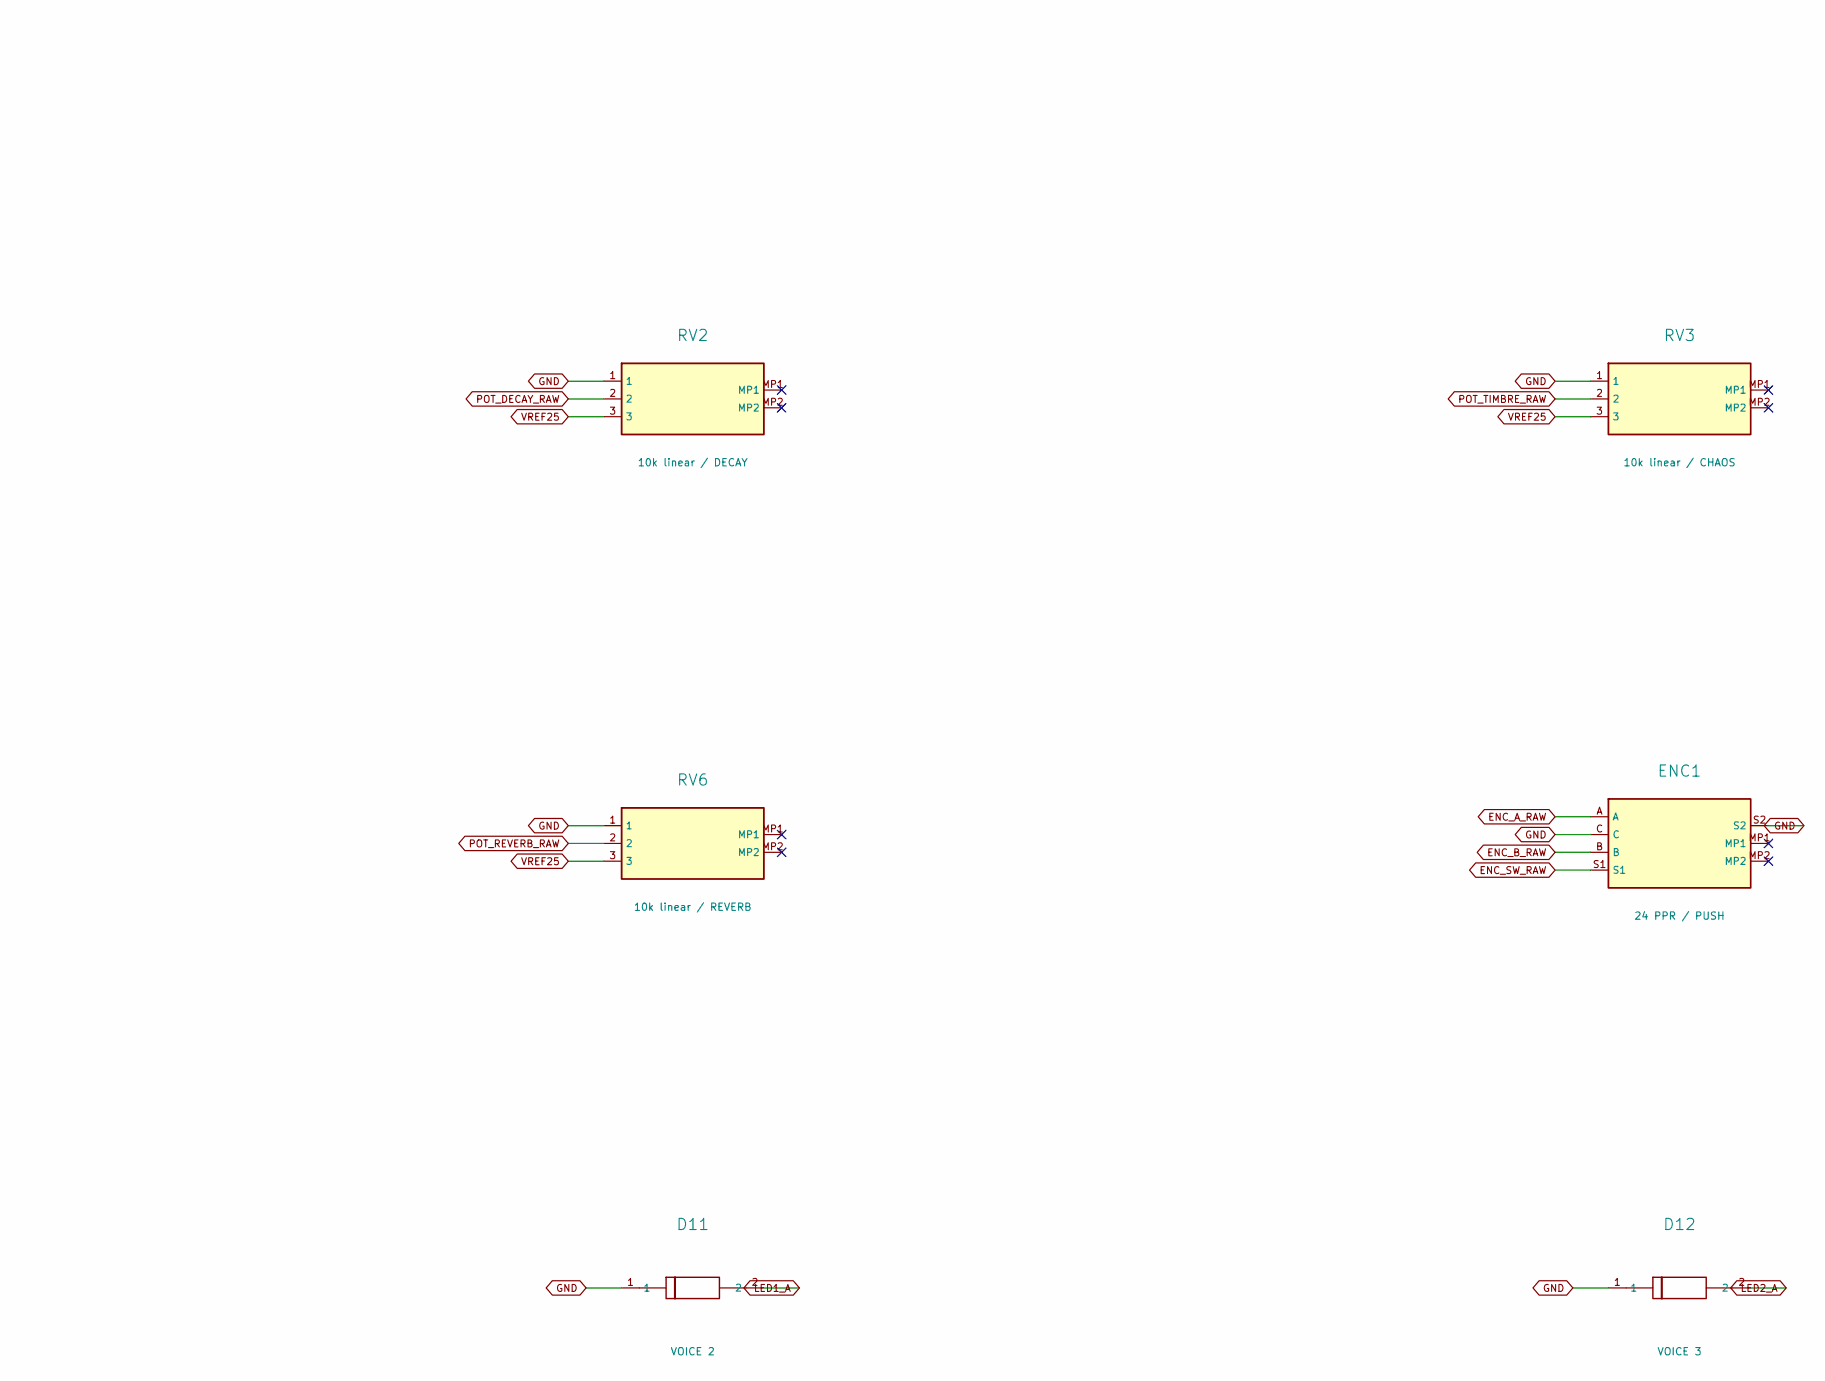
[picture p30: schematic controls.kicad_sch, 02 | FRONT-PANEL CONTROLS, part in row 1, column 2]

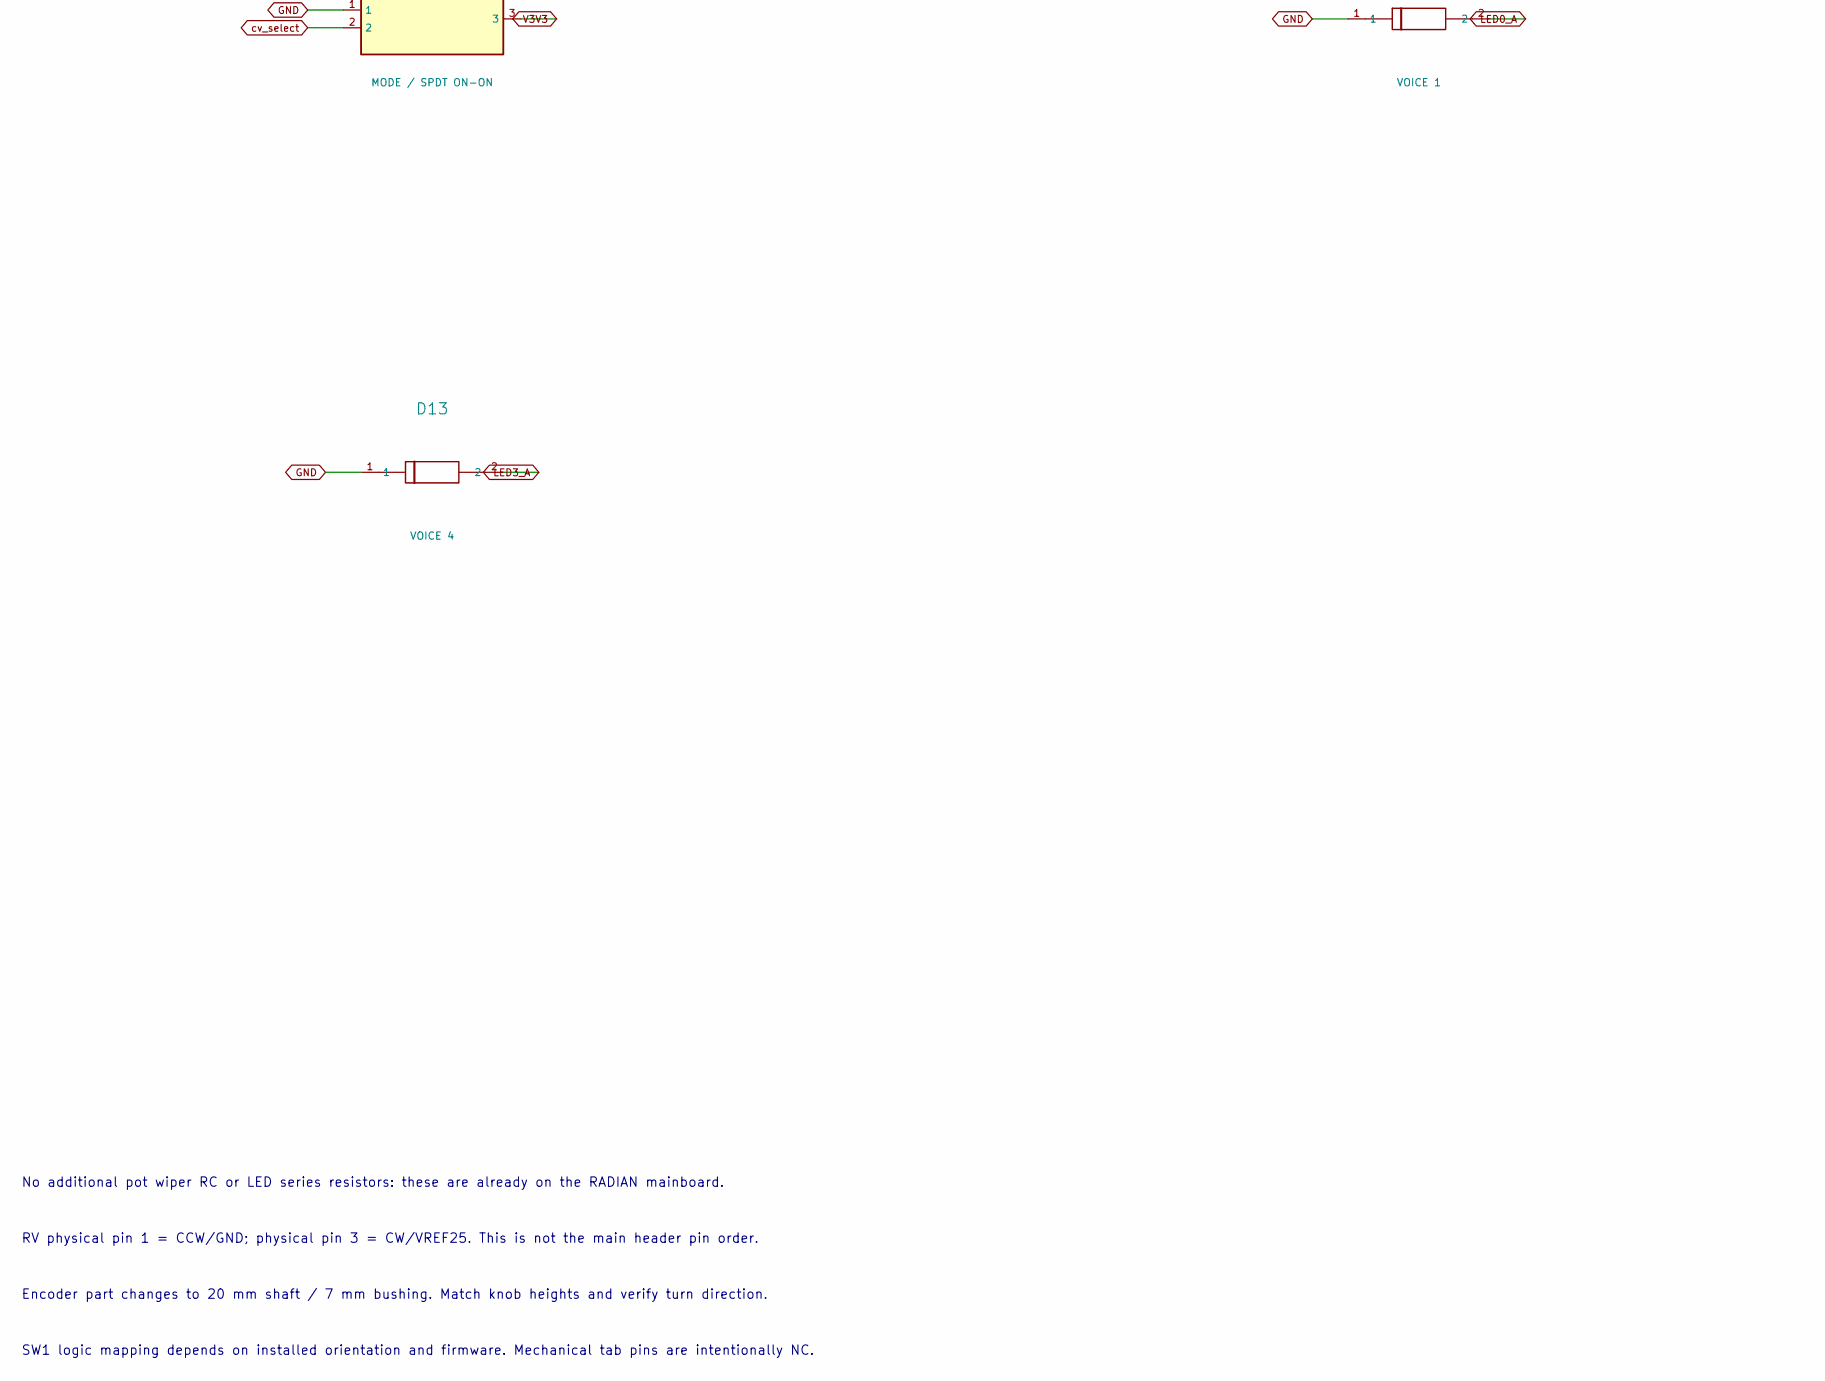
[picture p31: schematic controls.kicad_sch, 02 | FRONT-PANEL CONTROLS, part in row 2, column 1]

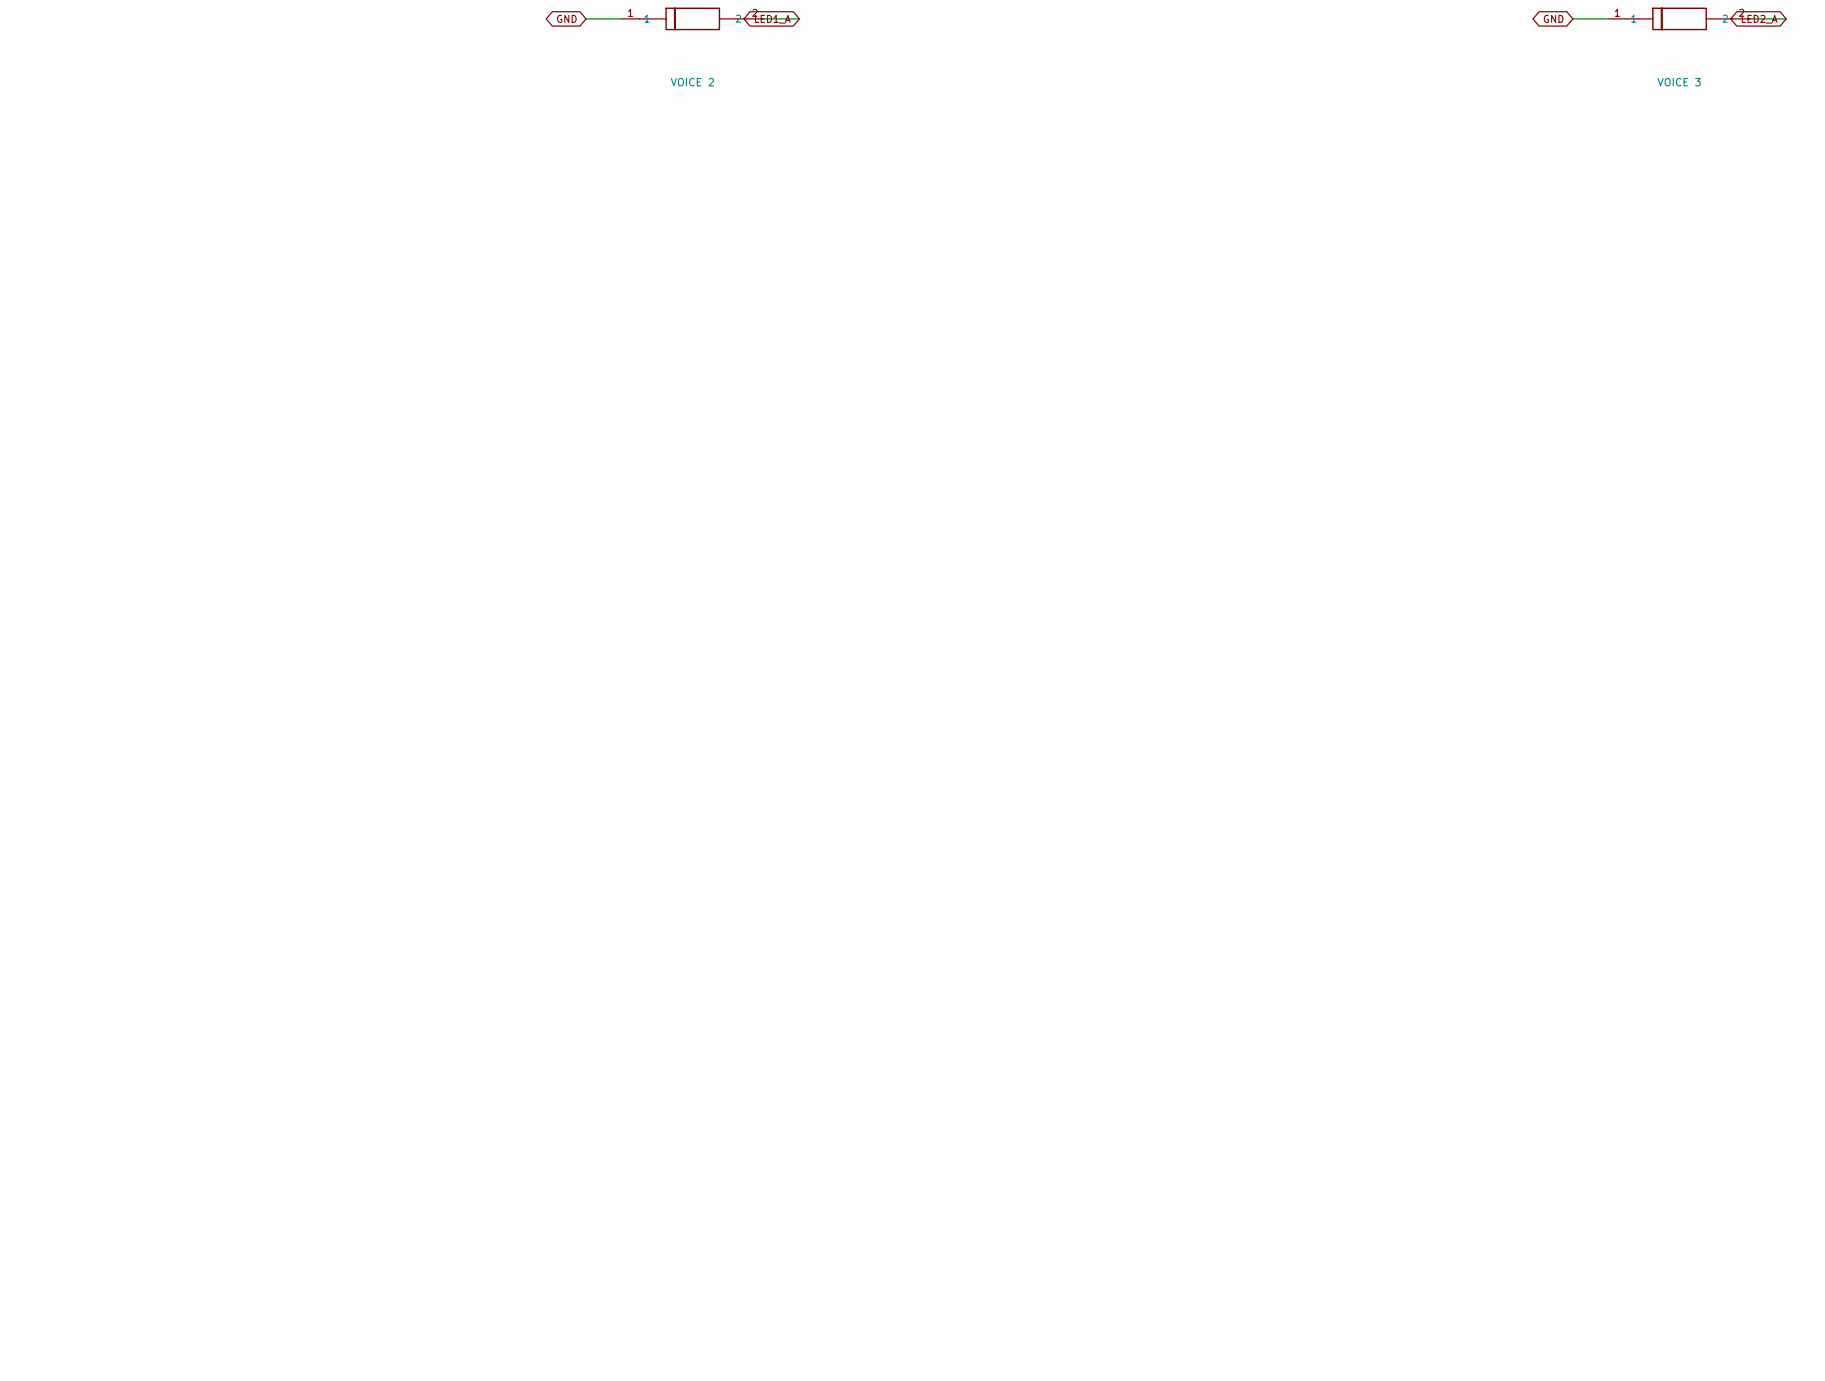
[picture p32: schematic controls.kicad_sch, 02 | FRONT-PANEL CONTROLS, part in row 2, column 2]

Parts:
D10: VOICE 1; LED_D3.0_P2.54; MPN L-934GD
D11: VOICE 2; LED_D3.0_P2.54; MPN L-934GD
D12: VOICE 3; LED_D3.0_P2.54; MPN L-934GD
D13: VOICE 4; LED_D3.0_P2.54; MPN L-934GD
ENC1: 24 PPR / PUSH; Bourns_PEC11R4_RearFacing_Switch; MPN PEC11R-4220F-S0024
J100: IPS1-110-01-L-D; Stack_2x10_P2.54; MPN IPS1-110-01-L-D
RV1: 10k linear / TENSION; Bourns_PTV09A4_RearFacing; MPN PTV09A-4020F-B103
RV2: 10k linear / DECAY; Bourns_PTV09A4_RearFacing; MPN PTV09A-4020F-B103
RV3: 10k linear / CHAOS; Bourns_PTV09A4_RearFacing; MPN PTV09A-4020F-B103
RV4: 10k linear / DRIVE; Bourns_PTV09A4_RearFacing; MPN PTV09A-4020F-B103
RV5: 10k linear / DELAY; Bourns_PTV09A4_RearFacing; MPN PTV09A-4020F-B103
RV6: 10k linear / REVERB; Bourns_PTV09A4_RearFacing; MPN PTV09A-4020F-B103
SW1: MODE / SPDT ON-ON; E_Switch_100SP_M2; MPN 100SP1T1B1M2REH

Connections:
ENC_A_RAW: ENC1.A; also elsewhere on the board
ENC_B_RAW: ENC1.B; also elsewhere on the board
ENC_SW_RAW: ENC1.S1; also elsewhere on the board
GATE_IN: J100.15; also elsewhere on the board
GND: D10.1, D11.1, D12.1, D13.1, ENC1.C, ENC1.S2, J100.1, J100.5, J100.12, J100.16, J100.18, J100.20, RV1.1, RV2.1, RV3.1, RV4.1, RV5.1, RV6.1, SW1.1; also elsewhere on the board
LED0_A: D10.2; also elsewhere on the board
LED1_A: D11.2; also elsewhere on the board
LED2_A: D12.2; also elsewhere on the board
LED3_A: D13.2; also elsewhere on the board
LINE_L: J100.17; also elsewhere on the board
LINE_R: J100.19; also elsewhere on the board
MOD_IN: J100.14; also elsewhere on the board
PITCH_IN: J100.13; also elsewhere on the board
POT_DECAY_RAW: J100.7, RV2.2
POT_DELAY_RAW: J100.10, RV5.2
POT_DRIVE_RAW: J100.9, RV4.2
POT_PITCH_RAW: J100.6, RV1.2
POT_REVERB_RAW: J100.11, RV6.2
POT_TIMBRE_RAW: J100.8, RV3.2
V3V3: SW1.3; also elsewhere on the board
VIN5: J100.2, J100.3; also elsewhere on the board
VREF25: J100.4, RV1.3, RV2.3, RV3.3, RV4.3, RV5.3, RV6.3; also elsewhere on the board
cv_select: SW1.2; also elsewhere on the board

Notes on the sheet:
02 | FRONT-PANEL CONTROLS
RADIAN PANEL P1 | NET-LABELLED ELECTRICAL SCHEMATIC
No additional pot wiper RC or LED series resistors: these are already on the RADIAN mainboard.
RV physical pin 1 = CCW/GND; physical pin 3 = CW/VREF25. This is not the main header pin order.
Encoder part changes to 20 mm shaft / 7 mm bushing. Match knob heights and verify turn direction.
SW1 logic mapping depends on installed orientation and firmware. Mechanical tab pins are intentionally NC.

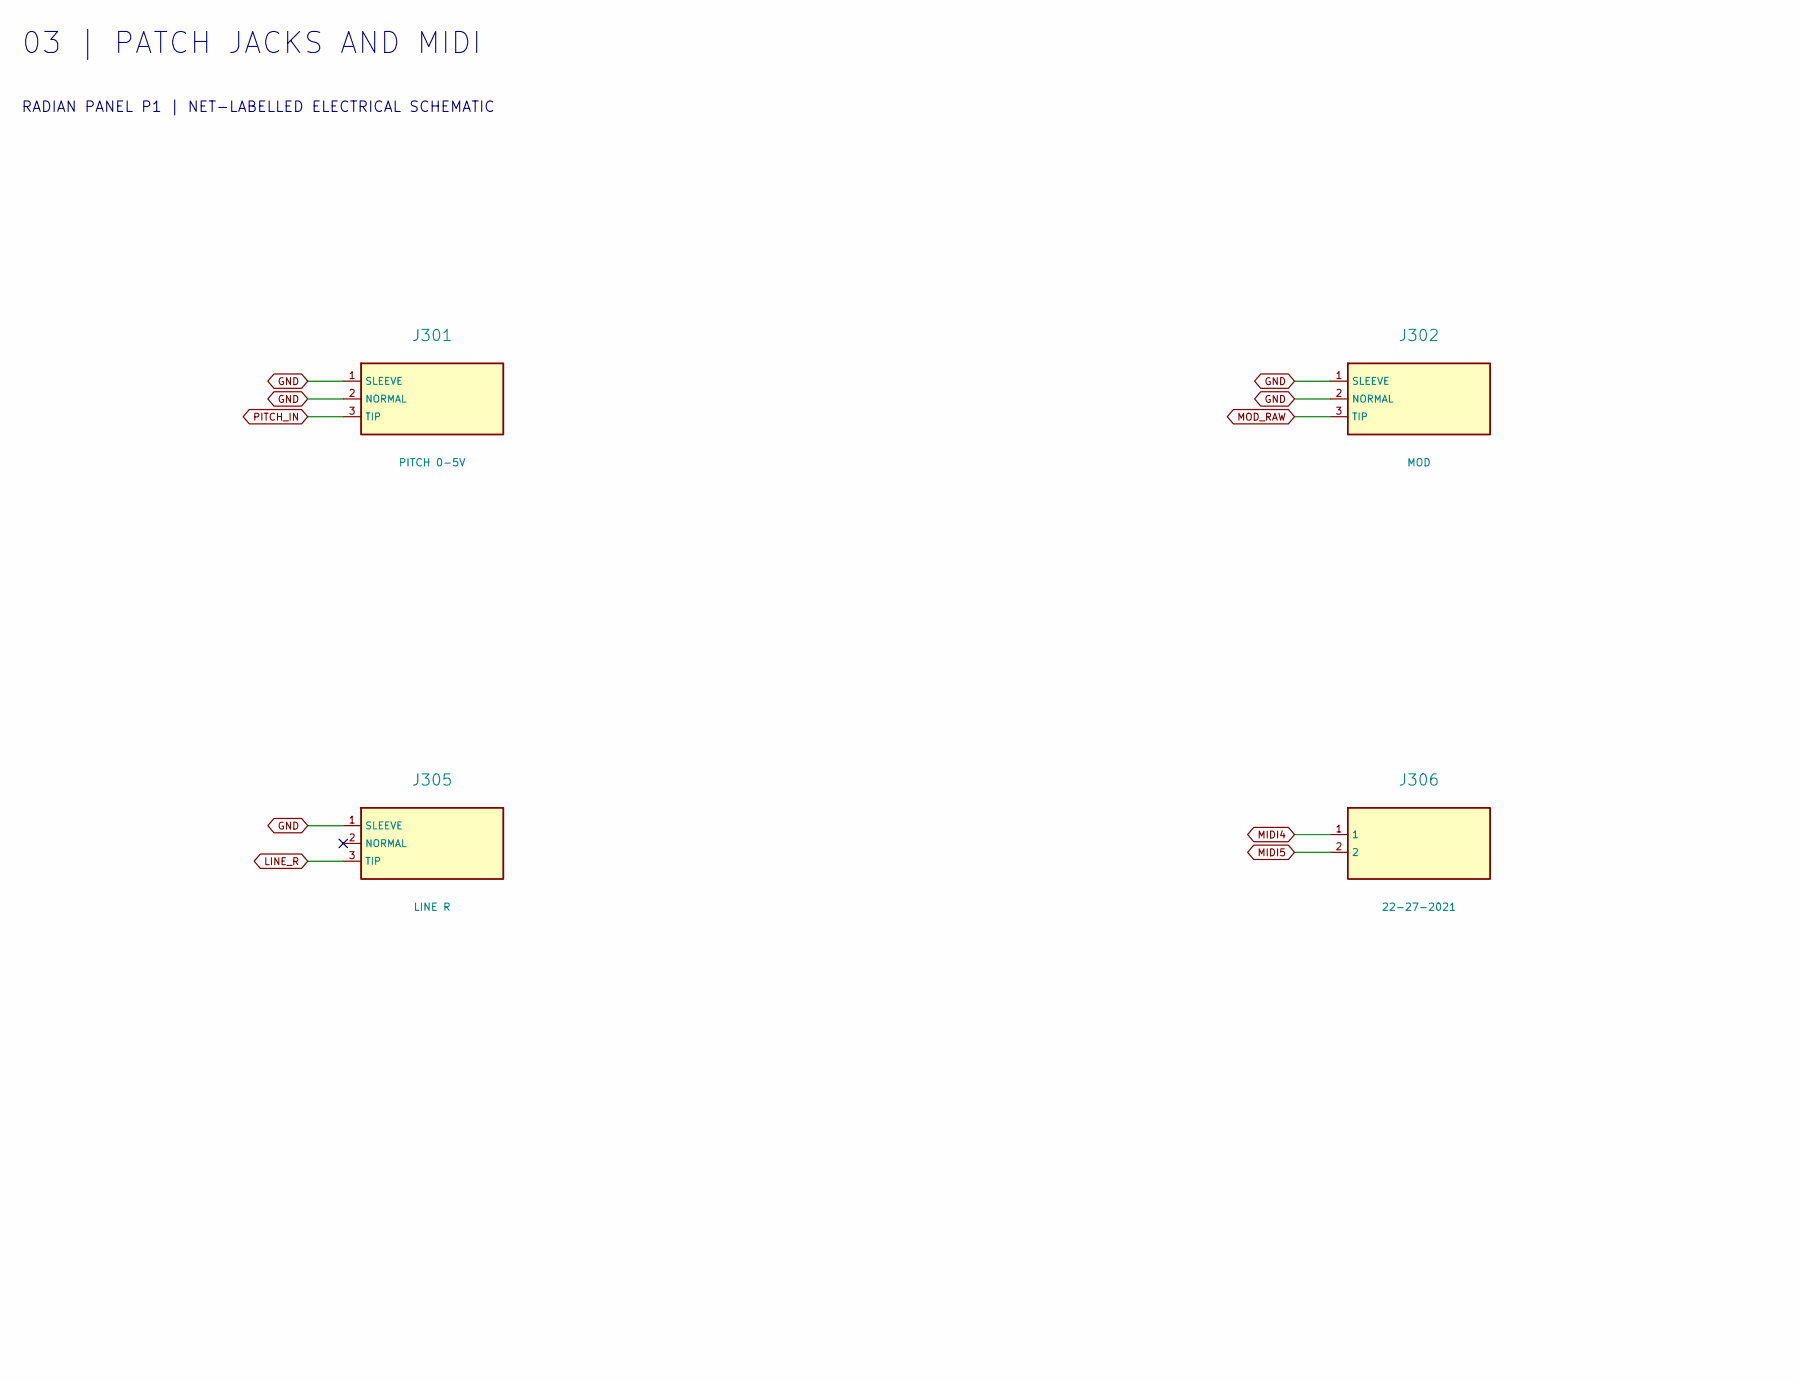
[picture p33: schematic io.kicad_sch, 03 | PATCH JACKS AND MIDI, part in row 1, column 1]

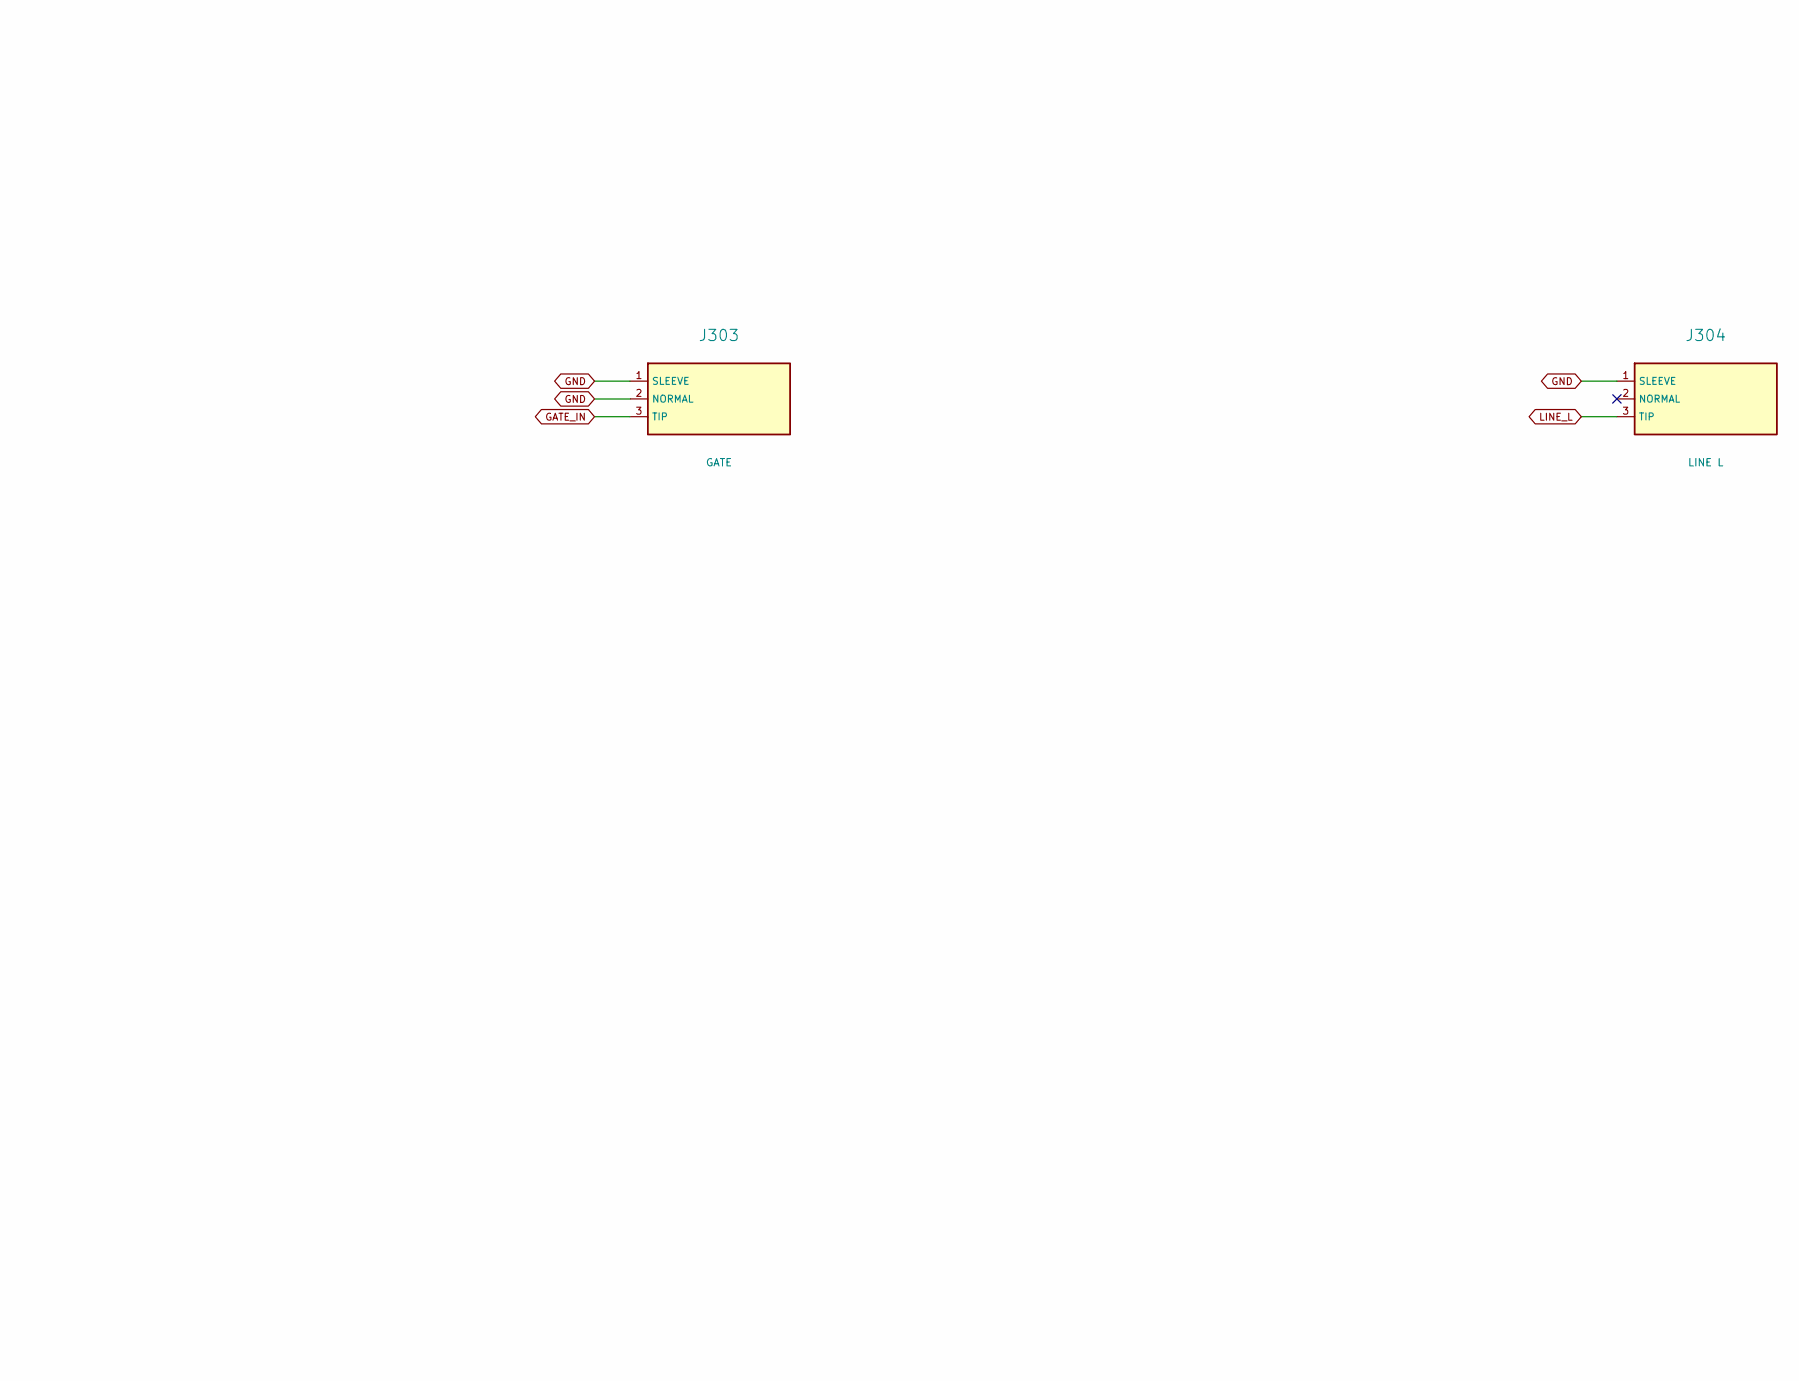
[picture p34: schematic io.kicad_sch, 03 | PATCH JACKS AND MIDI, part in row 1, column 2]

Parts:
J301: PITCH 0-5V; WQP518MA_PJ398SM_Vertical; MPN WQP518MA (Thonkiconn/PJ398SM)
J302: MOD; WQP518MA_PJ398SM_Vertical; MPN WQP518MA (Thonkiconn/PJ398SM)
J303: GATE; WQP518MA_PJ398SM_Vertical; MPN WQP518MA (Thonkiconn/PJ398SM)
J304: LINE L; WQP518MA_PJ398SM_Vertical; MPN WQP518MA (Thonkiconn/PJ398SM)
J305: LINE R; WQP518MA_PJ398SM_Vertical; MPN WQP518MA (Thonkiconn/PJ398SM)
J306: 22-27-2021; Molex_22-27-2021_J306_B; MPN 22-27-2021

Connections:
GATE_IN: J303.3 (TIP); also elsewhere on the board
GND: J301.1 (SLEEVE), J301.2 (NORMAL), J302.1 (SLEEVE), J302.2 (NORMAL), J303.1 (SLEEVE), J303.2 (NORMAL), J304.1 (SLEEVE), J305.1 (SLEEVE); also elsewhere on the board
LINE_L: J304.3 (TIP); also elsewhere on the board
LINE_R: J305.3 (TIP); also elsewhere on the board
MIDI4: J306.1; also elsewhere on the board
MIDI5: J306.2; also elsewhere on the board
MOD_RAW: J302.3 (TIP); also elsewhere on the board
PITCH_IN: J301.3 (TIP); also elsewhere on the board

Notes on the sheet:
03 | PATCH JACKS AND MIDI
RADIAN PANEL P1 | NET-LABELLED ELECTRICAL SCHEMATIC
Pitch and Gate follow the existing mainboard front ends. LINE L/R are NOT new modular-level or headphone drivers.
WQP518MA: 1=SLEEVE, 2=NORMAL, 3=TIP. Inputs normal to ground; output normal pins intentionally NC.
DIN socket remains panel-supported off-board with two wires. Keep DIN pin 2/shield isolated from board GND.
Input overvoltage, unpowered behavior, jack insertion shorts and output back-drive still need bench validation.

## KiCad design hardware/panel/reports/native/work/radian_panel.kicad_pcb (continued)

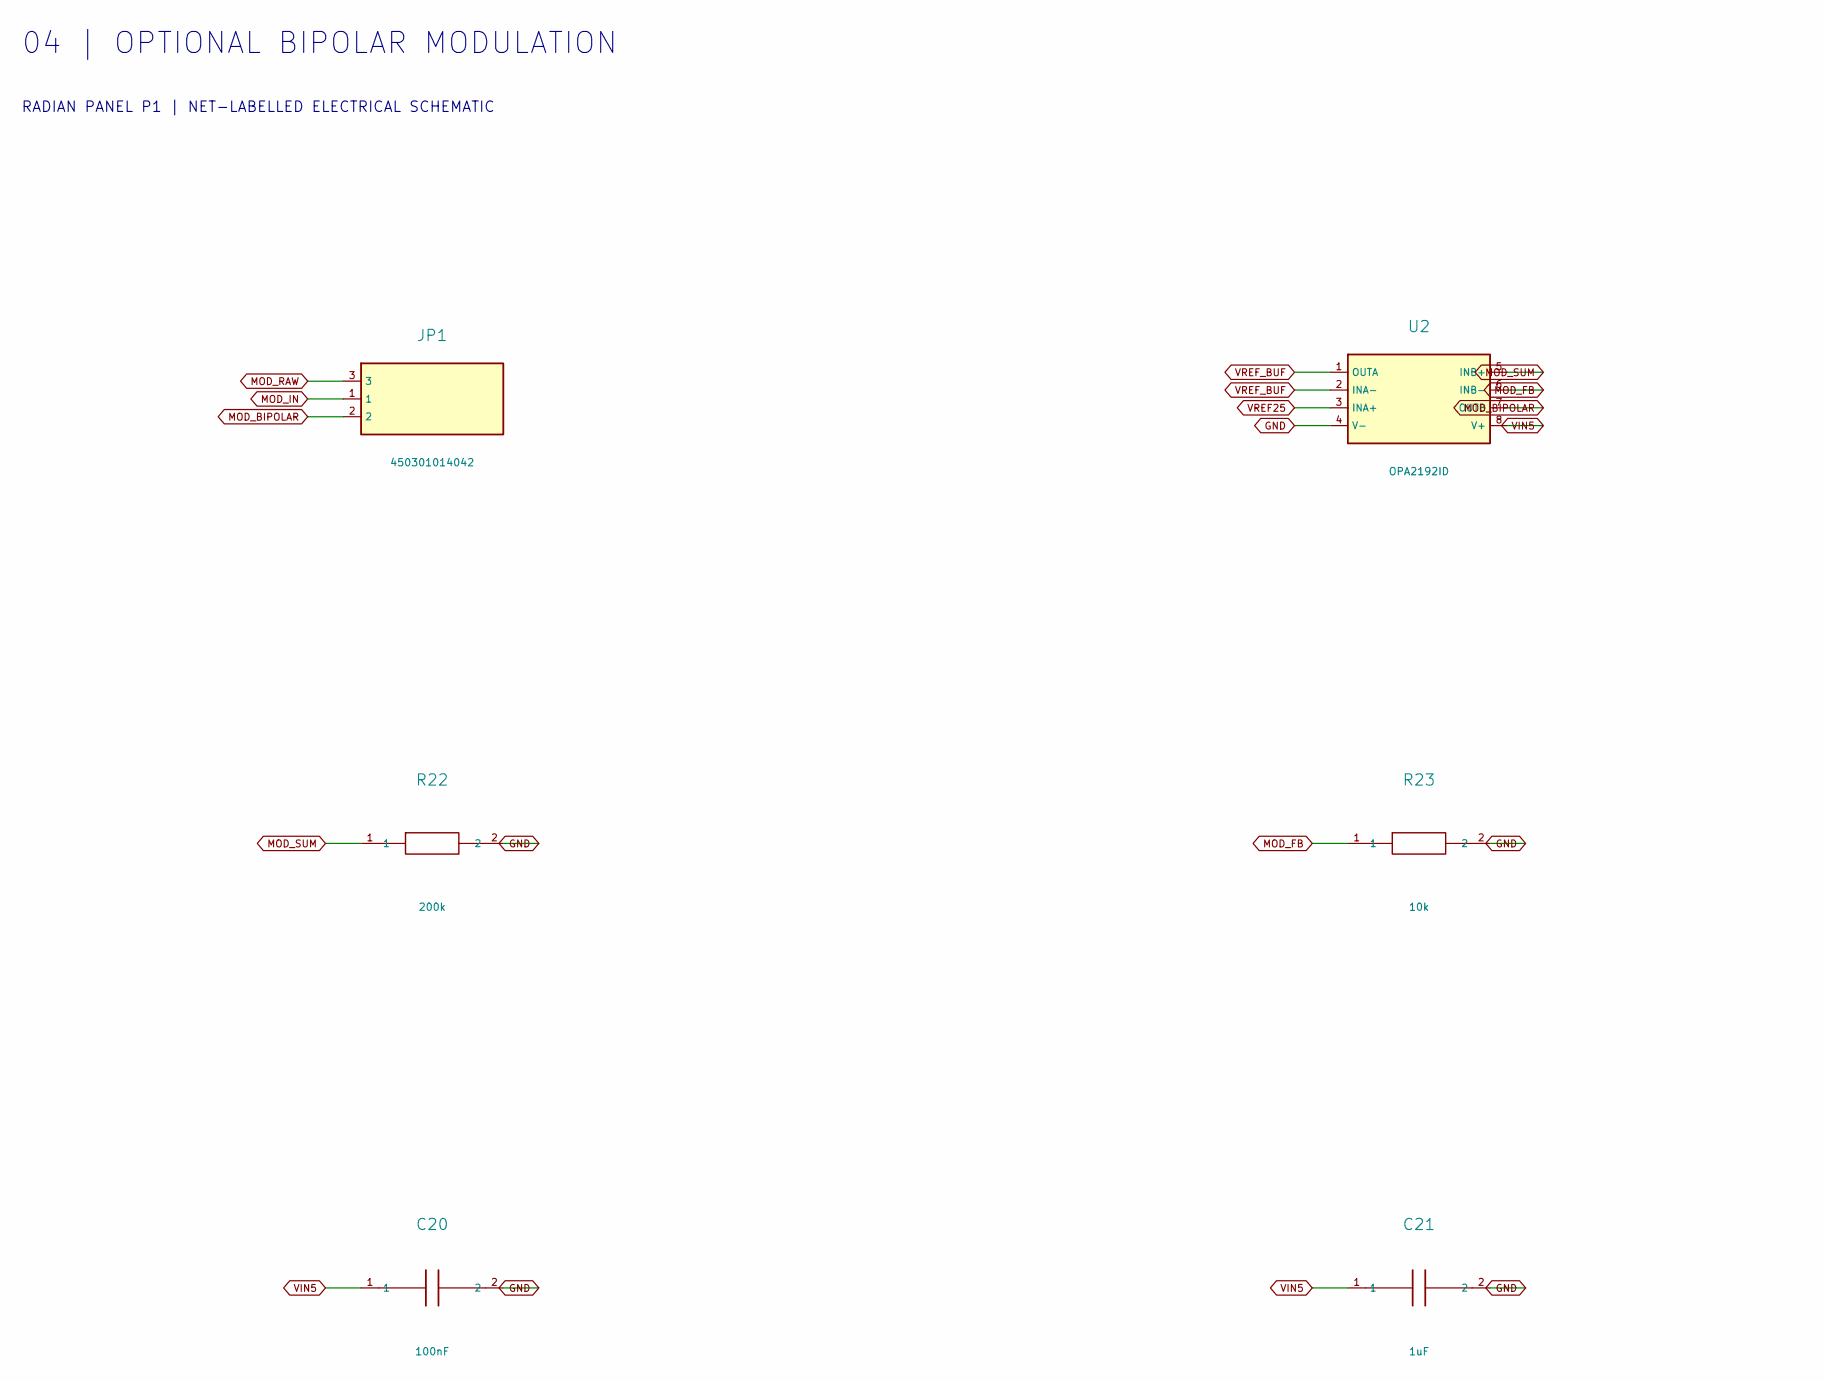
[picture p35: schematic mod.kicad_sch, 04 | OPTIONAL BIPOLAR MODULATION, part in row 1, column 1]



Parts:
C20: 100nF; C_0603; MPN SELECT 100nF 16V X7R 0603
C21: 1uF; C_0805; MPN SELECT 1uF 16V X7R 0805
D4: BAT54S; SOT23_BAT54S; MPN BAT54S,215
JP1: 450301014042; Wurth_450301014042_Exact_B; MPN 450301014042
R20, R22: 200k; R_0603; MPN SELECT 200k 0.1% 0603
R21: 100k; R_0603; MPN SELECT 100k 0.1% 0603
R23, R24: 10k; R_0603; MPN SELECT 10k 0.1% 0603
TP4: VREF25; TestPoint_D2; MPN PCB test pad
TP5: MOD_BIPOLAR; TestPoint_D2; MPN PCB test pad
U2: OPA2192ID; SOIC8_3.9x4.9_P1.27; MPN OPA2192ID

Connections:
GND: C20.2, C21.2, D4.1, R22.2, R23.2, U2.4 (V-); also elsewhere on the board
MOD_BIPOLAR: JP1.2, R24.1, TP5.1, U2.7 (OUTB)
MOD_FB: R23.1, R24.2, U2.6 (INB-)
MOD_IN: JP1.1; also elsewhere on the board
MOD_RAW: JP1.3, R20.1; also elsewhere on the board
MOD_SUM: D4.3, R20.2, R21.2, R22.1, U2.5 (INB+)
VIN5: C20.1, C21.1, D4.2, U2.8 (V+); also elsewhere on the board
VREF25: TP4.1, U2.3 (INA+); also elsewhere on the board
VREF_BUF: R21.1, U2.1 (OUTA), U2.2 (INA-)

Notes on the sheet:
04 | OPTIONAL BIPOLAR MODULATION
RADIAN PANEL P1 | NET-LABELLED ELECTRICAL SCHEMATIC
JP1 is an SPDT configuration switch: one throw selects direct unipolar MOD_RAW; the other selects MOD_BIPOLAR.
OPTIONAL: shunt 2-3 = bipolar conversion. Ideal Vout = 0.5*Vin + VREF25. -5/0/+5 V -> 0/2.5/5 V.
5 V op-amp cannot reach exact rails under load. Endpoints, tolerance, saturation and calibration need testing.
Do not rescale the PITCH input implicitly. Bipolar MOD requires a matching firmware range/zero configuration.



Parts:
J101: IPS1-110-01-L-D; Stack_2x10_P2.54; MPN IPS1-110-01-L-D
J202: 22-27-2061; Molex_22-27-2061_J202_B; MPN 22-27-2061
SW3: PROGRAM / SERVICE; SW_PUSH_6x6_P6.5x4.5; MPN B3F-1000
SW4: RESET / SERVICE; SW_PUSH_6x6_P6.5x4.5; MPN B3F-1000

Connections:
ENC_A_RAW: J101.4; also elsewhere on the board
ENC_B_RAW: J101.5; also elsewhere on the board
ENC_SW_RAW: J101.6; also elsewhere on the board
GND: J101.1, J101.3, J101.12, J202.2, SW3.2, SW4.2; also elsewhere on the board
JTAG_TCK: J101.17, J202.3
JTAG_TDI: J101.19, J202.5
JTAG_TDO: J101.18, J202.4
JTAG_TMS: J101.20, J202.6
LED0_A: J101.8; also elsewhere on the board
LED1_A: J101.9; also elsewhere on the board
LED2_A: J101.10; also elsewhere on the board
LED3_A: J101.11; also elsewhere on the board
MIDI4: J101.13; also elsewhere on the board
MIDI5: J101.14; also elsewhere on the board
PROGRAM_B: J101.15, SW3.1
V3V3: J101.2, J202.1; also elsewhere on the board
cv_select: J101.7; also elsewhere on the board
reset_n: J101.16, SW4.1

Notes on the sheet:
05 | INTERNAL SERVICE ACCESS
RADIAN PANEL P1 | NET-LABELLED ELECTRICAL SCHEMATIC
Internal-only JTAG, PROGRAM and RESET. No additional exterior cutouts assumed.
Keep programming cables short and verify the actual programmer pinout. No level shifting is added.



Board: 4 copper layers, 180.5 x 108.0 mm, 59 parts (14 on the bottom side), 46 nets.

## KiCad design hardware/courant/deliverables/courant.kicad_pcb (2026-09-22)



Board: 6 copper layers, 160.0 x 100.0 mm, 180 parts (41 on the bottom side), 102 nets.

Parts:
C1, C140, C141: 47uF; C_1210_3225Metric_A
C10, C20, C30, C160: 10uF; C_0805_2012Metric_B
C11, C21, C31, C146, C150, C151, C152, C161, C162, C166, C170, C172, C190, C195, C200: 100nF; C_0603_1608Metric_Radian
C12, C22, C32: 22uF; C_0805_2012Metric_A
C13, C23, C33: 22uF; C_0805_2012Metric_B
C14, C24, C34: 3.3nF; C_0603_1608Metric_Radian
C100, C103, C104, C110, C113, C116, C120, C122, C128: 100nF; C_0201_0603Metric_C
C101, C102, C106, C107, C108, C109, C112, C114, C115, C118, C119, C121, C124, C125, C126, C127, C136: 100nF; C_0201_0603Metric_D
C105, C123, C130, C131, C132, C133, C134, C135: 100nF; C_0201_0603Metric_E
C111, C117, C129: 100nF; C_0201_0603Metric_A
C137: 100nF; C_0201_0603Metric_B
C142: 47uF; C_1210_3225Metric_B
C143, C144: 4.7uF; C_0805_2012Metric_B
C145: 4.7uF; C_0805_2012Metric_A
C163, C164: 2.2uF; C_0603_1608Metric_Radian
C165, C171, C173: 1uF; C_0603_1608Metric_Radian
C167, C168: 2.2nF; C_0603_1608Metric_Radian
C174, C175, C176, C180, C181, C182, C193, C194, C201, C202, C203: 10nF; C_0603_1608Metric_Radian
C191, C192, C196: 1nF; C_0603_1608Metric_Radian
D10, D11, D12: BAT54S; Nexperia_BAT54S_215_SOT23
D20: 1N4148W; Diodes_1N4148W_7_F_SOD123
J1: 22-23-2021; Molex_22_23_2021_RowY
J2: 22-23-2061; Molex_22_23_2061
J3, J4: 22-23-2021; Molex_22_23_2021_RowX
J17, J18: IPT1-110-06-L-D; Samtec_IPT1_110_06_L_D
L1, L2, L3: 1µH; Changjiang_FNR4030S1R0MT
R10: 24.9kΩ; R_0603_1608Metric_Radian
R11, R21, R31, R166: 100kΩ; R_0603_1608Metric_Radian
R12, R22, R32, R103, R104, R105, R106, R121, R130, R143, R144, R145, R146, R169: 10kΩ; R_0603_1608Metric_Radian
R20: 124kΩ; R_0603_1608Metric_Radian
R30: 316kΩ; R_0603_1608Metric_Radian
R100, R101, R102, R111, R112, R113: 4.7kΩ; R_0603_1608Metric_Radian
R110, R114, R115, R122, R123, R124, R125: 33Ω; R_0603_1608Metric_Radian
R120: 1Ω; R_0603_1608Metric_Radian
R126, R127: 470Ω; R_0603_1608Metric_Radian
R131, R132, R133, R140, R141, R142, R147, R148, R149, R150, R190, R191, R192: 1kΩ; R_0603_1608Metric_Radian
R160, R161, R163, R164: 20kΩ; R_0603_1608Metric_Radian
R162, R165: 100Ω; R_0603_1608Metric_Radian
R167: 33kΩ; R_0603_1608Metric_Radian
R168: 40.2kΩ; R_0603_1608Metric_Radian
R180: 220Ω; R_0603_1608Metric_Radian
R181: 2.2kΩ; R_0603_1608Metric_Radian
U1: XC7A50T-1FTG256I; XC7A50T_1FTG256I_FTG256
U2: W25Q64JVSSIQ; W25Q64JVSSIQ_SOIC8_208mil
U3: PCM5102APWR; PCM5102APWR_TSSOP20
U4: MCP3208-CI/SL; MCP3208_CI_SL_SOIC16
U5: REF3125AIDBZR; REF3125AIDBZR_SOT23
U6: MCP6002-I/SN; MCP6002_I_SN_SOIC8
U7: MCP6561T-E/OT; MCP6561T_E_OT_SOT23_5
U8: H11L1M; H11L1M_DIP6
U11, U12, U13: TPS62130ARGTR; TPS62130ARGTR_WQFN16
Y1: ASE-100.000MHZ-LC-T; Abracon_ASE_3225_4Pin
Y2: ASE-12.288MHZ-LC-T; Abracon_ASE_3225_4Pin

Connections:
A3V3: C160.1, C161.1, C162.1, R120.2, U3.1, U3.8
CLK100_RAW: R114.1, Y1.3
DAC_CAPM: C163.2, U3.4
DAC_CAPP: C163.1, U3.2
DAC_L: R126.1, U3.6
DAC_LDO: C165.1, U3.18
DAC_R: R127.1, U3.7
DAC_VNEG: C164.1, U3.5
DONE: R101.1, U1.122
ENC_A_RAW: J18.4, R140.1
ENC_B_RAW: J18.5, R141.1
ENC_SW_RAW: J18.6, R142.1
FB1: R10.2, R11.1, U11.5
FB2: R20.2, R21.1, U12.5
FB3: R30.2, R31.1, U13.5
FLASH_CLK: R110.2, U2.6
FLASH_CLK_RAW: R110.1, U1.72
FLASH_CS: R111.1, U1.172, U2.1
FLASH_HOLD: R113.1, U1.160, U2.7
FLASH_MISO: U1.142, U2.2
FLASH_MOSI: U1.141, U2.5
FLASH_WP: R112.1, U1.159, U2.3
GATE_DIV: C196.1, D12.3, R166.2, R167.1, U7.3
GATE_IN: J17.15, R166.1
GATE_REF: R168.2, R169.1, U7.4
GND: C1.2, C10.2, C11.2, C12.2, C13.2, C14.2, C20.2, C21.2, C22.2, C23.2, C24.2, C30.2, C31.2, C32.2, C33.2, C34.2, C100.2, C101.2, C102.2, C103.2, C104.2, C105.2, C106.2, C107.2, C108.2, C109.2, C110.2, C111.2, C112.2, C113.2, C114.2, C115.2, C116.2, C117.2, C118.2, C119.2, C120.2, C121.2, C122.2, C123.2, C124.2, C125.2, C126.2, C127.2, C128.2, C129.2, C130.2, C131.2, C132.2, C133.2, C134.2, C135.2, C136.2, C137.2, C140.2, C141.2, C142.2, C143.2, C144.2, C145.2, C146.2, C150.2, C151.2, C152.2, C160.2, C161.2, C162.2, C164.2, C165.2, C166.2, C167.2, C168.2, C170.2, C171.2, C172.2, C173.2, C174.2, C175.2, C176.2, C180.2, C181.2, C182.2, C190.2, C191.2, C192.2, C193.2, C194.2, C195.2, C196.2, C200.2, C201.2, C202.2, C203.2, D10.1, D11.1, D12.1, J1.2, J2.2, J3.2, J4.2, J17.1, J17.5, J17.12, J17.16, J17.18, J17.20, J18.1, J18.3, J18.12, R11.2, R21.2, R31.2, R105.2, R121.2, R146.2, R161.2, R164.2, R167.2, R169.2, U1.1, U1.11, U1.24, U1.37, U1.47, U1.50, U1.60, U1.73, U1.86, U1.88, U1.90, U1.96, U1.99, U1.103, U1.105, U1.109, U1.118, U1.119, U1.120, U1.135, U1.136, U1.137, U1.139, U1.148, U1.150, U1.158, U1.161, U1.171, U1.184, U1.186, U1.187, U1.197, U1.207, U1.210, U1.220, U1.233, U1.246, U1.256, U2.4, U3.3, U3.9, U3.10, U3.11, U3.16, U3.19, U4.9, U4.14, U5.3, U6.4, U7.2, U8.5, U11.6, U11.7, U11.8, U11.15, U11.16, U11.17, U12.6, U12.7, U12.8, U12.15, U12.16, U12.17, U13.6, U13.7, U13.8, U13.15, U13.16, U13.17, Y1.2, Y2.2
I2S_BCLK: R123.2, U3.13
I2S_DATA: R125.2, U3.14
I2S_LRCLK: R124.2, U3.15
I2S_MCLK: R122.2, U3.12
INIT_B: R100.1, U1.154
JTAG_TCK: J2.3, J18.17, R105.1, U1.167
JTAG_TDI: J2.5, J18.19, R104.1, U1.199
JTAG_TDO: J2.4, J18.18, U1.200
JTAG_TMS: J2.6, J18.20, R103.1, U1.183
LED0_A: J18.8, R147.2
LED1_A: J18.9, R148.2
LED2_A: J18.10, R149.2
LED3_A: J18.11, R150.2
LINE_L: C167.1, J17.17, R126.2
LINE_R: C168.1, J17.19, R127.2
MCLK_RAW: R115.1, Y2.3
MIDI4: J18.13, R180.1
MIDI5: D20.1, J18.14, U8.2
MIDI_A: D20.2, R180.2, U8.1
MOD_ADC: C194.1, R165.2, U4.5
MOD_BUF: R165.1, U6.6, U6.7
MOD_DIV: C192.1, D11.3, R163.2, R164.1, U6.5
MOD_IN: J17.14, R163.1
PG1: R12.1, U11.4, U12.13
PG18: R22.1, U12.4, U13.13
PITCH_ADC: C193.1, R162.2, U4.4
PITCH_BUF: R162.1, U6.1, U6.2
PITCH_DIV: C191.1, D10.3, R160.2, R161.1, U6.3
PITCH_IN: J17.13, R160.1
POT_DECAY: C175.1, R132.2, U4.2
POT_DECAY_RAW: J17.7, R132.1
POT_DELAY: C202.1, R191.2, U4.7
POT_DELAY_RAW: J17.10, R191.1
POT_DRIVE: C201.1, R190.2, U4.6
POT_DRIVE_RAW: J17.9, R190.1
POT_PITCH: C174.1, R131.2, U4.1
POT_PITCH_RAW: J17.6, R131.1
POT_REVERB: C203.1, R192.2, U4.8
POT_REVERB_RAW: J17.11, R192.1
POT_TIMBRE: C176.1, R133.2, U4.3
POT_TIMBRE_RAW: J17.8, R133.1
PROGRAM_B: J3.1, J18.15, R32.1, U1.169, U13.4
PUDC_B: R102.1, U1.175
SS1: C14.1, U11.9
SS2: C24.1, U12.9
SS3: C34.1, U13.9
SW1: L1.1, U11.1, U11.2, U11.3
SW2: L2.1, U12.1, U12.2, U12.3
SW3: L3.1, U13.1, U13.2, U13.3
V1: C12.1, C13.1, C100.1, C101.1, C102.1, C103.1, C104.1, C105.1, C106.1, C107.1, C108.1, C140.1, C143.1, L1.2, R10.1, U1.74, U1.87, U1.89, U1.91, U1.102, U1.121, U1.134, U1.153, U1.168, U11.14
V1V8: C22.1, C23.1, C109.1, C110.1, C111.1, C112.1, C113.1, C141.1, C144.1, L2.2, R20.1, U1.104, U1.106, U1.138, U1.155, U1.170, U12.14
V3V3: C32.1, C33.1, C114.1, C115.1, C116.1, C117.1, C118.1, C119.1, C120.1, C121.1, C122.1, C123.1, C124.1, C125.1, C126.1, C127.1, C128.1, C129.1, C130.1, C131.1, C132.1, C133.1, C134.1, C135.1, C136.1, C137.1, C142.1, C145.1, C150.1, C151.1, C152.1, C166.1, C170.1, C172.1, C190.1, C195.1, C200.1, D10.2, D11.2, D12.2, J2.1, J18.2, L3.2, R30.1, R32.2, R100.2, R101.2, R102.2, R103.2, R104.2, R106.2, R111.2, R112.2, R113.2, R120.1, R130.2, R143.2, R144.2, R145.2, R181.2, U1.6, U1.16, U1.19, U1.29, U1.42, U1.55, U1.68, U1.71, U1.78, U1.81, U1.127, U1.130, U1.140, U1.166, U1.176, U1.179, U1.185, U1.189, U1.202, U1.215, U1.228, U1.238, U1.241, U1.251, U2.8, U3.20, U4.16, U5.1, U6.8, U7.5, U8.6, U13.14, Y1.1, Y1.4, Y2.1, Y2.4
VIN5: C1.1, C10.1, C11.1, C20.1, C21.1, C30.1, C31.1, J1.1, J17.2, J17.3, R12.2, R22.2, U11.10, U11.11, U11.12, U11.13, U12.10, U12.11, U12.12, U13.10, U13.11, U13.12
VREF25: C171.1, C173.1, J17.4, R168.1, U4.15, U5.2
adc_cs_n: R130.1, U1.5, U4.10
adc_miso: U1.4, U4.12
adc_mosi: U1.20, U4.11
adc_sclk: U1.3, U4.13
audio_mclk_in: R115.2, U1.67
clk100: R114.2, U1.52
cv_select: J18.7, R146.1, U1.9
dac_bclk: R123.1, U1.248
dac_data: R125.1, U1.250
dac_lrclk: R124.1, U1.249
dac_mclk: R122.1, U1.247
dac_unmute: R121.1, U1.252, U3.17
enc_a: C180.1, R140.2, R143.1, U1.7
enc_b: C181.1, R141.2, R144.1, U1.23
enc_btn_n: C182.1, R142.2, R145.1, U1.8
gate: U1.10, U7.1
led0: R147.1, U1.12
led1: R148.1, U1.28
led2: R149.1, U1.13
led3: R150.1, U1.14
midi_rx: R181.1, U1.25, U8.4
reset_n: C146.1, J4.1, J18.16, R106.1, U1.26

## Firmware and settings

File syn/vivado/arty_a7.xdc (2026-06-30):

# arty_a7.xdc - timing & I/O constraints for top_resonator on a Digilent Arty A7
#
# Target: Arty A7 (Xilinx Artix-7) + Pmod I2S2 audio codec on Pmod header JA.
# Covers everything needed for a clean place & route at 100 MHz (issue #25):
#   * the two independent clocks (system 100 MHz, I2S bit clock) and their
#     I/O pin assignments,
#   * the asynchronous clock-domain crossing between them (the cdc_word
#     instances), constrained as a false path with a bounded bus skew so the
#     multi-bit word cannot tear,
#   * the asynchronous reset, treated as a false path into both domains.
#
# Pin LOCs are the Arty A7 board defaults (system clock E3, BTN0 D9) and the
# Pmod JA header (JA1=G13, JA2=B11, JA3=A11, JA4=D12, JA7=D13). Adjust the Pmod
# pins to your wiring; the timing constraints below are independent of the LOCs.

#==============================================================================
# Clocks
#==============================================================================

## System clock - on-board 100 MHz oscillator (pin E3)
set_property -dict { PACKAGE_PIN E3  IOSTANDARD LVCMOS33 } [get_ports sys_clk]
create_clock -name sys_clk -period 10.000 [get_ports sys_clk]

## I2S bit clock from the codec (top_resonator is the I2S slave). Period shown
## for a 12.288 MHz BCLK (= 256 * 48 kHz); set to your codec's actual BCLK.
set_property -dict { PACKAGE_PIN B11 IOSTANDARD LVCMOS33 } [get_ports bclk]
create_clock -name bclk -period 81.380 [get_ports bclk]

#==============================================================================
# I2S / Pmod I2S2 data pins (Pmod header JA)
#==============================================================================
## lrclk = word select (LRCK), sd_rx = data from the ADC (SDOUT),
## sd_tx  = data to the DAC (SDIN). The codec master clock (MCLK) is supplied
## externally / by a clocking wizard and is not a top_resonator port.
set_property -dict { PACKAGE_PIN A11 IOSTANDARD LVCMOS33 } [get_ports lrclk]
set_property -dict { PACKAGE_PIN D12 IOSTANDARD LVCMOS33 } [get_ports sd_rx]
set_property -dict { PACKAGE_PIN D13 IOSTANDARD LVCMOS33 } [get_ports sd_tx]

## I2S I/O timing relative to the bit clock (data is MSB-first, sampled on the
## BCLK edge per the I2S frame). Conservative half-period budgets; tighten to
## the codec datasheet numbers for sign-off.
set_input_delay  -clock bclk -max 20.000 [get_ports {lrclk sd_rx}]
set_input_delay  -clock bclk -min  5.000 [get_ports {lrclk sd_rx}]
set_output_delay -clock bclk -max 20.000 [get_ports sd_tx]
set_output_delay -clock bclk -min  5.000 [get_ports sd_tx]

#==============================================================================
# Reset (BTN0)
#==============================================================================
set_property -dict { PACKAGE_PIN D9  IOSTANDARD LVCMOS33 } [get_ports sys_rst]

#==============================================================================
# Clock-domain crossing (cdc_word: excitation in, pickups out)
#==============================================================================
# sys_clk (mesh) and bclk (audio) are independent oscillators. Declare them
# asynchronous: this cuts setup/hold (recovery/removal) analysis on every path
# between the two domains, which is exactly the false path the cdc_word MCP
# handshake relies on (only the 1-bit `req` toggle crosses, resolved by the
# two-flop synchroniser).
set_clock_groups -asynchronous \
  -group [get_clocks sys_clk] -group [get_clocks bclk]

# The blanket async group above is correct for the control/flag crossing, but
# it also stops analysis of the multi-bit holding-register -> destination data
# capture. That bus is read only when stable, yet its bits must still arrive
# within one destination clock period or the captured word could tear. A bus
# skew check survives the async clock group (it is a skew, not a setup, check)
# and bounds exactly that. One per direction; the destination period bounds it.
#   excitation : src=bclk    -> dst=sys_clk  (bound by sys_clk period 10 ns)
#   pickups    : src=sys_clk -> dst=bclk     (bound by bclk    period 81.38 ns)
set_bus_skew -from [get_cells -hierarchical -filter {NAME =~ *cdc_exc/hold_reg*}] \
             -to   [get_cells -hierarchical -filter {NAME =~ *cdc_exc/dst_data_reg*}] 10.000
set_bus_skew -from [get_cells -hierarchical -filter {NAME =~ *cdc_pick/hold_reg*}] \
             -to   [get_cells -hierarchical -filter {NAME =~ *cdc_pick/dst_data_reg*}] 81.380

# If you prefer not to use an async clock group (e.g. you keep some analysed
# paths between the domains), drop the set_clock_groups above and constrain the
# crossing explicitly instead:
#   set_false_path -to [get_cells -hier -filter {NAME =~ *cdc_*/sync_reg[0]*}]
#   set_max_delay -datapath_only \
#     -from [get_cells -hier -filter {NAME =~ *cdc_*/hold_reg*}] \
#     -to   [get_cells -hier -filter {NAME =~ *cdc_*/dst_data_reg*}] 10.000
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

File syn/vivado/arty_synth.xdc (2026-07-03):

# arty_synth.xdc - constraints for arty_synth (synth_top board build, issue #76)
#
# Digilent Arty A7 + Pmod I2S2 (on Pmod header JA). The system and audio clocks
# are generated by the on-board MMCM from the 100 MHz oscillator, so only the
# 100 MHz input is a primary clock; sys_clk / mclk are derived automatically.
# The serial bit clock BCLK is divided from mclk in fabric by i2s_clkgen, so it
# is declared as a generated clock and the mesh (sys_clk) / audio (bclk) domains
# are constrained as an asynchronous crossing (matching arty_a7.xdc).

#==============================================================================
# Primary clock: 100 MHz oscillator
#==============================================================================
set_property -dict { PACKAGE_PIN E3 IOSTANDARD LVCMOS33 } [get_ports clk100]
create_clock -name clk100 -period 10.000 [get_ports clk100]

#==============================================================================
# Buttons / switches (reset + preset controls)
#==============================================================================
## btn0 reset, btn1 preset recall, btn2 preset save
set_property -dict { PACKAGE_PIN D9  IOSTANDARD LVCMOS33 } [get_ports {btn[0]}]
set_property -dict { PACKAGE_PIN C9  IOSTANDARD LVCMOS33 } [get_ports {btn[1]}]
set_property -dict { PACKAGE_PIN B9  IOSTANDARD LVCMOS33 } [get_ports {btn[2]}]
set_property -dict { PACKAGE_PIN B8  IOSTANDARD LVCMOS33 } [get_ports {btn[3]}]
## slide switches -> preset index
set_property -dict { PACKAGE_PIN A8  IOSTANDARD LVCMOS33 } [get_ports {sw[0]}]
set_property -dict { PACKAGE_PIN C11 IOSTANDARD LVCMOS33 } [get_ports {sw[1]}]
set_property -dict { PACKAGE_PIN C10 IOSTANDARD LVCMOS33 } [get_ports {sw[2]}]
set_property -dict { PACKAGE_PIN A10 IOSTANDARD LVCMOS33 } [get_ports {sw[3]}]
## active-voice LEDs
set_property -dict { PACKAGE_PIN H5  IOSTANDARD LVCMOS33 } [get_ports {led[0]}]
set_property -dict { PACKAGE_PIN J5  IOSTANDARD LVCMOS33 } [get_ports {led[1]}]
set_property -dict { PACKAGE_PIN T9  IOSTANDARD LVCMOS33 } [get_ports {led[2]}]
set_property -dict { PACKAGE_PIN T10 IOSTANDARD LVCMOS33 } [get_ports {led[3]}]

#==============================================================================
# Pmod I2S2 codec (Pmod header JA) + MIDI in
#==============================================================================
## JA1 MCLK, JA2 LRCLK, JA3 BCLK, JA4 SDIN (to DAC)
set_property -dict { PACKAGE_PIN G13 IOSTANDARD LVCMOS33 } [get_ports codec_mclk]
set_property -dict { PACKAGE_PIN B11 IOSTANDARD LVCMOS33 } [get_ports codec_lrclk]
set_property -dict { PACKAGE_PIN A11 IOSTANDARD LVCMOS33 } [get_ports codec_bclk]
set_property -dict { PACKAGE_PIN D12 IOSTANDARD LVCMOS33 } [get_ports codec_sdin]
## serial MIDI in (opto-isolated 31250 baud) on JA7
set_property -dict { PACKAGE_PIN D13 IOSTANDARD LVCMOS33 } [get_ports midi_rx]

## front-panel rotary encoder + CV gate (Pmod JB GPIO)
set_property -dict { PACKAGE_PIN E15 IOSTANDARD LVCMOS33 } [get_ports enc_a]
set_property -dict { PACKAGE_PIN E16 IOSTANDARD LVCMOS33 } [get_ports enc_b]
set_property -dict { PACKAGE_PIN D15 IOSTANDARD LVCMOS33 } [get_ports enc_btn]
set_property -dict { PACKAGE_PIN C15 IOSTANDARD LVCMOS33 } [get_ports gate]
set_false_path -from [get_ports {enc_a enc_b enc_btn gate}]

## NOTE: the pot / CV analog samples (pot_pitch/decay/timbre, pitch_cv, mod_cv)
## are digital *sample* ports fed by an XADC or an external SPI/I2S ADC block,
## which is out of scope for this build. Wire them to that ADC's outputs (and
## constrain the ADC's own pins) when it is added; they are left unconstrained
## here so the panel/CV integration synthesises without a placeholder ADC.
set_property SEVERITY {Warning} [get_drc_checks NSTD-1]
set_property SEVERITY {Warning} [get_drc_checks UCIO-1]

#==============================================================================
# Clock-domain crossing (mesh sys_clk  <->  audio bclk)
#==============================================================================
# BCLK is mclk/4, produced by i2s_clkgen in fabric; declare it as a generated
# clock so the tools see the audio domain. (Adjust the source pin/net name to
# the elaborated design if the auto-inference does not pick it up.)
create_generated_clock -name bclk -source [get_pins -hier -filter {NAME =~ *i2s_clkgen*bclk_i_reg*/C}] \
  -divide_by 4 [get_pins -hier -filter {NAME =~ *i2s_clkgen*bclk_i_reg*/Q}]

# The mesh (sys_clk) and audio (bclk) domains are independent: cut setup/hold on
# the crossing (the cdc_word MCP handshake relies on this) and bound the
# multi-bit pickup word's skew so it cannot tear.
set_clock_groups -asynchronous \
  -group [get_clocks -include_generated_clocks clk100] \
  -group [get_clocks bclk]

set_bus_skew -from [get_cells -hierarchical -filter {NAME =~ *cdc_pick/hold_reg*}] \
             -to   [get_cells -hierarchical -filter {NAME =~ *cdc_pick/dst_data_reg*}] 81.380

# Asynchronous inputs (buttons, MIDI): do not time their capture edge.
set_false_path -from [get_ports {btn[*] sw[*] midi_rx}]

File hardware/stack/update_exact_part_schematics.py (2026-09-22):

#!/usr/bin/env python3
from pathlib import Path
import re
D=Path('/home/ik/ChatGPT/Courant/hardware/panel/design')

def replace_count(path,old,new,count):
    p=D/path;s=p.read_text();n=s.count(old)
    if n!=count: raise RuntimeError(f'{path}: {old!r} count {n}, expected {count}')
    p.write_text(s.replace(old,new))
    return n

# Exact drop-in production connectors.
replace_count('power.kicad_sch','"EURORACK 10 PIN"','"61201021621"',2)
replace_count('power.kicad_sch','"RadianPanel:IDC_2x05_P2.54_Shrouded"','"RadianPanel:Wurth_61201021621_Exact_B"',2)
replace_count('power.kicad_sch','"SELECT keyed 2x05 IDC 2.54 mm header"','"61201021621"',1)

replace_count('power.kicad_sch','"DESKTOP 12 V INPUT"','"22-27-2021"',2)
replace_count('power.kicad_sch','"RadianPanel:Header_1x02_P2.54"','"RadianPanel:Molex_22-27-2021_J201_B"',2)
replace_count('power.kicad_sch','"SELECT locking 2-pin >=2A connector; P2.54 footprint"','"22-27-2021"',1)

replace_count('io.kicad_sch','"TO OFF-BOARD MIDI DIN"','"22-27-2021"',2)
replace_count('io.kicad_sch','"RadianPanel:Header_1x02_P2.54"','"RadianPanel:Molex_22-27-2021_J306_B"',2)
replace_count('io.kicad_sch','"SELECT 2.54 mm 1x02 header"','"22-27-2021"',1)

replace_count('service.kicad_sch','"JTAG SERVICE"','"22-27-2061"',2)
replace_count('service.kicad_sch','"RadianPanel:Header_1x06_P2.54"','"RadianPanel:Molex_22-27-2061_J202_B"',2)
replace_count('service.kicad_sch','"SELECT 2.54 mm 1x06 header"','"22-27-2061"',1)

# JP1: actual Wurth SPDT pinout. Old schematic positions top/middle/bottom were
# pins 1/2/3 = MOD_RAW/MOD_IN/MOD_BIPOLAR. Actual switch is:
# pin 3 = top MOD_RAW, pin 1 = middle common MOD_IN, pin 2 = bottom MOD_BIPOLAR.
p=D/'mod.kicad_sch';s=p.read_text()
s=s.replace('"MOD RANGE: 1-2 UNI / 2-3 BI"','"450301014042"')
s=s.replace('"RadianPanel:Header_1x03_P2.54"','"RadianPanel:Wurth_450301014042_Exact_B"')
s=s.replace('"2.54 mm 1x03 header + removable shunt"','"450301014042"')
# Symbol definition: edit the three pins by their fixed locations.
start=s.index('(symbol "JP1_1_1"'); end=s.index('(property "Description"',start)
block=s[start:end]
for at,num in [('(at -12.7 2.54 0)','3'),('(at -12.7 0.0 0)','1'),('(at -12.7 -2.54 0)','2')]:
    i=block.index(at); j=block.find('(pin passive line',i+1); j=len(block) if j<0 else j
    seg=block[i:j]
    seg=re.sub(r'\(name "[123]"',f'(name "{num}"',seg)
    seg=re.sub(r'\(number "[123]"',f'(number "{num}"',seg)
    block=block[:i]+seg+block[j:]
s=s[:start]+block+s[end:]
# Instance pin UUIDs follow the same fixed graphical positions.
mapping={
 '031fc1de-f652-56e7-993b-2ddd33f1cf5b':'3',
 'a988563f-0536-5d32-9cf9-0b06dc0ab031':'1',
 '4b7ea1de-3e57-5a72-ba4b-1ca26cb4b4f4':'2'}
for uid,num in mapping.items():
    s=re.sub(r'\(pin "[123]"\s*\(uuid "'+re.escape(uid)+r'"\)\)',f'(pin "{num}"\n      (uuid "{uid}"))',s,count=1)
s=s.replace('DEFAULT: shunt JP1 pins 1-2 = direct unipolar MOD; preserve existing firmware interpretation.',
            'JP1 is an SPDT configuration switch: one throw selects direct unipolar MOD_RAW; the other selects MOD_BIPOLAR.')
p.write_text(s)
print('schematics updated for exact service parts')

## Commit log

2026-06-30 Add Python FDTD reference model for 2D lossy wave equation (closes #2)
    Implements model/fdtd_ref.py: a NumPy explicit-difference solver for the
    2D lossy wave equation from README §1.
    u[i,j]^{n+1} = a0*(2*u^n - sigk1*u^{n-1} + gamma^2*Lap(u^n))
    Key details:
    - Supports fixed (Dirichlet u=0) and free (Neumann du/dn=0) boundaries via
    numpy pad modes "constant" and "reflect" — clean one-liner step().
    - CFL guard raises at construction time if gamma^2 > 0.5.
    - Gaussian strike at grid centre; stereo pickup taps at NX/4 and 3*NX/4.
    - Default params (c=144 m/s, 32×32, fs=48 kHz, σ=1.5) give gamma^2=0.09,
    a ~440 Hz pitched impulse response, and ~17× amplitude decay over 2 s.
    - Saves norm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
2026-06-30 Add CFL stability sweep and gamma2_max recommendation (closes #3)
    model/stability_study.py sweeps gamma^2 in [0.10, 0.70] around the
    theoretical 2D CFL boundary (0.5), running a 100 ms undamped simulation
    per point and classifying stable vs. divergent.
    Findings:
    - Stable through gamma^2 = 0.5010 (floating-point boundary)
    - Divergence onset at gamma^2 = 0.510 (4.5 ms to blow-up)
    - Blow-up time shrinks to 1.0 ms at gamma^2 = 0.70
    - Recommended gamma2_max = 0.451 (10% below empirical limit)
    leaves 0.049 headroom for the alpha*u^2 non-linear stiffening term
    (README §2) before the hard clamp engages
    Outputs: model/outputs/cfl_sweep_envelope.png
    model/outputs/cfl_classi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
2026-06-30 Port reference model and stability study from Python to MATLAB/Octave
    Replaces all Python with MATLAB at the user's request. The numerics are a
    faithful port — verified against the previous Python reference within int16
    quantization noise (max 2 LSB / 32767 on the fixed boundary, 1 LSB on free),
    so the model remains a valid golden reference for later RTL comparison.
    New files:
    - model/Mesh2D.m handle class: explicit centred-difference node
    update (README §1), fixed (Dirichlet) and free
    (Neumann, reflect-ghost) boundaries
    - model/fdtd_ref.m driver: Gaussian strike, stereo pickups, stereo
    16-bit W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
2026-06-30 Add node_update function to fdtd_pkg (closes #7)
    Implements the core per-node explicit update as a pure function in fdtd_pkg
    (README §1, linear case), composed from the saturating helpers from #6:
    u^{n+1} = a0 * ( 2*u^n - sigk1*u^{n-1}
    + gamma2*(uN+uS+uE+uW - 4*u^n) )
    src/rtl/fdtd_pkg.vhd:
    - neighbours_t / coeffs_t records (N/S/E/W and gamma2/a0/sigk1)
    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
2026-06-30 Add node_element.vhd: single-node processing element (closes #8)
    The per-node PE of README §3: state registers u^n / u^{n-1}, the Q1.23
    update (node_update from fdtd_pkg) spread across a 3-stage pipeline, and
    N/S/E/W neighbour ports.
    src/rtl/node_element.vhd:
    - ports: clk, rst (sync, reset to rest), strobe, coeffs, nb (N/S/E/W),
    u_out (current u^n for neighbours/pickups), valid (1-cycle commit pulse).
    - 3-stage pipeline, one signed multiply per stage so each maps cleanly to
    a DSP slice with registered operands and result:
    s1: Laplacian sum, sigk1*u^{n-1}, 2*u^n (capture inputs)
    s2: gamma2*lap, 2u - sigk1*u1 + gamma2*lap
    s3: a0*(...), saturate, commit u^n/u^{n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
2026-06-30 node_element_tb: trace-driven unit test vs reference model (closes #9)
    Replaces the #8 smoke test with a rigorous, trace-driven unit test that
    checks the PE bit-for-bit against a golden trajectory exported from the
    Q1.23 reference model (model/QMesh2D.m), over many steps.
    src/tb/node_element_trace.txt:
    - 100-step recorded neighbour trace + golden output for an interior node
    that starts at REST and is driven entirely by its neighbours (so a fresh
    PE replaying the neighbours reproduces the trajectory exactly; verified
    PE==reference during generation).
    - deliberately includes 2 saturation events and 7 full-scale (max-amplitude)
    neighbour samples for edge coverage.
    src/tb/n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
2026-06-30 Add grid_mesh.vhd: parameterisable NX x NY structural mesh (closes #10)
    Wires the single-node PEs into the 2D fabric of README §3.
    src/rtl/grid_mesh.vhd:
    - NX/NY generics; one node_element per grid point.
    - Structural N/S/E/W neighbour wiring via if-generate, with boundary
    handling: FREE_BOUNDARY=false -> Dirichlet (off-grid reads 0);
    FREE_BOUNDARY=true -> Neumann reflect (off-grid mirrors the inward
    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
2026-06-30 Validate fixed and free boundary modes vs reference (closes #11)
    The boundary mechanism itself landed with the mesh (#10): grid_mesh has a
    FREE_BOUNDARY generic that wires off-grid neighbours to 0 (Dirichlet, fixed)
    or mirrors the inward neighbour (Neumann reflect, free), matching the
    reference model's boundary convention. This change adds the missing piece -
    bit-for-bit validation of BOTH modes against the reference (model/QMesh2D.m).
    src/tb/boundary_tb.vhd:
    - instantiates two 6x6 grid_mesh DUTs, fixed and free, driven by the same
    single-node excitation impulse.
    - pickups at opposite corners (0,0) and (5,5) so all four edges (N/W and
    S/E) are exercised.
    - compares both corner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
2026-06-30 Validate stereo pickup taps: distinct, routed, configurable (closes #12)
    The stereo pickup mechanism landed with the mesh (#10): grid_mesh exposes
    pick_l / pick_r driven from two parameterisable node coordinates
    (PICK_LX/PICK_LY, PICK_RX/PICK_RY), default (NX/4, NY/2) and (3*NX/4, NY/2)
    on the centre row. This change adds the validation.
    src/tb/pickup_tb.vhd:
    - two 8x8 grid_mesh DUTs with identical dynamics but different tap generics:
    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
2026-06-30 Add mesh impulse-response and linear-physics validation TB (closes #13)
    The M2 capstone: validates the wired mesh reproduces the expected linear
    physics against the reference model.
    src/tb/mesh_impulse_tb.vhd:
    - strikes a symmetric 9x9 mesh at its centre (default generics put the
    excitation at (4,4) and the pickups at the mirror nodes (4,2),(4,6)) and
    captures the impulse response over 128 steps.
    - check 1: stereo pickups bit-for-bit vs the Q1.23 reference (QMesh2D). The
    Q1.23 mesh matches the float reference to ~97 dB SNR at the pickup
    (measured in model/, well within the ~66 dB Q1.23 error budget from #4).
    - check 2: symmetry. A centred strike on a left/right-symmetr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
2026-06-30 Add amplitude-dependent gamma^2 with CFL-safe clamp (closes #14)
    Turns on the non-linearity (README §2): the local stiffness becomes
    amplitude-dependent and is clamped below the CFL limit so hard strikes bend
    pitch up and bloom into inharmonic partials, then decay, instead of diverging.
    gamma2_local = clamp(gamma0^2 + alpha*u^2, 0, gamma2_max)
    u^{n+1} = a0*(2u - sigk1*u1 + gamma2_local*(uN+uS+uE+uW - 4u))
    - coeffs_t gains `alpha` and `gamma2_max` (README §3 control bus).
    - node_update computes u^2 (saturating q_mul), alpha*u^2, and the clamped
    gamma2_local, then scales the Laplacian by it. With alpha=0 and
    gamma2_max>=gamma2 it reduces exactly t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
2026-06-30 Add oversampling and decimation path (closes #15)
    Mitigates the aliasing from the squaring non-linearity (README §2) by running
    the mesh at OS x the audio rate and decimating on output.
    src/rtl/mesh_resonator.vhd:
    - wraps grid_mesh with an oversampling sequencer (FSM) that issues OS mesh
    strobes per audio frame, injecting the excitation on the first oversampled
    step, and a boxcar/CIC-1 decimator that averages the OS pickup samples into
    one audio sample (out_l/out_r, out_valid).
    - integer OS generic (quality/area knob). The 1/OS average is a compile-time
    constant multiply, so no runtime divider is instantiated. Coefficients are
    supplied precomputed for the oversample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
2026-06-30 Add aliasing and chaos characterisation study (closes #16)
    Characterises the non-linear regime (README §2) under the same Q1.23
    saturating arithmetic as the RTL.
    model/chaos_study.m: four analyses
    1. THD vs alpha and drive amplitude (harmonics from the squaring): grows
    smoothly from ~2% to ~6%, jumping into broadband once the bifurcation
    band is entered.
    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
2026-06-30 Add i2s_transceiver.vhd: I2S RX/TX (closes #17)
    Audio in/out over standard (Philips) I2S (README §3 Interfaces, §5).
    src/rtl/i2s_transceiver.vhd:
    - I2S slave: BCLK and LRCLK are inputs; WS='0' left, '1' right; MSB-first
    with the one-BCLK delay after each WS edge.
    - RX (serial->parallel): captures the incoming stereo sample; rx_l is the
    mallet excitation, rx_valid pulses once per L+R frame. Samples SD on the
    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
2026-06-30 Add sample-strobe generation from the I2S word clock (closes #18)
    The mesh advances one time-step per audio sample, strobed from the I2S word
    clock across the clock-domain boundary (README §3, CDC).
    src/rtl/sample_strobe.vhd:
    - crosses LRCLK from the audio domain into the system-clock domain with a
    two-flop synchroniser and rising-edge detection, emitting a clean
    one-cycle `frame` pulse once per audio sample (f_s).
    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
2026-06-30 Add clock-domain crossing between I2S and mesh core (closes #19)
    Safely moves audio data across the I2S <-> mesh clock boundary (README §3):
    the excitation sample (I2S domain -> mesh) and the L/R pickups (mesh ->
    I2S domain), one word per audio frame, with no loss or corruption.
    src/rtl/cdc_word.vhd:
    - reusable WIDTH-bit one-word CDC. MCP / "synchronised flag + stable data":
    src latches the word into a holding register and toggles a 1-bit request;
    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
2026-06-30 Add control / register bus for precomputed coefficients (closes #20)
    A control-rate register file holding the precomputed coefficients and pickup
    tap locations, distributed to the mesh (README §3 control bus, §4).
    src/rtl/control_bus.vhd:
    - register map (4-bit addr, 24-bit Q1.23 data): gamma2 (gamma0^2), a0,
    sigk1, alpha, gamma2_max, and the four pickup-tap coordinates.
    - simple synchronous bus: write port (wr_en/wr_addr/wr_data) and a
    registered read-back port. Drives a coeffs_t and the tap coordinates out
    continuously; the mesh samples them when it strobes (same clock domain,
    control-rate writes stable across a per-frame step).
    - resets to a safe linear operating p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
2026-06-30 Add top_resonator.vhd: end-to-end integration (closes #21)
    One entity tying the whole engine together (README §3, §5):
    I2S RX -> CDC -> oversampled non-linear mesh -> CDC -> I2S TX,
    with a control/register bus supplying the precomputed coefficients.
    src/rtl/top_resonator.vhd:
    - instantiates i2s_transceiver, control_bus, mesh_resonator (which wraps
    grid_mesh), and two cdc_word crossings.
    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
2026-06-30 Add end-to-end system impulse-response & stability test (closes #22)
    Upgrades top_resonator_tb from the #21 smoke test to the rigorous M5 system
    test (README §5, §6).
    src/tb/top_resonator_tb.vhd:
    - drives the whole top_resonator over a real I2S serial link (a second
    i2s_transceiver as codec feeds the DUT and captures its output).
    - check 1, impulse response vs reference: reference coefficients on the
    control bus, a single-frame excitation impulse, and the captured I2S
    output compared bit-for-bit against the oversampled-mesh + decimation
    golden (top_impulse_trace.txt). A sliding match auto-aligns to the fixed
    I2S/CDC latency; every stage is independently lossless/bi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
2026-06-30 Add Arty A7 synthesis flow and resource budget (closes #23)
    Reproducible synthesis flows and a measured resource budget for the Arty A7
    (Artix-7), with the fully-spatial vs time-multiplexed analysis (README §3, §6).
    syn/yosys/report_util.sh:
    - open-source flow (yosys synth_xilinx -family xc7 via the ghdl plugin) that
    maps the RTL to Artix-7 primitives and reports DSP48E1/LUT/FF per unit.
    This produced the budget numbers; runs without a Vivado licence.
    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
2026-06-30 Timing closure: XDC constraints, CDC, and pipeline rationale (#25)
    Constrain clocks/IO and document closing timing at 100 MHz on the Arty
    A7 + Pmod I2S2 (M6).
    - arty_a7.xdc: real Arty A7 + Pmod JA pin LOCs for the I2S2 codec; the
    two independent clocks (sys_clk 100 MHz, bclk 12.288 MHz); I2S I/O
    delays; and the clock-domain crossing constrained to match the
    cdc_word MCP handshake: async clock group (false path on the crossing)
    plus set_bus_skew per direction so the multi-bit word cannot tear, and
    a false path off the async reset. Documents the set_false_path /
    set_max_delay -datapath_only alternative.
    - build_arty.tcl: extend to a full opt/place/route flow with a pass/fail
    tim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
    [arty_a7.xdc]
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2026-07-01 Stretch: bending-stiffness / anisotropy study + go/no-go (#31)
    Reference-model exploration of advanced materials beyond the ideal
    membrane (milestone M9): a 4th-order bending-stiffness term (bars,
    plates, bells) and anisotropic propagation. Model + analysis + docs; no
    RTL change (this is the study that produces the RTL recommendation).
    - StiffMesh2D.m: membrane + biharmonic stiffness (13-point stencil) +
    anisotropic wave speed (cx != cy). Reduces bit-for-bit to Mesh2D when
    stiffness is off (verified: max diff 1.4e-14 over 400 steps).
    - stiffness_study.m: (A) confirms the von-Neumann stability bound
    (g2x+g2y)+16*mu2 <= 1 against a sweep (empirical == predicted at every
    point); (B) re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
2026-07-01 Stretch: spatial parameter variation study + go/no-go (#32)
    Reference-model exploration of per-node / per-region coefficient maps
    (milestone M9): a damped rim, a tension gradient, a stiffer centre.
    Model + analysis + docs; no RTL change.
    - VarMesh2D.m: gamma2/a0/sigk1 as per-node maps instead of scalars.
    CFL is local (max gamma2 <= 1/2); uniform maps reduce bit-for-bit to
    Mesh2D (verified: max diff 0 over 400 steps).
    - spatial_study.m: (A) reduce-to-Mesh2D check; (B) three profiles vs a
    uniform baseline with measured decay time + spectral centroid:
    radial damping cuts decay 693 -> 214 ms and darkens the tone
    (centroid 1249 -> 800 Hz); a tension gradient brightens it
    (centroid ->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
2026-07-01 Stretch: physical exciter front-ends (mallet / bow) study (#33)
    Reference-model exploration of replacing the raw single-sample strike
    with physical exciter models (milestone M9): a hardness/velocity
    sensitive mallet and a bow/friction driver. Model + analysis + docs; no
    RTL change.
    - Exciter.m: a stateful, bidirectional exciter on one node. 'mallet' is a
    lumped mass-spring contact (F = k*[uh-us]_+^p; hardness = k); 'bow' is a
    friction driver (F = Fn*mu(vrel) with a velocity-weakening curve). Each
    step reads the node displacement and returns a force to inject.
    - exciter_study.m: (A) mallet hardness sweep, harder -> shorter contact
    (2.29/1.08/0.69 ms) -> brighter (centroid 422/668/102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
2026-07-01 Wire preset_bank into top_resonator (#69)
    Replace control_bus with its superset preset_bank in top_resonator, so
    presets are reachable in the wired design, and expose the preset controls
    on the top-level interface.
    - top_resonator.vhd: instantiate preset_bank instead of control_bus; add
    preset_index / preset_recall / preset_save ports (defaulted to a no-op
    so instantiations that only use the register port are unaffected). The
    coefficient reset defaults are unchanged (preset_bank's DEF_PRESET
    matches the old control_bus defaults), so behaviour is preserved.
    - preset_top_tb.vhd: drives only the control port and confirms the reset
    default matches, factory presets (gong, drum) recall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
2026-07-01 Non-linear reference model (alpha chaos term) in Octave (#71)
    Brings the reference model up to the RTL's non-linear path (README §2),
    so model-vs-RTL comparison and the demos are representative instead of
    relying on the linear Mesh2D.
    - NLMesh2D.m: float non-linear mesh. Adds the amplitude-dependent local
    stiffness gamma2_local = clamp(gamma0^2 + alpha*u^2, 0, gamma2_max) and
    the Q1.23-rail saturation (mirroring the RTL sat_store, which is part of
    what bounds the non-linear scheme). Reduces to Mesh2D when alpha = 0.
    - nl_reference.m: verification. A Q1.23 fixed-point emulation of the RTL
    node update (mirroring fdtd_pkg: q_mul/mul_coeff round >>23, saturate,
    clamp) is run on the s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
2026-07-01 Synthesis/build path for synth_top (Vivado + MMCM + XDC) (#76)
    Make the flagship playable design buildable/flashable for the Arty A7;
    until now only the older top_resonator had a build flow.
    - arty_synth.vhd: board wrapper around synth_top (#68). An MMCM turns the
    100 MHz oscillator into sys_clk (100 MHz) and the audio master clock
    mclk (~12.2888 MHz, ~65 ppm; drop in a Clocking Wizard or external
    12.288 osc for exact); buttons/switches drive reset + preset controls,
    active-voice LEDs. Instantiates the Xilinx MMCME2_BASE primitive, so it
    is SYNTHESIS-ONLY and lives under syn/ (the GHDL flow globs src/rtl and
    stays vendor-neutral; synth_top itself is simulated in synth_top_tb).
    -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
    [arty_synth.xdc]
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2026-07-01 Panel controller: knobs/encoder to the engine (#78)
    Wire the physical front panel to the engine: three macro pots set the
    live coefficients and a rotary encoder + button select/recall presets,
    all via the preset_bank register/preset interface (#30, #69).
    - panel_ctrl.vhd:
    * pot_pitch -> gamma2 (reg 0), pot_decay -> sigk1 (reg 2) + a0 (reg 1),
    pot_timbre -> alpha (reg 3). Each pot is scaled into the register's
    Q1.23 range and written on change only: a scanner does one register
    per clock and rewrites only past a dead-band (rejects ADC jitter), so
    the single-port bus is never flooded.
    * encoder A/B -> preset_index (one step per A rising edge, direction
    fr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
2026-07-03 docs: tighten README and refresh to feature-complete state
    Rewrite the README to be more concise (219 lines removed, 92 added) and
    accurate to the current repo. The old copy was stale: "Status: pre-silicon"
    and a "Repository structure (planned)" tree that predated MIDI/CV, polyphony,
    presets, the panel, and synth_top.
    The new README:
    - opens with a crisp one-paragraph description (2D wave equation solved on an
    FPGA mesh, nonlinear stiffening, playable polyphonically over MIDI/CV with
    presets),
    - marks status "simulation-first, feature-complete in sim, pre-hardware"
    (engine + bit-exact Q1.23 reference model + playable top verified in GHDL,
    23 testbenches; board bring-up next),
    - cond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
2026-09-22 chore: preserve desktop Courant source and hardware configuration
    [BOM.csv, RADIAN_P1_fit_template.stl, RADIAN_panel_P1_outline_reference.dxf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]
2026-10-01 docs: add sound demos, board renders and 3D models to the READMEs
    - docs/media/: demo clips (mp3 + spectrogram mp4), a linear-vs-chaos A/B
    strike, spectrograms, an animated mesh comparison, solder-mask views of
    both native KiCad boards, 3D renders, and the mated stack as STL (GitHub
    3D viewer) and coloured glTF.
    - docs/media/scripts/make_media.sh regenerates everything from model/ and
    the native .kicad_pcb files; nlmesh.py is checked against Octave's
    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
    [courant_stack.stl]
2026-10-01 docs: refresh READMEs for the RADIAN name and current hardware status; fix CI
    - Use RADIAN as the project name in README prose (the "Courant number"
    maths term is unchanged) and note the repo still carries the old name.
    - §9/§10 were stale: the board carries an XC7A50T, both boards are fully
    routed with KiCad DRC 0/0, and the MCP3208 ADC reader exists and is tested.
    - Commit the mallet and stiffness golden traces. /src/tb/*_trace.txt in
    .gitignore kept them out of git, so mallet_tb failed in CI. Both were
    regenerated from model/*_reference.py and are byte-identical.
2026-10-01 docs(media): replace float-model demos with RTL-captured sound demos
    The old gong/plate/drum clips came from the pre-repair float model and
    faded out or went silent after about 3 s. The new clips are 10 s phrases
    captured from synth_top's I2S output in a cycle-accurate Verilator build
    of the repaired 2026-09-16 RTL (4 voices, 8x8, OS=4, TIME_MUX), driven by
    bit-level serial MIDI. One constant gain per clip to -1 dBFS, nothing else.
    - scores/: the three serial-MIDI stimuli and their summaries
    - scripts/rtl/build_renderer.sh: GHDL synth -> Verilator renderer from the
    current RTL; scripts/rtl_media.py: capture -> wav/mp3/spectrogram/mp4
    - mesh_media.py: artist tag and spectrogram range are p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
2026-10-01 docs(media): four polyphonic RTL sound demos
    Gong Chorale, Plate Arpeggio, Mallet Groove and Chaos Swell, captured from
    synth_top's I2S output in the same Verilator build of the repaired
    2026-09-16 RTL. Unlike the first three clips (one voice at a time) these
    hold notes across 3-4 voices; Chaos Swell turns CHAOS up and down live
    over the control bus under a held gong chord.
    scripts/rtl/make_scores.py writes the scores; rtl_media.py now skips
    clips whose capture is missing and takes a spectrogram range per clip.
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
